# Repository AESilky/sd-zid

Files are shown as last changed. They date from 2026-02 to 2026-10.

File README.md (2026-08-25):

# ZID - Z80 In-circuit Debugger (ICD) and Single Board Computer (SBC)

The Z80 In-circuit-Debugger is intended to provide in-circuit (hardware and software) debugging functionality
for a Z80 based system.

## Features (ICD)

The debugger probe plugs in in place of the Z80. The debugger provides:

1. 20MHz operation. This allows debugging high speed boards. The actual 'top-speed' of the target depends on how tight the timing of the target board is, but debugging 16MHz targets should be handled without problems. Some boards might need the clock speed reduced for debugging.
2. Compact probe that connects via a small 40-pin FFC/FPC cable
3. Four probe configurations that allow the cable to exit in different directions (probe in different orientations)
4. Breakpoint and Single-Step hardware. Steps code and stops code execution when specified conditions are met, even with code in read-only memory (see below for details)
5. Breakpoint hardware allows checking two different conditions. For example; Port Write and Instruction Fetch
6. One breakpoint condition or the other can includes the ability to not only check the operation but also a data value, including Don't-Care bits.
7. Five breakpoint addresses total. One address on Condition A and Four addresses on Condition B (for example, a port read of a specific value with don't-care bits and 4 different instruction fetch locations)
8. Breakpoint conditions being met can either stop target code execution or simply provide a SYNC signal (can be used to trigger an oscilloscope/analyzer)
9. External breakpoint trigger allows stopping target code execution when some signal is generated externally
10. LED indicators for key Z80 control signals (WAIT, HALT, BUSACK)
11. Completely buffered/isolated target signals; meaning that:
    * Problems with the target hardware will not keep the debugger from running
    * Test features like, continuous memory or port write or read can be used to track down hardware problems or exercise new hardware
    * Z80 control signals on the target are held in an inactive state when not running target code or accessing target resources (debug mode). This can make it easier to debug target board hardware by quieting signals to allow getting an analyzer ready to capture an operation.
    * Z80 MREQ can optionally be passed to the target during refresh cycles when in debug mode (for that rare dynamic memory setup)
    * The target WAIT signal can be disconnected from the debugger to help debug hardware that is holding WAIT on
12. Switch that immediately runs the target system on boot/reset (no Debugger functionality is initialized and is not available)

## Breakpoint Conditions

The breakpoint logic allows selecting:

1. Instruction fetch from a specific address
2. Memory read from a specific address
3. Memory write to a specific address
4. Any memory operation (other than instruction fetch) on a specific address
5. Port (I/O) read from a specific address (16 or 8 bit address) or any address
6. Port write to a specific address (16 or 8 bit address) or any address
7. Any Port operation on a specific address (16 or 8 bit address) or any address
8. One breakpoint can also check for a specific data value for any operation except instruction fetch (for IF the data isn't valid soon enough, but a break could be set for Memory Read with the data value - it just breaks after the instruction execution)
9. The data value break also allows specifying Don't-Care bits. This allows breaking on a port write of a specific bit, for example.
10. 'Soft' breakpoint detection can be enabled. This allows generating a break by including a RST (8/38) in the code. When the RST is detected the hardware treats it as a break and enters Debug mode.

A fully populated ZID has:

1. One breakpoint address that uses Condition-A, that can specify a Data-Value, with Don't-Care bits
2. Four breakpoint addresses that share Condition-B (individually enabled)
3. All breakpoints are handled in hardware and don't require any modifications to the target system board or code

## High-Level Debug Monitor Description

This section provides a very high-level description of the Debug Monitor functionality. For complete information, see the ZID User Manual.

The user interface is through a USB port connected terminal (or terminal emulator).

1. Display the CPU registers
2. Set the value of CPU registers that will be used when code is run
3. Display the contents of memory
4. Modify the contents of RAM memory
5. Display data from an I/O port
6. Write data to an I/O port
7. Run code and break when one of two specified conditions are met:
   1. Breakpoint One and Two can be any of the conditions listed in the previous section, plus the ability to specify a data value that must match what is written/read, but allowing Don't-Care bits.
   2. Breakpoint Three through N (up to 8 total) share a condition that can be different from that of breakpoint One and Two.
8. Single-step code (even in ROM)
9. Perform operations that can be helpful in troubleshooting/repairing hardware problems, including:
   1. repetitive write of a specific data byte to a memory location
   2. repetitive read from a memory location
   3. repetitive write of a specific data byte to a port
   4. repetitive read from a port
   5. run a memory test using a number of different approaches (data patterns)
10. Additional functionality like:
    1. An HP-16C (like) calculator
    2. Selection of number base (Decimal, Hex, Octal, Binary (auto switches to Hex for certain operations))
    3. Entry of values in any base irrespective of the set base by using base indicators
    4. Store and recall multiple configurations that include the number base, breakpoint conditions, calculator register values, etc.

## Single Board Computer (SBC)

In addition to the Hardware Debugger, the board functions as an Single Board Computer (SBC). It's an SBC that:

1. has an MMU that bank switches 128K Flash (ROM) and 128K SRAM in 4 16K blocks (64K) from 8 regions of ROM and 8 regions of RAM.
2. none of the Debugger ROM/RAM need be available while running the SBC code (2K of Flash and 1K of RAM needs to be reserved for the Debugger from the upper region of the Flash and SRAM)
3. 4 output port bits that are available as buffered signals on a connector
4. 4 input port bits that are read from buffered signals on a connector
5. RP2040 module that provides:
   1. USB Terminal port
   2. eeprom storage
   3. RTC via I2C
   4. SD Card via SPI. The SD card can be used as CP/M disk.
6. runs at 20MHz with 0 wait states for RAM access, 1 wait state for Flash access, and 0 additional wait states for the 4-IN and 4-OUT port bits. The RP2040 modules adds various wait states depending on the operation.
7. the ability to use the debug probe cable and port I/O cable to connect to a 3 position RC2014-Z80 backplane.
   1. The RP2040 module interrupt signal can go to the backplane
   2. The backplane supports a bus-master accessing the SBC memory and ports
8. code and port operations can be completely debugged using the hardware debugger functionality without requiring any accommodations.

All of this is in a compact 3.5" x 5.0" board. The backplane is a 4.0" x 5.0" board with 3 RC2014-Z80 positions and includes a connector and port decoding for an OLED or TFT display panel. The backplane can be positioned on the same plane as the SBC or can be mouned back to back (the connecting cable makes a 'U'). Power is provided via a USB-C connection.

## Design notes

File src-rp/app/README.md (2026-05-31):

# Application (APP) functionality 

## APP

The APP consists of the display panel, rotary encoder (knob), and
attention switch. The hardware itself is under the control of the
Hardware Runtime, but the overall functionality of the interface
is controlled by this module.

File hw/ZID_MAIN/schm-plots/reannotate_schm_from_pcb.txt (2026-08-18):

Change C2 reference designator to 'C14'.
Change C8 reference designator to 'C29'.
Change C43 reference designator to 'C22'.
Change LED4 reference designator to 'LED7'.
Change J4 reference designator to 'J6'.
Change C42 reference designator to 'C19'.
Change U23 reference designator to 'U1'.
Change R16 reference designator to 'R21'.
Change R18 reference designator to 'R12'.
Change C31 reference designator to 'C3'.
Change U8 reference designator to 'U10'.
Change R39 reference designator to 'R32'.
Change C25 reference designator to 'C9'.
Change R26 reference designator to 'R17'.
Change U8 reference designator to 'U10'.
Change R11 reference designator to 'R7'.
Change C41 reference designator to 'C23'.
Change U20 reference designator to 'U14'.
Change LED2 reference designator to 'LED9'.
Change D2 reference designator to 'D4'.
Change J5 reference designator to 'J4'.
Change OP2 field 'OP-A' value to 'YES'.
Change OP2 field 'OP-B' value to 'NO'.
Change C6 reference designator to 'C28'.
Change R10 reference designator to 'R13'.
Change U24 reference designator to 'U16'.
Change R5 reference designator to 'R25'.
Change C26 reference designator to 'C11'.
Change LED10 reference designator to 'LED3'.
Change TP1 reference designator to 'TP2'.
Change R9 reference designator to 'R30'.
Change R42 reference designator to 'R37'.
Change J6 reference designator to 'J11'.
Change U10 reference designator to 'U19'.
Change C9 reference designator to 'C30'.
Change R28 reference designator to 'R20'.
Change LED3 reference designator to 'LED6'.
Change D1 reference designator to 'D3'.
Change R17 reference designator to 'R9'.
Change U11 reference designator to 'U23'.
Change J1 reference designator to 'J2'.
Change C44 reference designator to 'C37'.
Change R30 reference designator to 'R5'.
Change C39 reference designator to 'C27'.
Change U6 reference designator to 'U21'.
Change R27 reference designator to 'R19'.
Change JP1 reference designator to 'JP3'.
Change U3 reference designator to 'U4'.
Change R22 reference designator to 'R40'.
Change U24 reference designator to 'U16'.
Change LED5 reference designator to 'LED8'.
Change R8 reference designator to 'R33'.
Change C33 reference designator to 'C18'.
Change R20 reference designator to 'R39'.
Change R13 reference designator to 'R10'.
Change R14 reference designator to 'R22'.
Change R3 reference designator to 'R15'.
Change C34 reference designator to 'C16'.
Change LED6 reference designator to 'LED4'.
Change C23 reference designator to 'C4'.
Change U1 reference designator to 'U11'.
Change R6 reference designator to 'R14'.
Change C46 reference designator to 'C17'.
Change D4 reference designator to 'D1'.
Change U8 reference designator to 'U10'.
Change R37 reference designator to 'R3'.
Change U14 reference designator to 'U6'.
Change C29 reference designator to 'C24'.
Change JP2 reference designator to 'JP1'.
Change JP6 reference designator to 'JP4'.
Change H2 reference designator to 'H3'.
Change C5 reference designator to 'C2'.
Change R34 reference designator to 'R35'.
Change J3 reference designator to 'J1'.
Change D3 reference designator to 'D2'.
Change C28 reference designator to 'C33'.
Change U21 reference designator to 'U20'.
Change R2 reference designator to 'R11'.
Change TP14 reference designator to 'TP12'.
Change R29 reference designator to 'R18'.
Change R7 reference designator to 'R28'.
Change U16 reference designator to 'U24'.
Change R32 reference designator to 'R26'.
Change C45 reference designator to 'C21'.
Change U24 reference designator to 'U16'.
Change H4 reference designator to 'H2'.
Change C10 reference designator to 'C36'.
Change JP3 reference designator to 'JP2'.
Change R41 reference designator to 'R1'.
Change R23 reference designator to 'R38'.
Change U10 reference designator to 'U19'.
Change U11 reference designator to 'U23'.
Change U23 reference designator to 'U1'.
Change J14 reference designator to 'J12'.
Change TP16 reference designator to 'TP15'.
Change R21 reference designator to 'R41'.
Change R24 reference designator to 'R23'.
Change C49 reference designator to 'C12'.
Change U8 reference designator to 'U10'.
Change R35 reference designator to 'R2'.
Change U10 reference designator to 'U19'.
Change SBC1 reference designator to 'SBC2'.
Change R12 reference designator to 'R24'.
Change C7 reference designator to 'C25'.
Change LED9 reference designator to 'LED1'.
Change J11 reference designator to 'J3'.
Change U23 reference designator to 'U1'.
Change H3 reference designator to 'H4'.
Change C1 reference designator to 'C13'.
Change R38 reference designator to 'R31'.
Change TP15 reference designator to 'TP14'.
Change C22 reference designator to 'C6'.
Change R19 reference designator to 'R36'.
Change U17 reference designator to 'U8'.
Change JP7 reference designator to 'JP6'.
Change R15 reference designator to 'R8'.
Change U7 reference designator to 'U9'.
Change R31 reference designator to 'R16'.
Change C27 reference designator to 'C7'.
Change U2 reference designator to 'U17'.
Change C24 reference designator to 'C10'.
Change R33 reference designator to 'R4'.
Change C47 reference designator to 'C32'.
Change U21 reference designator to 'U20'.
Change LED8 reference designator to 'LED5'.
Change C21 reference designator to 'C5'.
Change C40 reference designator to 'C8'.
Change SBC2 reference designator to 'SBC1'.
Change R36 reference designator to 'R29'.
Change LED1 reference designator to 'LED10'.
Change R44 reference designator to 'R42'.
Change U9 reference designator to 'U7'.
Change J2 reference designator to 'J5'.
Change C50 reference designator to 'C15'.
Change U4 reference designator to 'U3'.
Change C32 reference designator to 'C20'.
Change U8 reference designator to 'U10'.
Change U11 reference designator to 'U23'.
Change U19 reference designator to 'U12'.
Change C3 reference designator to 'C38'.
Change C11 reference designator to 'C35'.
Change U23 reference designator to 'U1'.
Change C20 reference designator to 'C1'.
Change U23 reference designator to 'U1'.
Change JP4 reference designator to 'JP5'.
Change C4 reference designator to 'C34'.
Change R4 reference designator to 'R27'.
Change TP12 reference designator to 'TP1'.
Change U8 reference designator to 'U10'.
Change C48 reference designator to 'C31'.
Change R1 reference designator to 'R6'.
Change R40 reference designator to 'R34'.
Change C30 reference designator to 'C26'.
Change U21 reference designator to 'U20'.
Change LED7 reference designator to 'LED2'.
Change U12 reference designator to 'U2'.
Change U8 reference designator to 'U10'.
Change C2 reference designator to 'C14'.
Change C8 reference designator to 'C29'.
Change C43 reference designator to 'C22'.
Change LED4 reference designator to 'LED7'.
Change J4 reference designator to 'J6'.
Change C42 reference designator to 'C19'.
Change U23 reference designator to 'U1'.
Change R16 reference designator to 'R21'.
Change R18 reference designator to 'R12'.
Change C31 reference designator to 'C3'.
Change U8 reference designator to 'U10'.
Change R39 reference designator to 'R32'.
Change C25 reference designator to 'C9'.
Change R26 reference designator to 'R17'.
Change U8 reference designator to 'U10'.
Change R11 reference designator to 'R7'.
Change C41 reference designator to 'C23'.
Change U20 reference designator to 'U14'.
Change LED2 reference designator to 'LED9'.
Change D2 reference designator to 'D4'.
Change J5 reference designator to 'J4'.
Change OP2 field 'OP-A' value to 'YES'.
Change OP2 field 'OP-B' value to 'NO'.
Change C6 reference designator to 'C28'.
Change R10 reference designator to 'R13'.
Change U24 reference designator to 'U16'.
Change R5 reference designator to 'R25'.
Change C26 reference designator to 'C11'.
Change LED10 reference designator to 'LED3'.
Change TP1 reference designator to 'TP2'.
Change R9 reference designator to 'R30'.
Change R42 reference designator to 'R37'.
Change J6 reference designator to 'J11'.
Change U10 reference designator to 'U19'.
Change C9 reference designator to 'C30'.
Change R28 reference designator to 'R20'.
Change LED3 reference designator to 'LED6'.
Change D1 reference designator to 'D3'.
Change R17 reference designator to 'R9'.
Change U11 reference designator to 'U23'.
Change J1 reference designator to 'J2'.
Change C44 reference designator to 'C37'.
Change R30 reference designator to 'R5'.
Change C39 reference designator to 'C27'.
Change U6 reference designator to 'U21'.
Change R27 reference designator to 'R19'.
Change JP1 reference designator to 'JP3'.
Change U3 reference designator to 'U4'.
Change R22 reference designator to 'R40'.
Change U24 reference designator to 'U16'.
Change LED5 reference designator to 'LED8'.
Change R8 reference designator to 'R33'.
Change C33 reference designator to 'C18'.
Change R20 reference designator to 'R39'.
Change R13 reference designator to 'R10'.
Change R14 reference designator to 'R22'.
Change R3 reference designator to 'R15'.
Change C34 reference designator to 'C16'.
Change LED6 reference designator to 'LED4'.
Change C23 reference designator to 'C4'.
Change U1 reference designator to 'U11'.
Change R6 reference designator to 'R14'.
Change C46 reference designator to 'C17'.
Change D4 reference designator to 'D1'.
Change U8 reference designator to 'U10'.
Change R37 reference designator to 'R3'.
Change U14 reference designator to 'U6'.
Change C29 reference designator to 'C24'.
Change JP2 reference designator to 'JP1'.
Change JP6 reference designator to 'JP4'.
Change H2 reference designator to 'H3'.
Change C5 reference designator to 'C2'.
Change R34 reference designator to 'R35'.
Change J3 reference designator to 'J1'.
Change D3 reference designator to 'D2'.
Change C28 reference designator to 'C33'.
Change U21 reference designator to 'U20'.
Change R2 reference designator to 'R11'.
Change TP14 reference designator to 'TP12'.
Change R29 reference designator to 'R18'.
Change R7 reference designator to 'R28'.
Change U16 reference designator to 'U24'.
Change R32 reference designator to 'R26'.
Change C45 reference designator to 'C21'.
Change U24 reference designator to 'U16'.
Change H4 reference designator to 'H2'.
Change C10 reference designator to 'C36'.
Change JP3 reference designator to 'JP2'.
Change R41 reference designator to 'R1'.
Change R23 reference designator to 'R38'.
Change U10 reference designator to 'U19'.
Change U11 reference designator to 'U23'.
Change U23 reference designator to 'U1'.
Change J14 reference designator to 'J12'.
Change TP16 reference designator to 'TP15'.
Change R21 reference designator to 'R41'.
Change R24 reference designator to 'R23'.
Change C49 reference designator to 'C12'.
Change U8 reference designator to 'U10'.
Change R35 reference designator to 'R2'.
Change U10 reference designator to 'U19'.
Change SBC1 reference designator to 'SBC2'.
Change R12 reference designator to 'R24'.
Change C7 reference designator to 'C25'.
Change LED9 reference designator to 'LED1'.
Change J11 reference designator to 'J3'.
Change U23 reference designator to 'U1'.
Change H3 reference designator to 'H4'.
Change C1 reference designator to 'C13'.
Change R38 reference designator to 'R31'.
Change TP15 reference designator to 'TP14'.
Change C22 reference designator to 'C6'.
Change R19 reference designator to 'R36'.
Change U17 reference designator to 'U8'.
Change JP7 reference designator to 'JP6'.
Change R15 reference designator to 'R8'.
Change U7 reference designator to 'U9'.
Change R31 reference designator to 'R16'.
Change C27 reference designator to 'C7'.
Change U2 reference designator to 'U17'.
Change C24 reference designator to 'C10'.
Change R33 reference designator to 'R4'.
Change C47 reference designator to 'C32'.
Change U21 reference designator to 'U20'.
Change LED8 reference designator to 'LED5'.
Change C21 reference designator to 'C5'.
Change C40 reference designator to 'C8'.
Change SBC2 reference designator to 'SBC1'.
Change R36 reference designator to 'R29'.
Change LED1 reference designator to 'LED10'.
Change R44 reference designator to 'R42'.
Change U9 reference designator to 'U7'.
Change J2 reference designator to 'J5'.
Change C50 reference designator to 'C15'.
Change U4 reference designator to 'U3'.
Change C32 reference designator to 'C20'.
Change U8 reference designator to 'U10'.
Change U11 reference designator to 'U23'.
Change U19 reference designator to 'U12'.
Change C3 reference designator to 'C38'.
Change C11 reference designator to 'C35'.
Change U23 reference designator to 'U1'.
Change C20 reference designator to 'C1'.
Change U23 reference designator to 'U1'.
Change JP4 reference designator to 'JP5'.
Change C4 reference designator to 'C34'.
Change R4 reference designator to 'R27'.
Change TP12 reference designator to 'TP1'.
Change U8 reference designator to 'U10'.
Change C48 reference designator to 'C31'.
Change R1 reference designator to 'R6'.
Change R40 reference designator to 'R34'.
Change C30 reference designator to 'C26'.
Change U21 reference designator to 'U20'.
Change LED7 reference designator to 'LED2'.
Change U12 reference designator to 'U2'.
Change U8 reference designator to 'U10'.

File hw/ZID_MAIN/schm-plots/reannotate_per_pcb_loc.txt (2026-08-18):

Info: <br/><br/>Front Footprints<br/>*********** Sort on Footprint Coordinates ***********<br/>1 H1 X, Y: 2.4524 in, 5.5600 in; rounded X, Y: 2.0000 in, 6.0000 in<br/>2 LED9 X, Y: 2.9274 in, 5.5900 in; rounded X, Y: 3.0000 in, 6.0000 in<br/>3 LED7 X, Y: 3.1774 in, 5.5900 in; rounded X, Y: 3.0000 in, 6.0000 in<br/>4 LED10 X, Y: 2.6774 in, 5.5900 in; rounded X, Y: 3.0000 in, 6.0000 in<br/>5 LED6 X, Y: 2.8024 in, 5.5900 in; rounded X, Y: 3.0000 in, 6.0000 in<br/>6 LED8 X, Y: 3.0524 in, 5.5900 in; rounded X, Y: 3.0000 in, 6.0000 in<br/>7 C20 X, Y: 3.6967 in, 5.6221 in; rounded X, Y: 4.0000 in, 6.0000 in<br/>8 LED3 X, Y: 5.8524 in, 5.5900 in; rounded X, Y: 6.0000 in, 6.0000 in<br/>9 LED4 X, Y: 5.7274 in, 5.5900 in; rounded X, Y: 6.0000 in, 6.0000 in<br/>10 LED5 X, Y: 5.6024 in, 5.5900 in; rounded X, Y: 6.0000 in, 6.0000 in<br/>11 LED2 X, Y: 5.9774 in, 5.5900 in; rounded X, Y: 6.0000 in, 6.0000 in<br/>12 LED1 X, Y: 6.1024 in, 5.5900 in; rounded X, Y: 6.0000 in, 6.0000 in<br/>13 SD1 X, Y: 6.5324 in, 5.6100 in; rounded X, Y: 7.0000 in, 6.0000 in<br/>14 H4 X, Y: 7.1724 in, 5.5600 in; rounded X, Y: 7.0000 in, 6.0000 in<br/>15 C5 X, Y: 3.2230 in, 5.2300 in; rounded X, Y: 3.0000 in, 5.0000 in<br/>16 SPARE1 X, Y: 3.4624 in, 4.9600 in; rounded X, Y: 3.0000 in, 5.0000 in<br/>17 R41 X, Y: 2.6774 in, 5.3400 in; rounded X, Y: 3.0000 in, 5.0000 in<br/>18 R35 X, Y: 3.0524 in, 5.3400 in; rounded X, Y: 3.0000 in, 5.0000 in<br/>19 U23 X, Y: 3.4224 in, 5.4800 in; rounded X, Y: 3.0000 in, 5.0000 in<br/>20 C31 X, Y: 2.6364 in, 5.1656 in; rounded X, Y: 3.0000 in, 5.0000 in<br/>21 R37 X, Y: 2.9274 in, 5.3400 in; rounded X, Y: 3.0000 in, 5.0000 in<br/>22 R33 X, Y: 3.1774 in, 5.3400 in; rounded X, Y: 3.0000 in, 5.0000 in<br/>23 R30 X, Y: 2.8024 in, 5.3400 in; rounded X, Y: 3.0000 in, 5.0000 in<br/>24 C23 X, Y: 4.0103 in, 5.1630 in; rounded X, Y: 4.0000 in, 5.0000 in<br/>25 C21 X, Y: 3.9571 in, 5.4642 in; rounded X, Y: 4.0000 in, 5.0000 in<br/>26 C22 X, Y: 4.3824 in, 5.3872 in; rounded X, Y: 4.0000 in, 5.0000 in<br/>27 G*** X, Y: 4.3394 in, 5.1947 in; rounded X, Y: 4.0000 in, 5.0000 in<br/>28 C27 X, Y: 4.7587 in, 4.9111 in; rounded X, Y: 5.0000 in, 5.0000 in<br/>29 C40 X, Y: 5.2135 in, 4.8531 in; rounded X, Y: 5.0000 in, 5.0000 in<br/>30 C25 X, Y: 5.3097 in, 5.2709 in; rounded X, Y: 5.0000 in, 5.0000 in<br/>31 C24 X, Y: 5.0798 in, 5.4744 in; rounded X, Y: 5.0000 in, 5.0000 in<br/>32 C26 X, Y: 5.2626 in, 5.1640 in; rounded X, Y: 5.0000 in, 5.0000 in<br/>33 C49 X, Y: 6.1830 in, 5.0900 in; rounded X, Y: 6.0000 in, 5.0000 in<br/>34 C1 X, Y: 6.3224 in, 4.6500 in; rounded X, Y: 6.0000 in, 5.0000 in<br/>35 R1 X, Y: 6.2824 in, 4.8500 in; rounded X, Y: 6.0000 in, 5.0000 in<br/>36 R11 X, Y: 6.1024 in, 5.3359 in; rounded X, Y: 6.0000 in, 5.0000 in<br/>37 R15 X, Y: 5.8524 in, 5.3359 in; rounded X, Y: 6.0000 in, 5.0000 in<br/>38 R17 X, Y: 5.7274 in, 5.3359 in; rounded X, Y: 6.0000 in, 5.0000 in<br/>39 JP2 X, Y: 6.2824 in, 4.9400 in; rounded X, Y: 6.0000 in, 5.0000 in<br/>40 R13 X, Y: 5.9774 in, 5.3359 in; rounded X, Y: 6.0000 in, 5.0000 in<br/>41 C2 X, Y: 6.4224 in, 4.9300 in; rounded X, Y: 6.0000 in, 5.0000 in<br/>42 U12 X, Y: 5.8524 in, 4.9700 in; rounded X, Y: 6.0000 in, 5.0000 in<br/>43 R2 X, Y: 6.4624 in, 4.5100 in; rounded X, Y: 6.0000 in, 5.0000 in<br/>44 R18 X, Y: 5.6024 in, 5.3359 in; rounded X, Y: 6.0000 in, 5.0000 in<br/>45 J3 X, Y: 7.1874 in, 5.0300 in; rounded X, Y: 7.0000 in, 5.0000 in<br/>46 U4 X, Y: 7.1324 in, 4.7450 in; rounded X, Y: 7.0000 in, 5.0000 in<br/>47 SW1 X, Y: 7.1324 in, 5.2600 in; rounded X, Y: 7.0000 in, 5.0000 in<br/>48 J1 X, Y: 6.9100 in, 4.9650 in; rounded X, Y: 7.0000 in, 5.0000 in<br/>49 R10 X, Y: 6.9774 in, 5.4600 in; rounded X, Y: 7.0000 in, 5.0000 in<br/>50 C50 X, Y: 6.7224 in, 5.0100 in; rounded X, Y: 7.0000 in, 5.0000 in<br/>51 R6 X, Y: 6.5524 in, 4.9600 in; rounded X, Y: 7.0000 in, 5.0000 in<br/>52 U3 X, Y: 6.5024 in, 4.7100 in; rounded X, Y: 7.0000 in, 5.0000 in<br/>53 R3 X, Y: 6.6124 in, 4.5100 in; rounded X, Y: 7.0000 in, 5.0000 in<br/>54 RN1 X, Y: 2.5774 in, 3.8600 in; rounded X, Y: 3.0000 in, 4.0000 in<br/>55 RN2 X, Y: 3.4774 in, 3.5600 in; rounded X, Y: 3.0000 in, 4.0000 in<br/>56 U5 X, Y: 2.7274 in, 3.5600 in; rounded X, Y: 3.0000 in, 4.0000 in<br/>57 U14 X, Y: 3.8774 in, 4.1700 in; rounded X, Y: 4.0000 in, 4.0000 in<br/>58 C34 X, Y: 5.3939 in, 3.9338 in; rounded X, Y: 5.0000 in, 4.0000 in<br/>59 R31 X, Y: 5.1144 in, 3.5420 in; rounded X, Y: 5.0000 in, 4.0000 in<br/>60 DBOPT1 X, Y: 5.2594 in, 4.1073 in; rounded X, Y: 5.0000 in, 4.0000 in<br/>61 U9 X, Y: 4.7274 in, 3.8350 in; rounded X, Y: 5.0000 in, 4.0000 in<br/>62 R26 X, Y: 5.7824 in, 3.9338 in; rounded X, Y: 6.0000 in, 4.0000 in<br/>63 J11 X, Y: 5.5124 in, 4.1000 in; rounded X, Y: 6.0000 in, 4.0000 in<br/>64 R29 X, Y: 5.7824 in, 3.6838 in; rounded X, Y: 6.0000 in, 4.0000 in<br/>65 R27 X, Y: 5.7824 in, 4.0588 in; rounded X, Y: 6.0000 in, 4.0000 in<br/>66 C46 X, Y: 6.3231 in, 3.7421 in; rounded X, Y: 6.0000 in, 4.0000 in<br/>67 R28 X, Y: 5.7824 in, 3.8088 in; rounded X, Y: 6.0000 in, 4.0000 in<br/>68 C33 X, Y: 7.0336 in, 3.6655 in; rounded X, Y: 7.0000 in, 4.0000 in<br/>69 C42 X, Y: 6.8790 in, 4.0786 in; rounded X, Y: 7.0000 in, 4.0000 in<br/>70 C32 X, Y: 6.7511 in, 3.5126 in; rounded X, Y: 7.0000 in, 4.0000 in<br/>71 C45 X, Y: 6.5858 in, 4.0404 in; rounded X, Y: 7.0000 in, 4.0000 in<br/>72 C43 X, Y: 6.8074 in, 4.2393 in; rounded X, Y: 7.0000 in, 4.0000 in<br/>73 C41 X, Y: 6.9627 in, 3.9760 in; rounded X, Y: 7.0000 in, 4.0000 in<br/>74 SBC2 X, Y: 2.4113 in, 2.7300 in; rounded X, Y: 2.0000 in, 3.0000 in<br/>75 SBC1 X, Y: 2.4100 in, 2.6100 in; rounded X, Y: 2.0000 in, 3.0000 in<br/>76 SBC3 X, Y: 2.4100 in, 2.8500 in; rounded X, Y: 2.0000 in, 3.0000 in<br/>77 TP12 X, Y: 2.4494 in, 3.3530 in; rounded X, Y: 2.0000 in, 3.0000 in<br/>78 JP3 X, Y: 2.8350 in, 2.8500 in; rounded X, Y: 3.0000 in, 3.0000 in<br/>79 R16 X, Y: 2.5600 in, 3.0100 in; rounded X, Y: 3.0000 in, 3.0000 in<br/>80 TP1 X, Y: 2.7124 in, 3.0100 in; rounded X, Y: 3.0000 in, 3.0000 in<br/>81 JP1 X, Y: 2.8350 in, 2.7300 in; rounded X, Y: 3.0000 in, 3.0000 in<br/>82 U17 X, Y: 3.0924 in, 3.2750 in; rounded X, Y: 3.0000 in, 3.0000 in<br/>83 J5 X, Y: 3.1024 in, 3.0100 in; rounded X, Y: 3.0000 in, 3.0000 in<br/>84 C29 X, Y: 2.9059 in, 3.0170 in; rounded X, Y: 3.0000 in, 3.0000 in<br/>85 U7 X, Y: 4.3774 in, 2.6100 in; rounded X, Y: 4.0000 in, 3.0000 in<br/>86 U8 X, Y: 4.4024 in, 3.0324 in; rounded X, Y: 4.0000 in, 3.0000 in<br/>87 R14 X, Y: 4.2104 in, 2.7830 in; rounded X, Y: 4.0000 in, 3.0000 in<br/>88 OP1 X, Y: 4.1024 in, 2.8813 in; rounded X, Y: 4.0000 in, 3.0000 in<br/>89 C7 X, Y: 4.1436 in, 3.4589 in; rounded X, Y: 4.0000 in, 3.0000 in<br/>90 TP3 X, Y: 4.3279 in, 2.8398 in; rounded X, Y: 4.0000 in, 3.0000 in<br/>91 C30 X, Y: 3.5574 in, 3.3534 in; rounded X, Y: 4.0000 in, 3.0000 in<br/>92 U1 X, Y: 3.8124 in, 2.5200 in; rounded X, Y: 4.0000 in, 3.0000 in<br/>93 TP7 X, Y: 4.4038 in, 2.8349 in; rounded X, Y: 4.0000 in, 3.0000 in<br/>94 U19 X, Y: 3.8284 in, 3.2750 in; rounded X, Y: 4.0000 in, 3.0000 in<br/>95 U13 X, Y: 5.3274 in, 2.6100 in; rounded X, Y: 5.0000 in, 3.0000 in<br/>96 C39 X, Y: 5.0751 in, 3.0220 in; rounded X, Y: 5.0000 in, 3.0000 in<br/>97 U20 X, Y: 4.8524 in, 3.0350 in; rounded X, Y: 5.0000 in, 3.0000 in<br/>98 OP2 X, Y: 5.2924 in, 3.4850 in; rounded X, Y: 5.0000 in, 3.0000 in<br/>99 R24 X, Y: 4.9624 in, 3.3400 in; rounded X, Y: 5.0000 in, 3.0000 in<br/>100 C6 X, Y: 4.6274 in, 3.3326 in; rounded X, Y: 5.0000 in, 3.0000 in<br/>101 U24 X, Y: 5.3274 in, 3.0350 in; rounded X, Y: 5.0000 in, 3.0000 in<br/>102 U2 X, Y: 4.8524 in, 2.6100 in; rounded X, Y: 5.0000 in, 3.0000 in<br/>103 C8 X, Y: 5.4490 in, 3.4941 in; rounded X, Y: 5.0000 in, 3.0000 in<br/>104 R12 X, Y: 5.7774 in, 2.8350 in; rounded X, Y: 6.0000 in, 3.0000 in<br/>105 U10 X, Y: 6.3274 in, 2.9600 in; rounded X, Y: 6.0000 in, 3.0000 in<br/>106 C9 X, Y: 5.5560 in, 2.7058 in; rounded X, Y: 6.0000 in, 3.0000 in<br/>107 U21 X, Y: 6.4530 in, 3.2480 in; rounded X, Y: 6.0000 in, 3.0000 in<br/>108 C48 X, Y: 5.7124 in, 3.1800 in; rounded X, Y: 6.0000 in, 3.0000 in<br/>109 U6 X, Y: 6.0274 in, 3.2737 in; rounded X, Y: 6.0000 in, 3.0000 in<br/>110 C47 X, Y: 6.6384 in, 2.5620 in; rounded X, Y: 7.0000 in, 3.0000 in<br/>111 U11 X, Y: 6.6254 in, 3.2458 in; rounded X, Y: 7.0000 in, 3.0000 in<br/>112 R5 X, Y: 6.8465 in, 3.0100 in; rounded X, Y: 7.0000 in, 3.0000 in<br/>113 R32 X, Y: 7.1594 in, 2.5740 in; rounded X, Y: 7.0000 in, 3.0000 in<br/>114 R4 X, Y: 6.8465 in, 2.8100 in; rounded X, Y: 7.0000 in, 3.0000 in<br/>115 J2 X, Y: 7.0524 in, 3.1162 in; rounded X, Y: 7.0000 in, 3.0000 in<br/>116 R7 X, Y: 6.8465 in, 2.9100 in; rounded X, Y: 7.0000 in, 3.0000 in<br/>117 J4 X, Y: 6.6424 in, 2.8100 in; rounded X, Y: 7.0000 in, 3.0000 in<br/>118 SW2 X, Y: 2.4049 in, 2.2105 in; rounded X, Y: 2.0000 in, 2.0000 in<br/>119 H2 X, Y: 2.4524 in, 1.8400 in; rounded X, Y: 2.0000 in, 2.0000 in<br/>120 TP14 X, Y: 2.8100 in, 1.7600 in; rounded X, Y: 3.0000 in, 2.0000 in<br/>121 R36 X, Y: 3.0800 in, 2.0200 in; rounded X, Y: 3.0000 in, 2.0000 in<br/>122 R9 X, Y: 2.6724 in, 2.4800 in; rounded X, Y: 3.0000 in, 2.0000 in<br/>123 C28 X, Y: 3.1024 in, 2.5000 in; rounded X, Y: 3.0000 in, 2.0000 in<br/>124 R38 X, Y: 3.0800 in, 2.3200 in; rounded X, Y: 3.0000 in, 2.0000 in<br/>125 TP15 X, Y: 2.6600 in, 1.7600 in; rounded X, Y: 3.0000 in, 2.0000 in<br/>126 R39 X, Y: 3.0800 in, 2.2200 in; rounded X, Y: 3.0000 in, 2.0000 in<br/>127 R8 X, Y: 3.0814 in, 2.3990 in; rounded X, Y: 3.0000 in, 2.0000 in<br/>128 R40 X, Y: 3.0800 in, 2.1200 in; rounded X, Y: 3.0000 in, 2.0000 in<br/>129 C4 X, Y: 3.3820 in, 2.0993 in; rounded X, Y: 3.0000 in, 2.0000 in<br/>130 J7 X, Y: 3.2100 in, 1.9100 in; rounded X, Y: 3.0000 in, 2.0000 in<br/>131 OP3 X, Y: 2.9300 in, 2.2700 in; rounded X, Y: 3.0000 in, 2.0000 in<br/>132 TP16 X, Y: 2.9600 in, 1.7600 in; rounded X, Y: 3.0000 in, 2.0000 in<br/>133 J8 X, Y: 3.6100 in, 1.9100 in; rounded X, Y: 4.0000 in, 2.0000 in<br/>134 C11 X, Y: 4.0744 in, 2.4476 in; rounded X, Y: 4.0000 in, 2.0000 in<br/>135 R34 X, Y: 3.9774 in, 2.1850 in; rounded X, Y: 4.0000 in, 2.0000 in<br/>136 R19 X, Y: 4.3253 in, 2.0600 in; rounded X, Y: 4.0000 in, 2.0000 in<br/>137 JP6 X, Y: 4.2106 in, 2.1700 in; rounded X, Y: 4.0000 in, 2.0000 in<br/>138 R42 X, Y: 4.0774 in, 2.1850 in; rounded X, Y: 4.0000 in, 2.0000 in<br/>139 R23 X, Y: 3.8774 in, 2.1850 in; rounded X, Y: 4.0000 in, 2.0000 in<br/>140 J9 X, Y: 3.8100 in, 1.9100 in; rounded X, Y: 4.0000 in, 2.0000 in<br/>141 U16 X, Y: 3.6024 in, 2.2600 in; rounded X, Y: 4.0000 in, 2.0000 in<br/>142 D4 X, Y: 4.2322 in, 1.8448 in; rounded X, Y: 4.0000 in, 2.0000 in<br/>143 R20 X, Y: 4.8824 in, 2.1000 in; rounded X, Y: 5.0000 in, 2.0000 in<br/>144 C10 X, Y: 4.6835 in, 2.4003 in; rounded X, Y: 5.0000 in, 2.0000 in<br/>145 R22 X, Y: 4.6924 in, 2.1000 in; rounded X, Y: 5.0000 in, 2.0000 in<br/>146 C44 X, Y: 5.1911 in, 2.3779 in; rounded X, Y: 5.0000 in, 2.0000 in<br/>147 R21 X, Y: 4.7724 in, 2.1000 in; rounded X, Y: 5.0000 in, 2.0000 in<br/>148 J10 X, Y: 4.8124 in, 1.8772 in; rounded X, Y: 5.0000 in, 2.0000 in<br/>149 JP4 X, Y: 5.4224 in, 1.8294 in; rounded X, Y: 5.0000 in, 2.0000 in<br/>150 D3 X, Y: 5.4187 in, 2.0499 in; rounded X, Y: 5.0000 in, 2.0000 in<br/>151 D1 X, Y: 5.5724 in, 1.7500 in; rounded X, Y: 6.0000 in, 2.0000 in<br/>152 J6 X, Y: 5.5824 in, 1.8600 in; rounded X, Y: 6.0000 in, 2.0000 in<br/>153 M1 X, Y: 6.1024 in, 2.4200 in; rounded X, Y: 6.0000 in, 2.0000 in<br/>154 R44 X, Y: 7.1524 in, 2.0800 in; rounded X, Y: 7.0000 in, 2.0000 in<br/>155 D2 X, Y: 6.8824 in, 2.2400 in; rounded X, Y: 7.0000 in, 2.0000 in<br/>156 J14 X, Y: 6.8224 in, 1.8000 in; rounded X, Y: 7.0000 in, 2.0000 in<br/>157 JP7 X, Y: 6.7274 in, 2.0810 in; rounded X, Y: 7.0000 in, 2.0000 in<br/>158 C3 X, Y: 6.8824 in, 2.4700 in; rounded X, Y: 7.0000 in, 2.0000 in<br/>159 H3 X, Y: 7.1724 in, 1.8400 in; rounded X, Y: 7.0000 in, 2.0000 in
Info: <br/><br/>Back Footprints<br/>*********** Sort on Footprint Coordinates ***********<br/>1 TP17 X, Y: 4.8584 in, 5.6360 in; rounded X, Y: 5.0000 in, 6.0000 in<br/>2 TP6 X, Y: 5.2722 in, 5.6089 in; rounded X, Y: 5.0000 in, 6.0000 in<br/>3 TP25 X, Y: 4.8294 in, 4.8190 in; rounded X, Y: 5.0000 in, 5.0000 in<br/>4 TP19 X, Y: 4.7164 in, 5.0030 in; rounded X, Y: 5.0000 in, 5.0000 in<br/>5 TP18 X, Y: 5.4554 in, 5.3540 in; rounded X, Y: 5.0000 in, 5.0000 in<br/>6 U15 X, Y: 5.0622 in, 5.2089 in; rounded X, Y: 5.0000 in, 5.0000 in<br/>7 TP24 X, Y: 5.2722 in, 4.7889 in; rounded X, Y: 5.0000 in, 5.0000 in<br/>8 TP23 X, Y: 4.5822 in, 5.2789 in; rounded X, Y: 5.0000 in, 5.0000 in<br/>9 TP21 X, Y: 5.4622 in, 4.9589 in; rounded X, Y: 5.0000 in, 5.0000 in<br/>10 TP13 X, Y: 4.4569 in, 5.0733 in; rounded X, Y: 4.0000 in, 5.0000 in<br/>11 TP22 X, Y: 3.7229 in, 5.2866 in; rounded X, Y: 4.0000 in, 5.0000 in<br/>12 U22 X, Y: 4.0324 in, 5.3200 in; rounded X, Y: 4.0000 in, 5.0000 in<br/>13 TP20 X, Y: 4.2534 in, 5.0600 in; rounded X, Y: 4.0000 in, 5.0000 in<br/>14 TP5 X, Y: 7.2224 in, 4.0800 in; rounded X, Y: 7.0000 in, 4.0000 in<br/>15 TP4 X, Y: 7.2224 in, 4.1900 in; rounded X, Y: 7.0000 in, 4.0000 in<br/>16 U18 X, Y: 6.7424 in, 3.9400 in; rounded X, Y: 7.0000 in, 4.0000 in<br/>17 TP8 X, Y: 6.1524 in, 3.7100 in; rounded X, Y: 6.0000 in, 4.0000 in<br/>18 TP9 X, Y: 6.1994 in, 3.6410 in; rounded X, Y: 6.0000 in, 4.0000 in<br/>19 TP11 X, Y: 6.9844 in, 3.4270 in; rounded X, Y: 7.0000 in, 3.0000 in<br/>20 TP10 X, Y: 7.0644 in, 3.4280 in; rounded X, Y: 7.0000 in, 3.0000 in
Info: <br/>There are 18 reference designator prefixes in use<br/>**********************************************************<br/>TP U H LED C SD SPARE R G*** JP J SW RN DBOPT SBC OP<br/>D M <br/><br/>Change Array
Info: ***********************<br/>C1 -> C13   
Info: C2 -> C14   
Info: C3 -> C38   
Info: C4 -> C34   
Info: C5 -> C2   
Info: C6 -> C28   
Info: C7 -> C25   
Info: C8 -> C29   
Info: C9 -> C30   
Info: C10 -> C36   
Info: C11 -> C35   
Info: C20 -> C1   
Info: C21 -> C5   
Info: C22 -> C6   
Info: C23 -> C4   
Info: C24 -> C10   
Info: C25 -> C9   
Info: C26 -> C11   
Info: C27 -> C7   
Info: C28 -> C33   
Info: C29 -> C24   
Info: C30 -> C26   
Info: C31 -> C3   
Info: C32 -> C20   
Info: C33 -> C18   
Info: C34 -> C16   
Info: C39 -> C27   
Info: C40 -> C8   
Info: C41 -> C23   
Info: C42 -> C19   
Info: C43 -> C22   
Info: C44 -> C37   
Info: C45 -> C21   
Info: C46 -> C17   
Info: C47 -> C32   
Info: C48 -> C31   
Info: C49 -> C12   
Info: C50 -> C15   
Info: D1 -> D3   
Info: D2 -> D4   
Info: D3 -> D2   
Info: D4 -> D1   
Info: DBOPT1 -> DBOPT1   
Info: G*** -> G***1   
Info: H1 -> H1   
Info: H2 -> H3   
Info: H3 -> H4   
Info: H4 -> H2   
Info: J1 -> J2   
Info: J2 -> J5   
Info: J3 -> J1   
Info: J4 -> J6   
Info: J5 -> J4   
Info: J6 -> J11   
Info: J7 -> J7   
Info: J8 -> J8   
Info: J9 -> J9   
Info: J10 -> J10   
Info: J11 -> J3   
Info: J14 -> J12   
Info: JP1 -> JP3   
Info: JP2 -> JP1   
Info: JP3 -> JP2   
Info: JP4 -> JP5   
Info: JP6 -> JP4   
Info: JP7 -> JP6   
Info: LED1 -> LED10   
Info: LED2 -> LED9   
Info: LED3 -> LED6   
Info: LED4 -> LED7   
Info: LED5 -> LED8   
Info: LED6 -> LED4   
Info: LED7 -> LED2   
Info: LED8 -> LED5   
Info: LED9 -> LED1   
Info: LED10 -> LED3   
Info: M1 -> M1   
Info: OP1 -> OP1   
Info: OP2 -> OP2   
Info: OP3 -> OP3   
Info: R1 -> R6   
Info: R2 -> R11   
Info: R3 -> R15   
Info: R4 -> R27   
Info: R5 -> R25   
Info: R6 -> R14   
Info: R7 -> R28   
Info: R8 -> R33   
Info: R9 -> R30   
Info: R10 -> R13   
Info: R11 -> R7   
Info: R12 -> R24   
Info: R13 -> R10   
Info: R14 -> R22   
Info: R15 -> R8   
Info: R16 -> R21   
Info: R17 -> R9   
Info: R18 -> R12   
Info: R19 -> R36   
Info: R20 -> R39   
Info: R21 -> R41   
Info: R22 -> R40   
Info: R23 -> R38   
Info: R24 -> R23   
Info: R26 -> R17   
Info: R27 -> R19   
Info: R28 -> R20   
Info: R29 -> R18   
Info: R30 -> R5   
Info: R31 -> R16   
Info: R32 -> R26   
Info: R33 -> R4   
Info: R34 -> R35   
Info: R35 -> R2   
Info: R36 -> R29   
Info: R37 -> R3   
Info: R38 -> R31   
Info: R39 -> R32   
Info: R40 -> R34   
Info: R41 -> R1   
Info: R42 -> R37   
Info: R44 -> R42   
Info: RN1 -> RN1   
Info: RN2 -> RN2   
Info: SBC1 -> SBC2   
Info: SBC2 -> SBC1   
Info: SBC3 -> SBC3   
Info: SD1 -> SD1   
Info: SPARE1 -> SPARE1   
Info: SW1 -> SW1   
Info: SW2 -> SW2   
Info: TP1 -> TP2   
Info: TP3 -> TP3   
Info: TP4 -> TP4  Excluded (will be ignored)
Info: TP5 -> TP5  Excluded (will be ignored)
Info: TP6 -> TP6  Excluded (will be ignored)
Info: TP7 -> TP7   
Info: TP8 -> TP8  Excluded (will be ignored)
Info: TP9 -> TP9  Excluded (will be ignored)
Info: TP10 -> TP10  Excluded (will be ignored)
Info: TP11 -> TP11  Excluded (will be ignored)
Info: TP12 -> TP1   
Info: TP13 -> TP13  Excluded (will be ignored)
Info: TP14 -> TP12   
Info: TP15 -> TP14   
Info: TP16 -> TP15   
Info: TP17 -> TP17  Excluded (will be ignored)
Info: TP18 -> TP18  Excluded (will be ignored)
Info: TP19 -> TP19  Excluded (will be ignored)
Info: TP20 -> TP20  Excluded (will be ignored)
Info: TP21 -> TP21  Excluded (will be ignored)
Info: TP22 -> TP22  Excluded (will be ignored)
Info: TP23 -> TP23  Excluded (will be ignored)
Info: TP24 -> TP24  Excluded (will be ignored)
Info: TP25 -> TP25  Excluded (will be ignored)
Info: U1 -> U11   
Info: U2 -> U17   
Info: U3 -> U4   
Info: U4 -> U3   
Info: U5 -> U5   
Info: U6 -> U21   
Info: U7 -> U9   
Info: U8 -> U10   
Info: U9 -> U7   
Info: U10 -> U19   
Info: U11 -> U23   
Info: U12 -> U2   
Info: U13 -> U13   
Info: U14 -> U6   
Info: U15 -> U15  Excluded (will be ignored)
Info: U16 -> U24   
Info: U17 -> U8   
Info: U18 -> U18  Excluded (will be ignored)
Info: U19 -> U12   
Info: U20 -> U14   
Info: U21 -> U20   
Info: U22 -> U22  Excluded (will be ignored)
Info: U23 -> U1   
Info: U24 -> U16   
PCB successfully reannotated
Warning: PCB annotation changes should be synchronized with schematic using the "Update Schematic from PCB" tool.

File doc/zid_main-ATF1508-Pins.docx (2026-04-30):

p b

b b r c r

a a b c f r k

e b e b m r b p a a m d h

n a n a 1 d u u d d t r m _ w

_ _ _ _ _ _ s _ d d w _ w b _ r

c c c c G V c r r c G r r a V c t _ d f

l l l l d N r d d C l s e l N 1 1 i C l r i e s

r r k k 7 D d 3 2 C k t q k D 5 4 t C k q n t h

+------------------------------------------------------------------------------+

| 100 99 98 97 96 95 94 93 92 91 90 89 88 87 86 85 84 83 82 81 80 79 78 77 76 |

mod_sel| 1 75 |mreq

tnmi| 2 74 |GND

VCC| 3 73 |TDO

TDI| 4 72 |tgtmode

d0| 5 71 |brk_dtctd

brkn_a_eq| 6 70 |zrst

tgt_go| 7 69 |zint

tint| 8 68 |d7bo

tgt_only| 9 67 |

zbusack| 10 66 |VCC

GND| 11 65 |attn

rra0| 12 ATF1508 64 |iorq

rra1| 13 100-Lead TQFP 63 |sbcmode

rra2| 14 62 |TCK

TMS| 15 61 |tdbus_in

d1| 16 60 |sbc_gp0

addr0| 17 59 |GND

VCC| 18 58 |sbc_gp1

addr1| 19 57 |sbc_gp2

addr2| 20 56 |sbc_gp3

addr3| 21 55 |sbc_gp4

addr4| 22 54 |sbc_gp5

addr5| 23 53 |sbc_gp6

addr6| 24 52 |sbc_gp7

addr7| 25 51 |VCC

| 26 27 28 29 30 31 32 33 34 35 36 37 38 39 40 41 42 43 44 45 46 47 48 49 50 |

+------------------------------------------------------------------------------+

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

N a o 6 5 4 c o C g r r N C 1 c f N r e c n d b w

D m m _ p C t k D C l m D s m b m b u a

_ _ l _ _ 1 _ r t _ u i u s i

s s a n n _ i o s s r t

e e t o o a o p _ _ e

l l c w w _ f e q

h e s n

q e

l

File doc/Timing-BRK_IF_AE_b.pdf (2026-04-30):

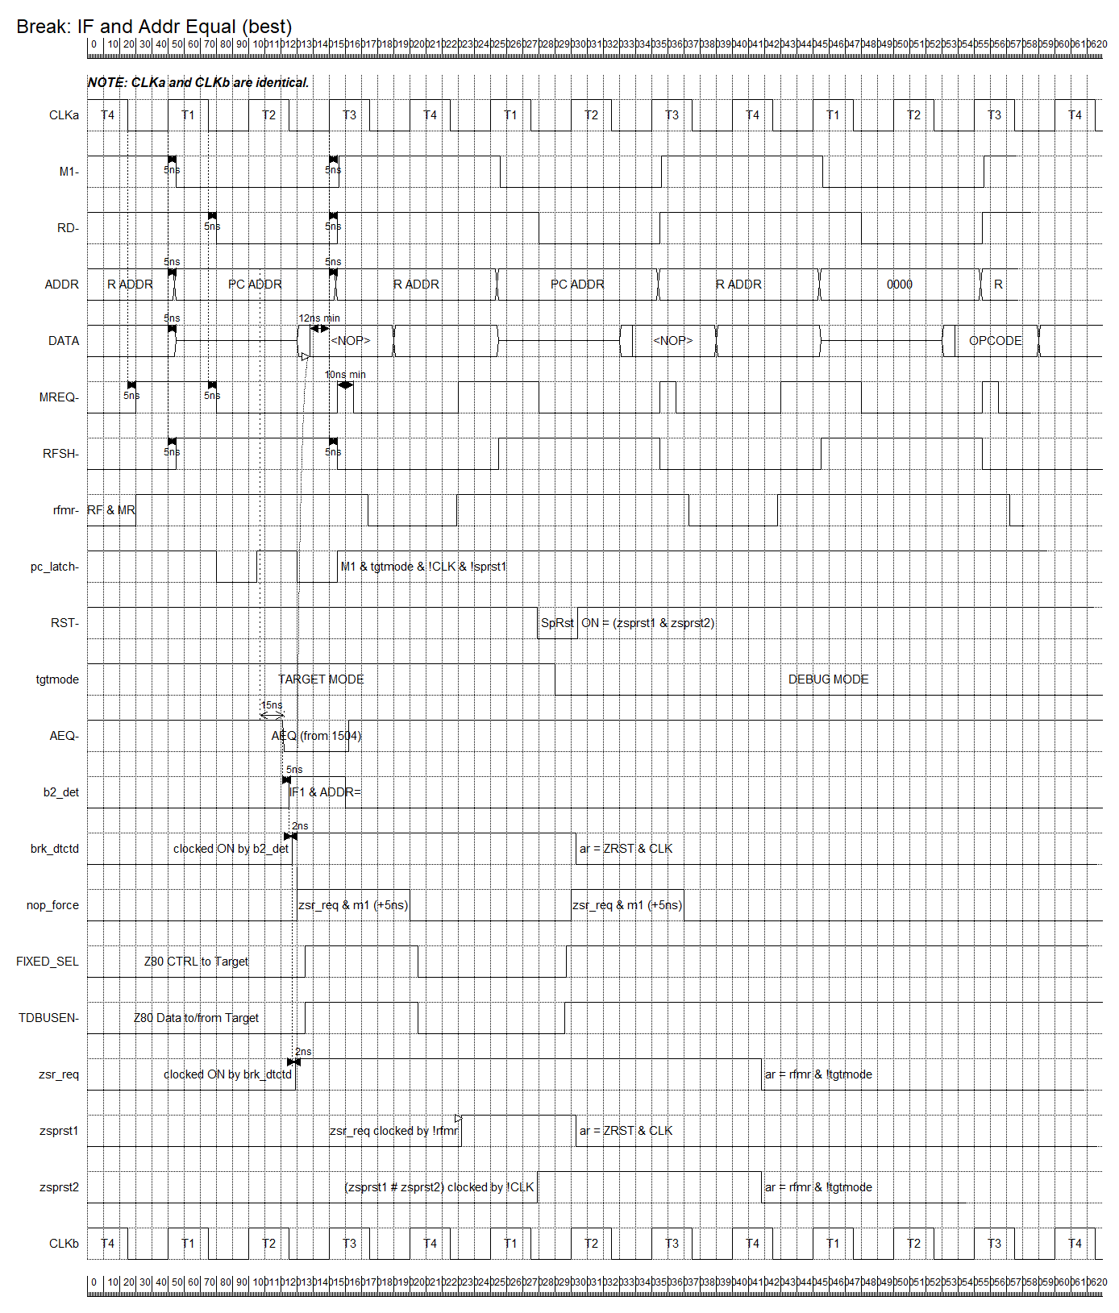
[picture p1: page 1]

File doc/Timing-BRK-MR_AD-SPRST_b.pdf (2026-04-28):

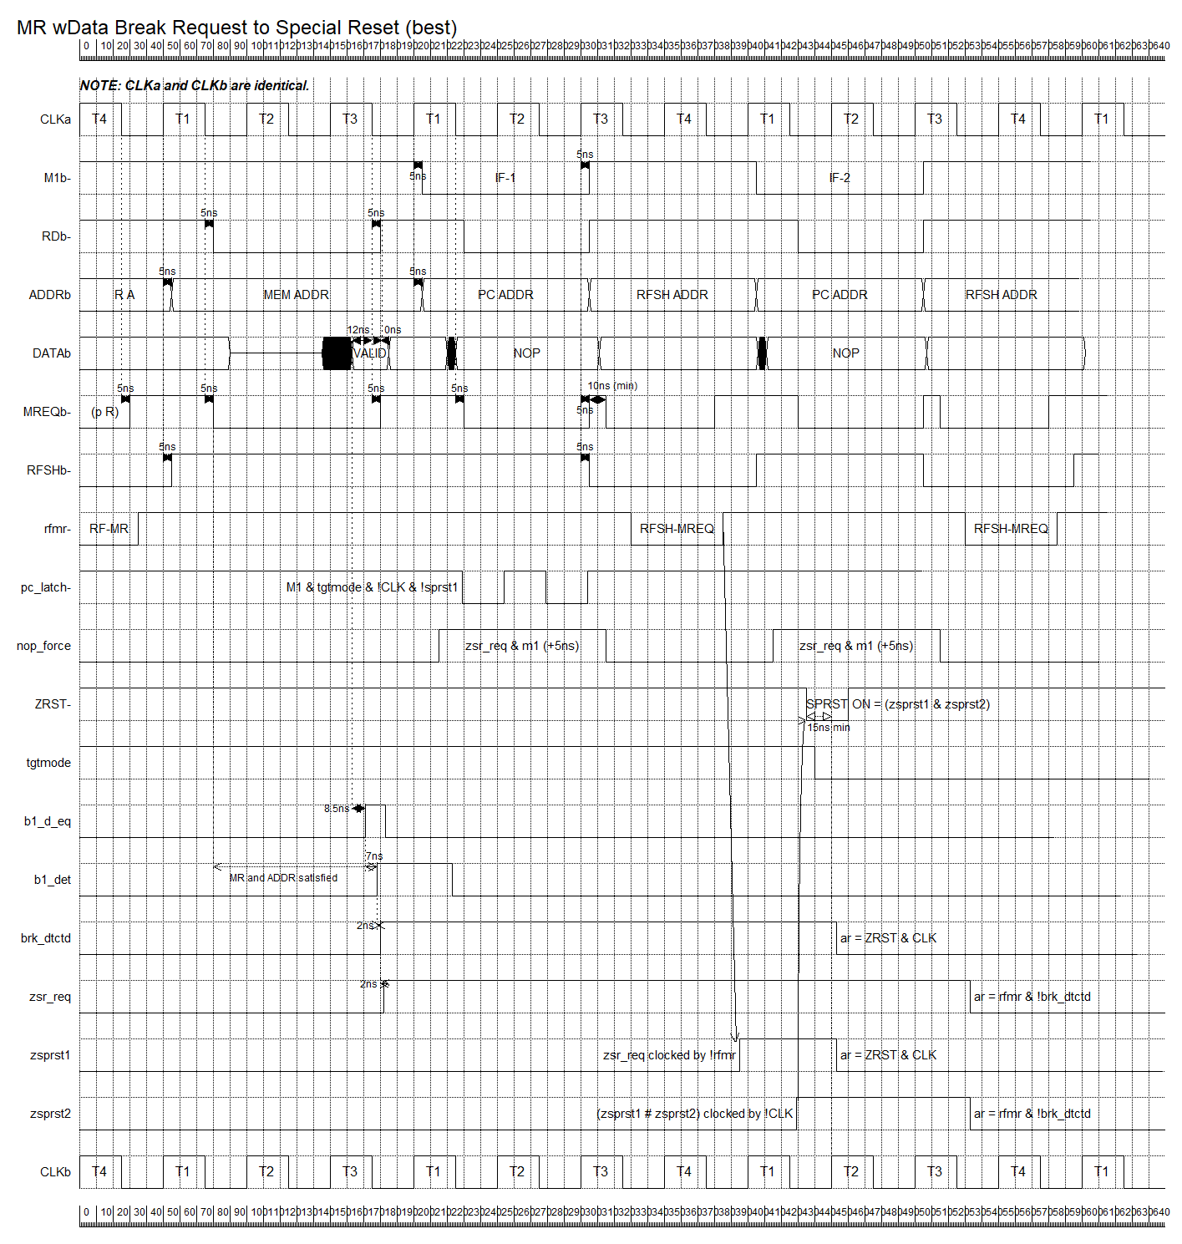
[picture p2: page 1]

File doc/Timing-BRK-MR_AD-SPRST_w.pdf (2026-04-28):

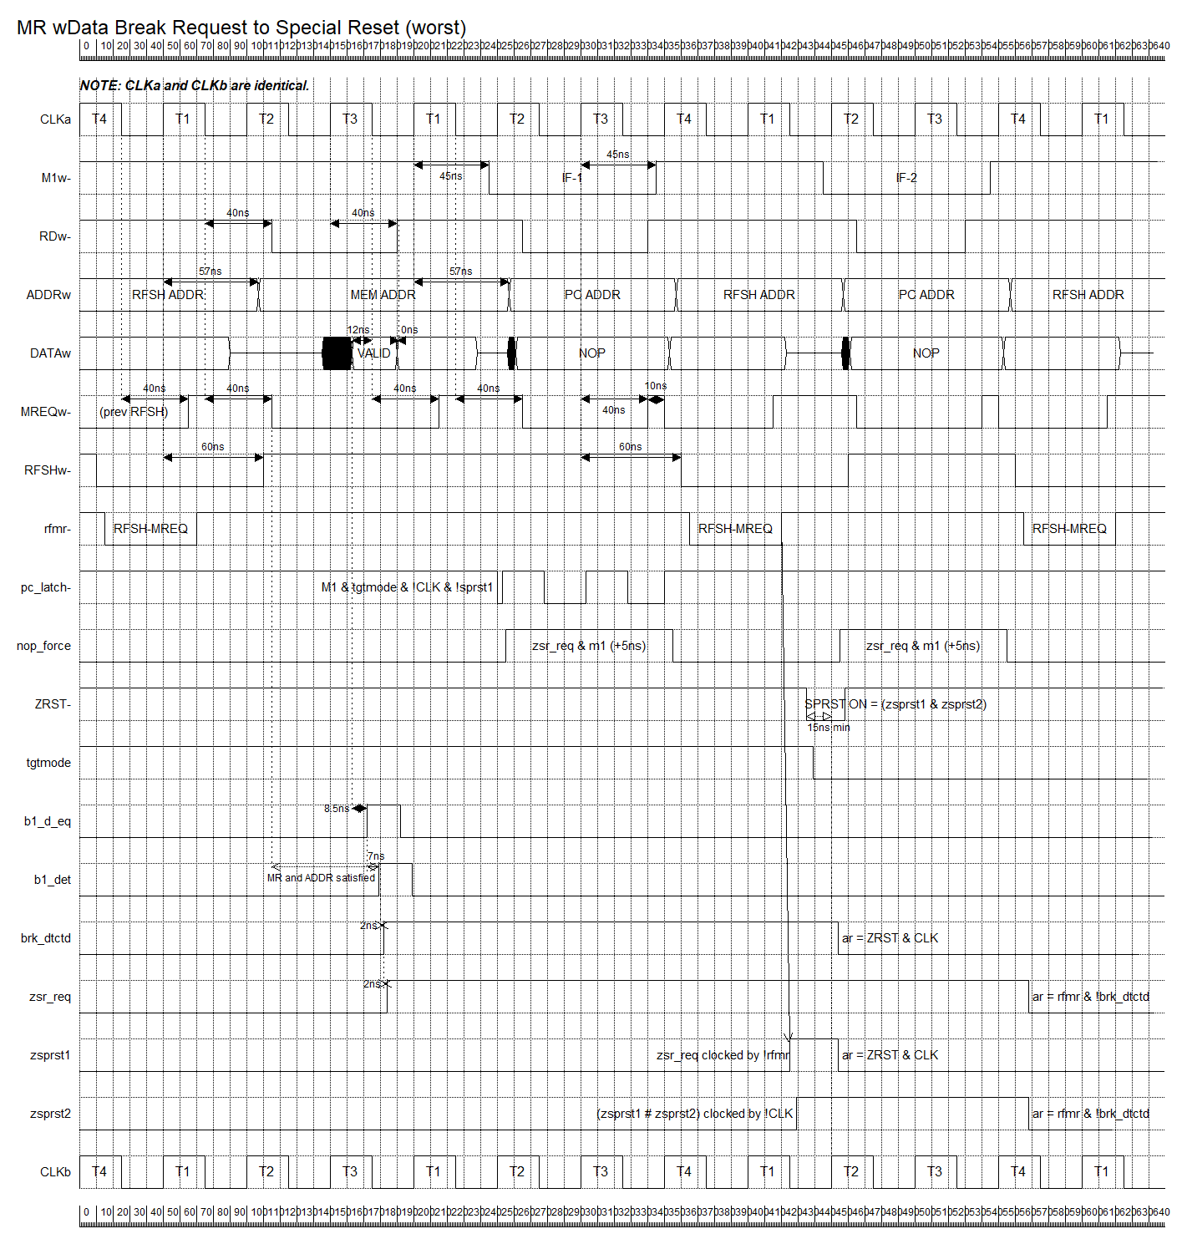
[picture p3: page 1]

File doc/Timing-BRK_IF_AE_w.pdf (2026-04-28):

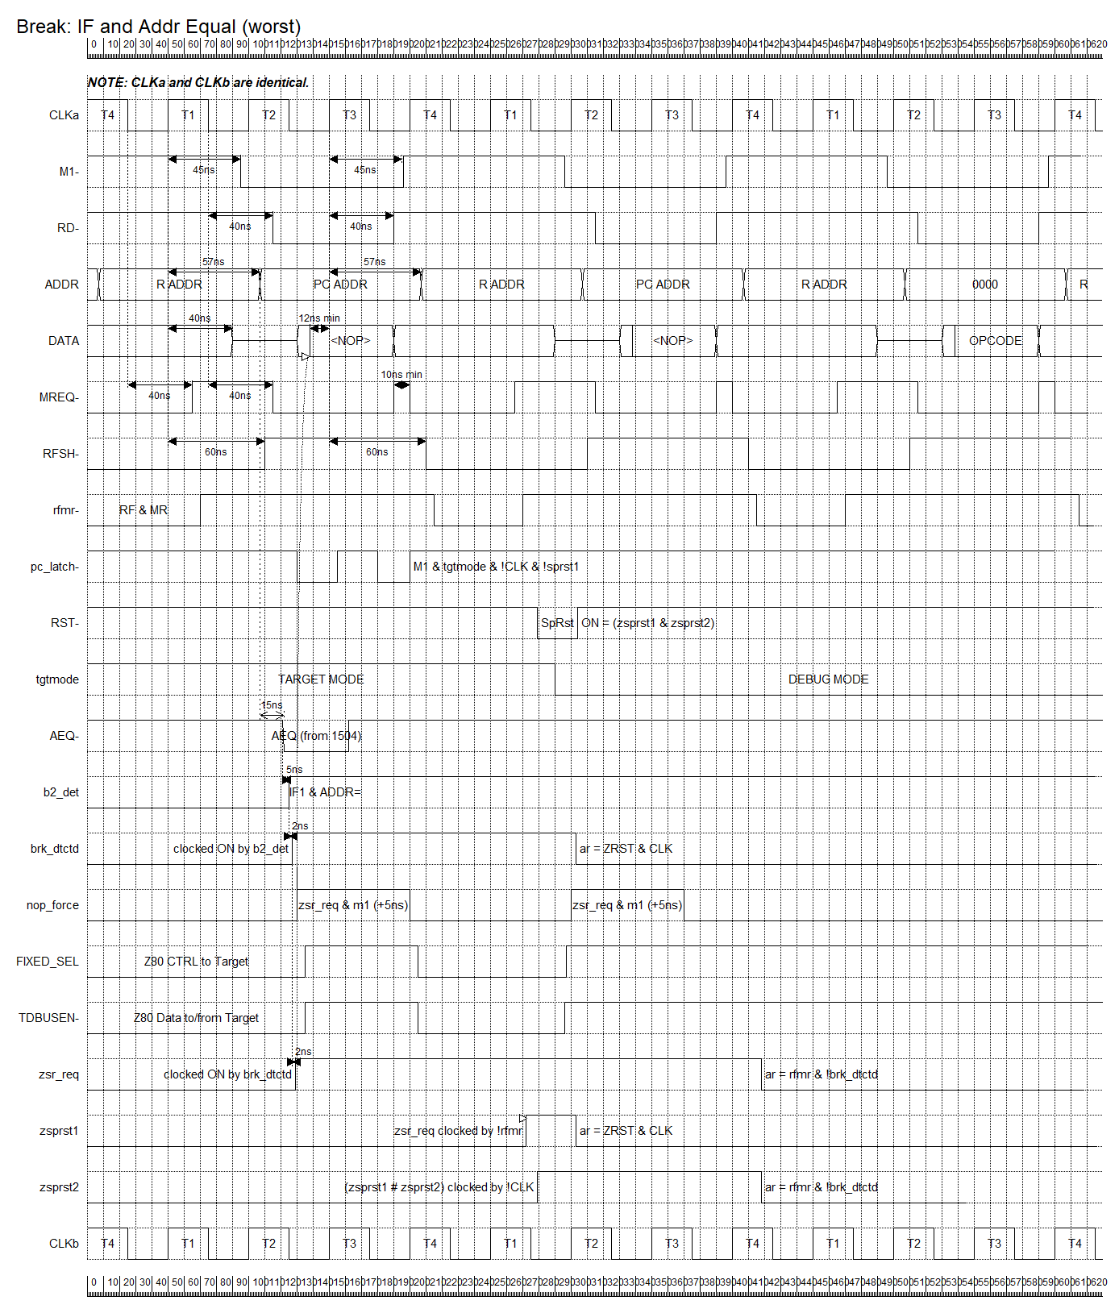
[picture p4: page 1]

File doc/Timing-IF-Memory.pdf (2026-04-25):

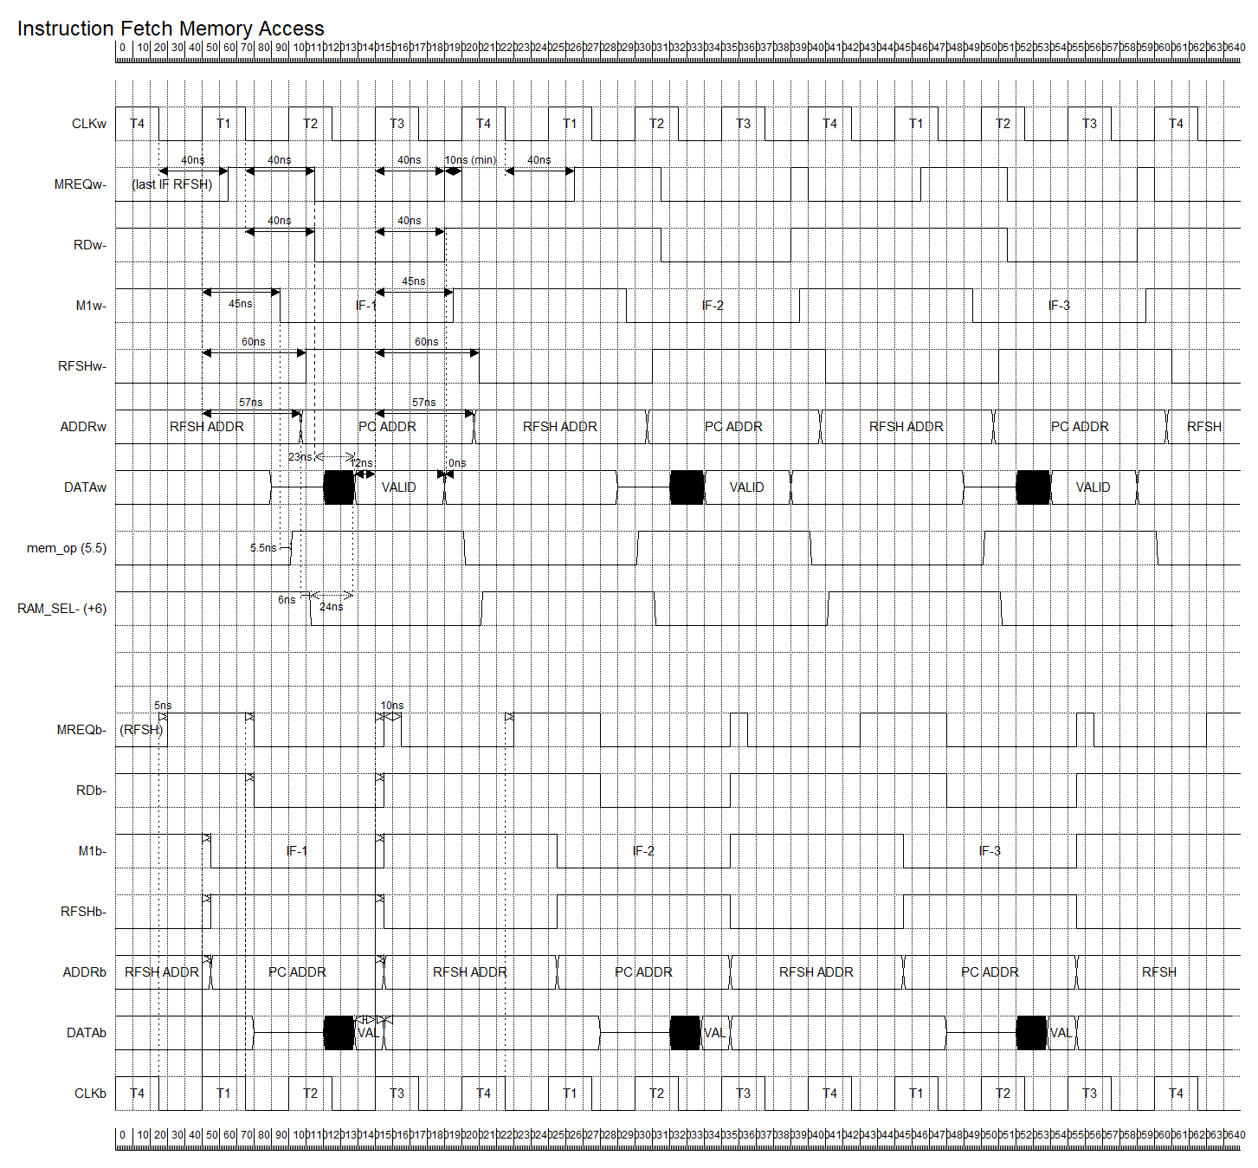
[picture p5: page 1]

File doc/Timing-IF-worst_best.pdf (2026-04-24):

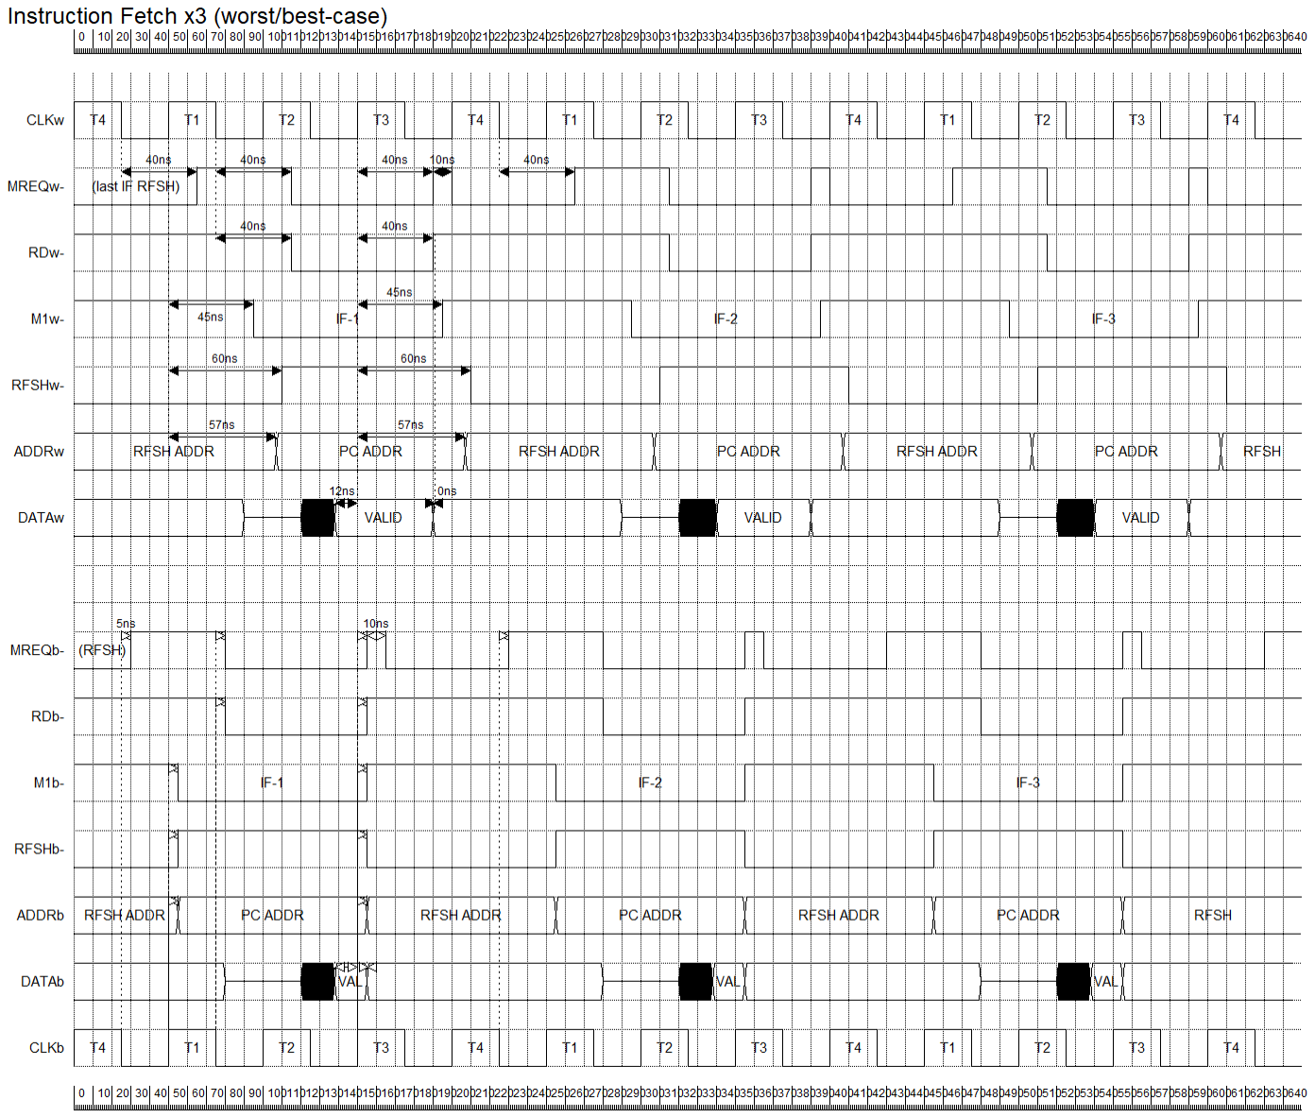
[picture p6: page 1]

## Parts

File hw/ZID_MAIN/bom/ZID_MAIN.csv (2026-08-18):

Reference | Qty | Value | DNP | Exclude from BOM | Exclude from Board | Footprint | Datasheet
C1,C2 | 2 | 0.1uf |  |  |  | Capacitor_SMD:C_0603_1608Metric | ~
C3 | 1 | 100UF TANT |  |  |  | Capacitor_Tantalum_SMD:CP_EIA-7343-31_Kemet-D_HandSolder | https://datasheets.kyocera-avx.com/TAJ.pdf
C4,C5,C6,C7,C8,C9,C10,C11,C20,C21,C22,C23,C24,C25,C26,C27,C28,C29,C30,C31,C32,C33,C34,C39,C40,C41,C42,C43,C44,C45,C46,C47,C48,C49,C50 | 35 | 0.1uF |  |  |  | Capacitor_SMD:C_0603_1608Metric | ~
D1 | 1 | BAT20J |  |  |  | Diode_SMD:D_SOD-323_HandSoldering | https://www.vishay.com/docs/85514/bat86s.pdf
D2 | 1 | SMAJ6.0A |  |  |  | Diode_SMD:D_SMA | https://www.onsemi.com/pdf/datasheet/esd5z2.5t1-d.pdf
D3,D4 | 2 | PESD5V0L2U |  |  |  | Package_TO_SOT_SMD:SOT-323_SC-70 | https://www.st.com/resource/en/datasheet/esdal.pdf
DBOPT1,OP1,SBC1,SBC2,SBC3 | 5 | AES-Option_A-B_2mm |  |  |  | Connector_PinHeader_2.00mm:PinHeader_1x03_P2.00mm_Vertical
H1,H2,H3,H4 | 4 | MountingHole |  | Excluded from BOM |  | MountingHole:MountingHole_3.2mm_M3 | ~
J1 | 1 | Conn 1x04 0.1" Socket |  |  |  | Connector_PinSocket_2.54mm:PinSocket_1x04_P2.54mm_Vertical | ~
J2,J11 | 2 | JST-PH-K B6B |  |  |  | Connector_JST:JST_PH_B6B-PH-K_1x06_P2.00mm_Vertical | https://learn.adafruit.com/adafruit-spi-flash-sd-card/pinouts,~
J3 | 1 | Conn 1x02 0.1" pin |  |  |  | Connector_PinHeader_2.54mm:PinHeader_1x02_P2.54mm_Vertical | ~
J4 | 1 | Conn 1x03 0.1" pin |  |  |  | Connector_PinHeader_2.54mm:PinHeader_1x03_P2.54mm_Vertical | ~
J5,J6 | 2 | Conn 1x08 0.1" pin | DNP | Excluded from BOM |  | Connector_PinHeader_2.54mm:PinHeader_1x08_P2.54mm_Vertical | ~
J7,J9 | 2 | Conn 2x04 0.1" pin |  |  |  | Connector_PinHeader_2.54mm:PinHeader_2x04_P2.54mm_Vertical
J8 | 1 | Conn 2x02 0.1" pin |  |  |  | Connector_PinHeader_2.54mm:PinHeader_2x02_P2.54mm_Vertical | ~
J10 | 1 | FFC/FPC-40 Socket |  |  |  | AES_Library:CviLux_CF25401D0-05-NH_FFC-FPC-AES | ~
J12 | 1 | JST-PH-K B6B |  | Excluded from BOM | Excluded from board | Connector_JST:JST_PH_B6B-PH-K_1x06_P2.00mm_Vertical | ~
J13 | 1 | Conn_02x05_PINHDR_2.54mm |  | Excluded from BOM | Excluded from board | Connector_IDC:IDC-Header_2x05_P2.54mm_Vertical | ~
J14 | 1 | USB-C PWR ONLY |  |  |  | AES_Library:AES-USB_C-Molex-BdTopMnt-2171790001
J15 | 1 | Conn 2x03 pin hdr 0.1" |  |  |  | Connector_PinHeader_2.00mm:PinHeader_2x03_P2.00mm_Vertical | ~
JP1,JP3 | 2 | Jumper_2_Small_Open_wsto-AES |  |  |  | Connector_PinHeader_2.00mm:PinHeader_1x03_P2.00mm_Vertical | ~
JP2 | 1 | SolderJumper_2_Open |  | Excluded from BOM |  | Jumper:SolderJumper-2_P1.3mm_Open_RoundedPad1.0x1.5mm | ~
JP4,JP7 | 2 | Jumper_2_Small_Bridged |  |  |  | Connector_PinHeader_2.00mm:PinHeader_1x02_P2.00mm_Vertical | ~
JP6 | 1 | Jumper_2_Small_Open |  |  |  | Connector_PinHeader_2.00mm:PinHeader_1x02_P2.00mm_Vertical | ~
LED1,LED2,LED6 | 3 | LED GREEN |  |  |  | LED_SMD:LED_0805_2012Metric | ~
LED3,LED4,LED9 | 3 | LED YELLOW |  |  |  | LED_SMD:LED_0805_2012Metric | ~
LED5,LED8 | 2 | LED RED |  |  |  | LED_SMD:LED_0805_2012Metric | ~
LED7 | 1 | LED ORANGE |  |  |  | LED_SMD:LED_0805_2012Metric | ~
LED10 | 1 | LED BLUE |  |  |  | LED_SMD:LED_0805_2012Metric | ~
M1 | 1 | WS-RP2040-Zero |  |  |  | AES_Library:RP2040_WS-ZERO-AES
OP2,OP3 | 2 | pin header 1x03 0.1" |  |  |  | Connector_PinHeader_2.54mm:PinHeader_1x03_P2.54mm_Vertical
R1 | 1 | 18k |  |  |  | Resistor_SMD:R_0805_2012Metric | ~
R2,R3 | 2 | 6.8k |  |  |  | Resistor_SMD:R_0805_2012Metric | ~
R4,R5,R6,R7,R27,R28,R29 | 7 | 4.7k |  |  |  | Resistor_SMD:R_0805_2012Metric | ~
R8,R9,R12,R16,R19,R20,R21,R22,R24,R31,R38,R39 | 12 | 20k |  |  |  | Resistor_SMD:R_0805_2012Metric | ~
R10,R44 | 2 | 0 |  |  |  | Resistor_SMD:R_0805_2012Metric_Pad1.20x1.40mm_HandSolder | ~
R11,R13,R15,R17,R18 | 5 | 820 |  |  |  | Resistor_SMD:R_0805_2012Metric | ~
R14 | 1 | 100K |  |  |  | Resistor_SMD:R_0805_2012Metric_Pad1.20x1.40mm_HandSolder | ~
R23,R34,R42 | 3 | 100k |  |  |  | Resistor_SMD:R_0805_2012Metric | ~
R25,R26,R32 | 3 | 10k |  |  |  | Resistor_SMD:R_0805_2012Metric | ~
R30,R33,R35,R37,R41 | 5 | 1.2k |  |  |  | Resistor_SMD:R_0805_2012Metric | ~
R36,R40 | 2 | 22 |  |  |  | Resistor_SMD:R_0805_2012Metric | ~
RN1,RN2 | 2 | 100k |  |  |  | Resistor_THT:R_Array_SIP9 | http://www.vishay.com/docs/31509/csc.pdf
SD1 | 1 | SD-CARD Socket |  |  |  | AES_Library:AES-SDCard-GCT_MEM2075-00-140-01-A
SPARE1 | 1 | ~ |  | Excluded from BOM |  | AES_Library:SPARE-16-SOT-5_6-AES
SW1 | 1 | SW_Push |  |  |  | AES_Library:AES-SW_PUSH_SMD_1P1T_NO_45x45mm-CK | ~
SW2 | 1 | SW_DIP_x02 |  |  |  | Button_Switch_THT:SW_DIP_SPSTx02_Piano_CTS_Series194-2MSTN_W7.62mm_P2.54mm | ~
TP1 | 1 | TestPoint | DNP | Excluded from BOM |  | Connector_PinHeader_2.00mm:PinHeader_1x01_P2.00mm_Vertical | ~
TP2,TP3,TP4,TP5,TP6,TP7,TP8,TP9,TP10,TP11,TP12,TP13,TP17,TP18,TP19,TP20,TP21,TP22,TP23,TP24,TP25 | 21 | TestPoint | DNP | Excluded from BOM |  | TestPoint:TestPoint_THTPad_D1.0mm_Drill0.5mm | ~
TP14 | 1 | SYNC-CONN |  |  |  | Connector_PinHeader_2.54mm:PinHeader_1x01_P2.54mm_Vertical | ~
TP15 | 1 | EXT-BRK |  |  |  | Connector_PinHeader_2.54mm:PinHeader_1x01_P2.54mm_Vertical | ~
TP16 | 1 | GND-CONN |  |  |  | Connector_PinHeader_2.54mm:PinHeader_1x01_P2.54mm_Vertical | ~
U1 | 1 | OSC-20MHz |  |  |  | AES_Library:OSC-8_14-CO-AES
U2,U7,U13,U16 | 4 | 74FCT2245 |  |  |  | Package_SO:SSOP-20_3.9x8.7mm_P0.635mm | http://www.ti.com/lit/gpn/sn74LS245
U3 | 1 | 24LC32 |  |  |  | Package_SO:SOIC-8_3.9x4.9mm_P1.27mm | http://ww1.microchip.com/downloads/en/DeviceDoc/21072G.pdf
U4 | 1 | MIC2775 |  |  |  | Package_TO_SOT_SMD:SOT-23-5 | https://ww1.microchip.com/downloads/en/DeviceDoc/mic2775.pdf
U5 | 1 | SST39SF010 |  |  |  | Package_DIP:DIP-32_W15.24mm_Socket_LongPads | http://ww1.microchip.com/downloads/en/DeviceDoc/25022B.pdf
U6 | 1 | 74LVC245 |  |  |  | Package_SO:SO-20_5.3x12.6mm_P1.27mm | http://www.ti.com/lit/gpn/sn74LS245
U8 | 1 | 74AHCT14 |  |  |  | Package_SO:SO-14_3.9x8.65mm_P1.27mm | http://www.ti.com/lit/gpn/sn74HC14
U9 | 1 | Z80 C20MHz-PLCC |  |  |  | Package_LCC:PLCC-44_THT-Socket | https://archive.org/details/zilog-z-8400
U10 | 1 | 74LVC2G06 |  |  |  | Package_TO_SOT_SMD:SOT-363_SC-70-6 | https://www.onsemi.com/download/data-sheet/pdf/nl27wz06-d.pdf
U11,U21 | 2 | 74LVC2G34 |  |  |  | Package_TO_SOT_SMD:SOT-23-6
U12 | 1 | 74LVC273 |  |  |  | Package_SO:SO-20_12.8x7.5mm_P1.27mm | http://www.ti.com/lit/gpn/sn74LS273
U14 | 1 | AS7C1024B |  |  |  | AES_Library:SOJ-32_WN-AES | https://www.silicon-ark.co.uk/datasheets/hm628128-datasheet-hitachi.pdf
U15,U18 | 2 | ATF1508AS |  |  |  | Package_QFP:TQFP-100_14x14mm_P0.5mm
U17,U19 | 2 | 74HCT166 |  |  |  | Package_SO:SOIC-16_3.9x9.9mm_P1.27mm | http://www.ti.com/lit/gpn/sn74LS166
U20,U24 | 2 | 74FCT2244 |  |  |  | Package_SO:SSOP-20_3.9x8.7mm_P0.635mm | http://www.ti.com/lit/ds/symlink/sn74ls244.pdf
U22 | 1 | ATF1504AS-44T |  |  |  | Package_QFP:TQFP-44_10x10mm_P0.8mm
U23 | 1 | 74AHCT00 |  |  |  | Package_SO:SO-14_3.9x8.65mm_P1.27mm | http://www.ti.com/lit/gpn/sn74hct00

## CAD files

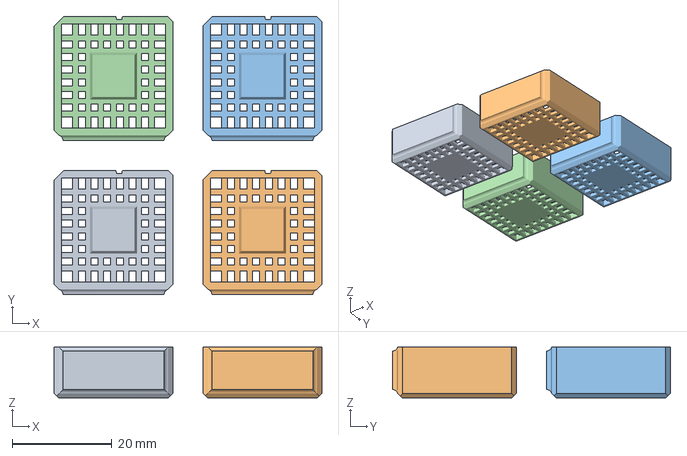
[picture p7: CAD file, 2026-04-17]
hw/ZID_POD/Adapter/PLCC44_Form2.3mf
53.8 x 55.8 x 10.2 mm

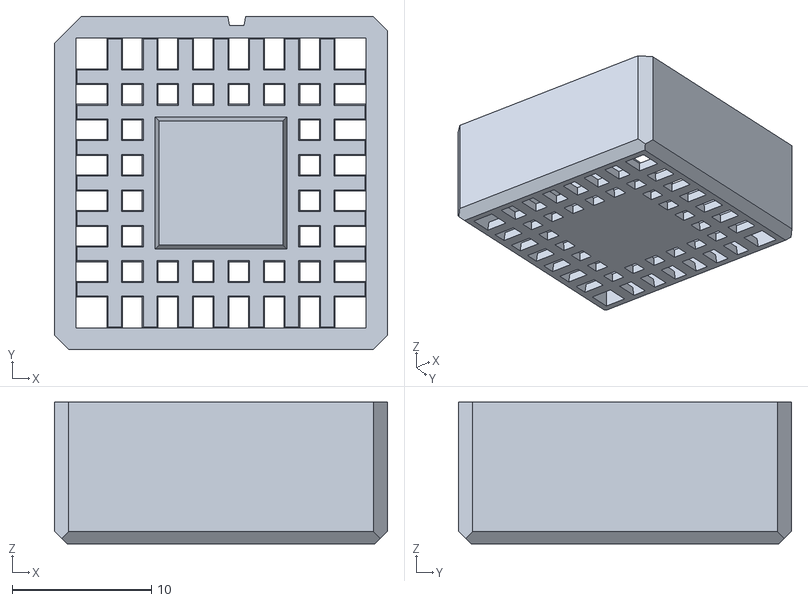
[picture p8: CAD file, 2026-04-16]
hw/ZID_POD/Adapter/PLCC44_Form1.stl
23.9 x 23.9 x 10.2

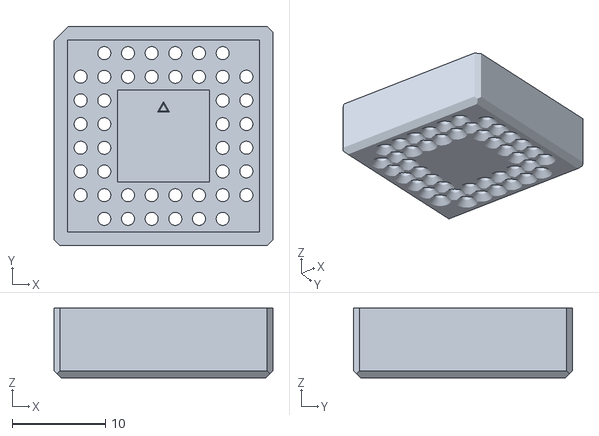
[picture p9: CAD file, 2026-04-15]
hw/ZID_POD/Adapter/PLCC44_Adpt2.stl
23.5 x 23.5 x 7.49

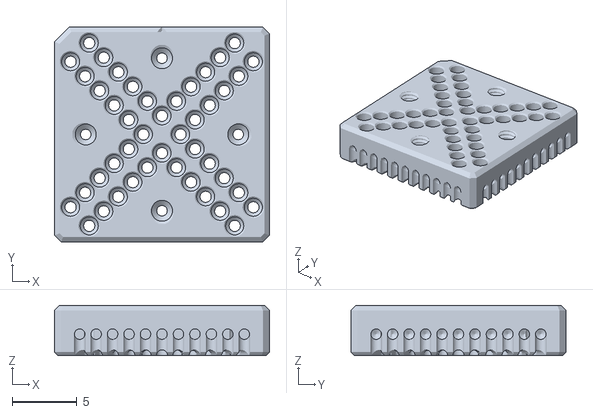
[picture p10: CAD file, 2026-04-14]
hw/ZID_POD/Adapter/Adapter-Body.stl
16.6 x 16.6 x 3.86

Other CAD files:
hw/ZID_POD/Adapter/PLCC44_Form2.stl

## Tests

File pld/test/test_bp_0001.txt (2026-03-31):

Breakpoint test (manual)

BRK-1: Test PW with Addr L and Data 0101101x (5A or 5B)
Clear the address enable
 O 1A 0 ; Any value (monitor baen_clr)
Shift enable out to BA1_L
 O 18 80 ; Bit-7 is used (monitor baen_clk)
Set Data Don't Care
 O 02 01
Set Data Value
 O 00 5A
Select PW as Operation
 O 04 05
Jumper brk1_a_eq L
Put CPLD in Target Mode
Output some values (not 5A or 5B) and then 5B
>>> CPLD should do ZSR and go to Debug Mode when 5B is output

BRK-1: Change to MW with both Addr L and Addr H
Shift enable to BA1_L (which pushes previous enable to H)
 O 18 80
Select MW as Operation
 0 04 02
(keep) Jumper brk1_a_eq L
Put CPLD in Target Mode
Write some values (not 5A or 5B) and then 5A
>>> CPLD should do ZSR and go to Debug Mode when 5A is written

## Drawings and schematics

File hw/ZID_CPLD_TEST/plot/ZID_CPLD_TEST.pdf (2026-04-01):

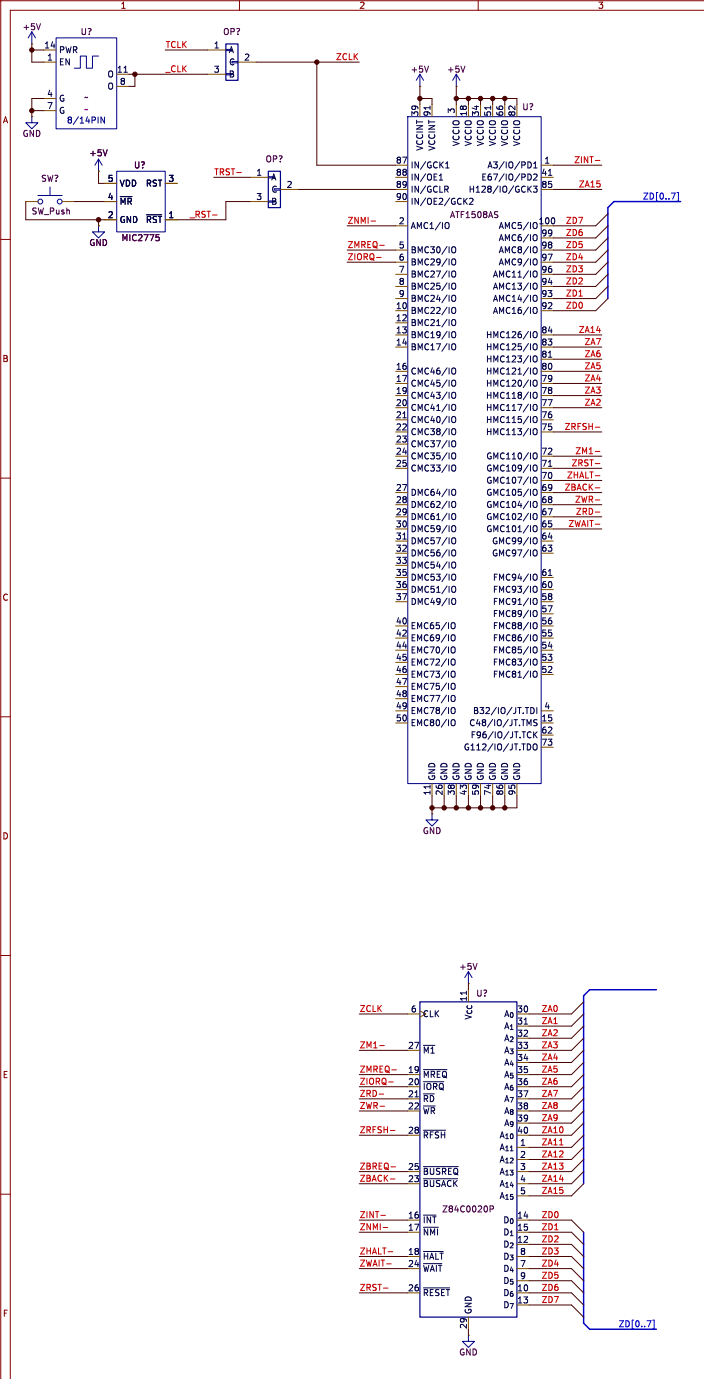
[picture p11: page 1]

Id: 1/1 Title: ZID CPLD Test File: ZID_CPLD_TEST.kicad_sch Sheet: / SilkyDESIGN

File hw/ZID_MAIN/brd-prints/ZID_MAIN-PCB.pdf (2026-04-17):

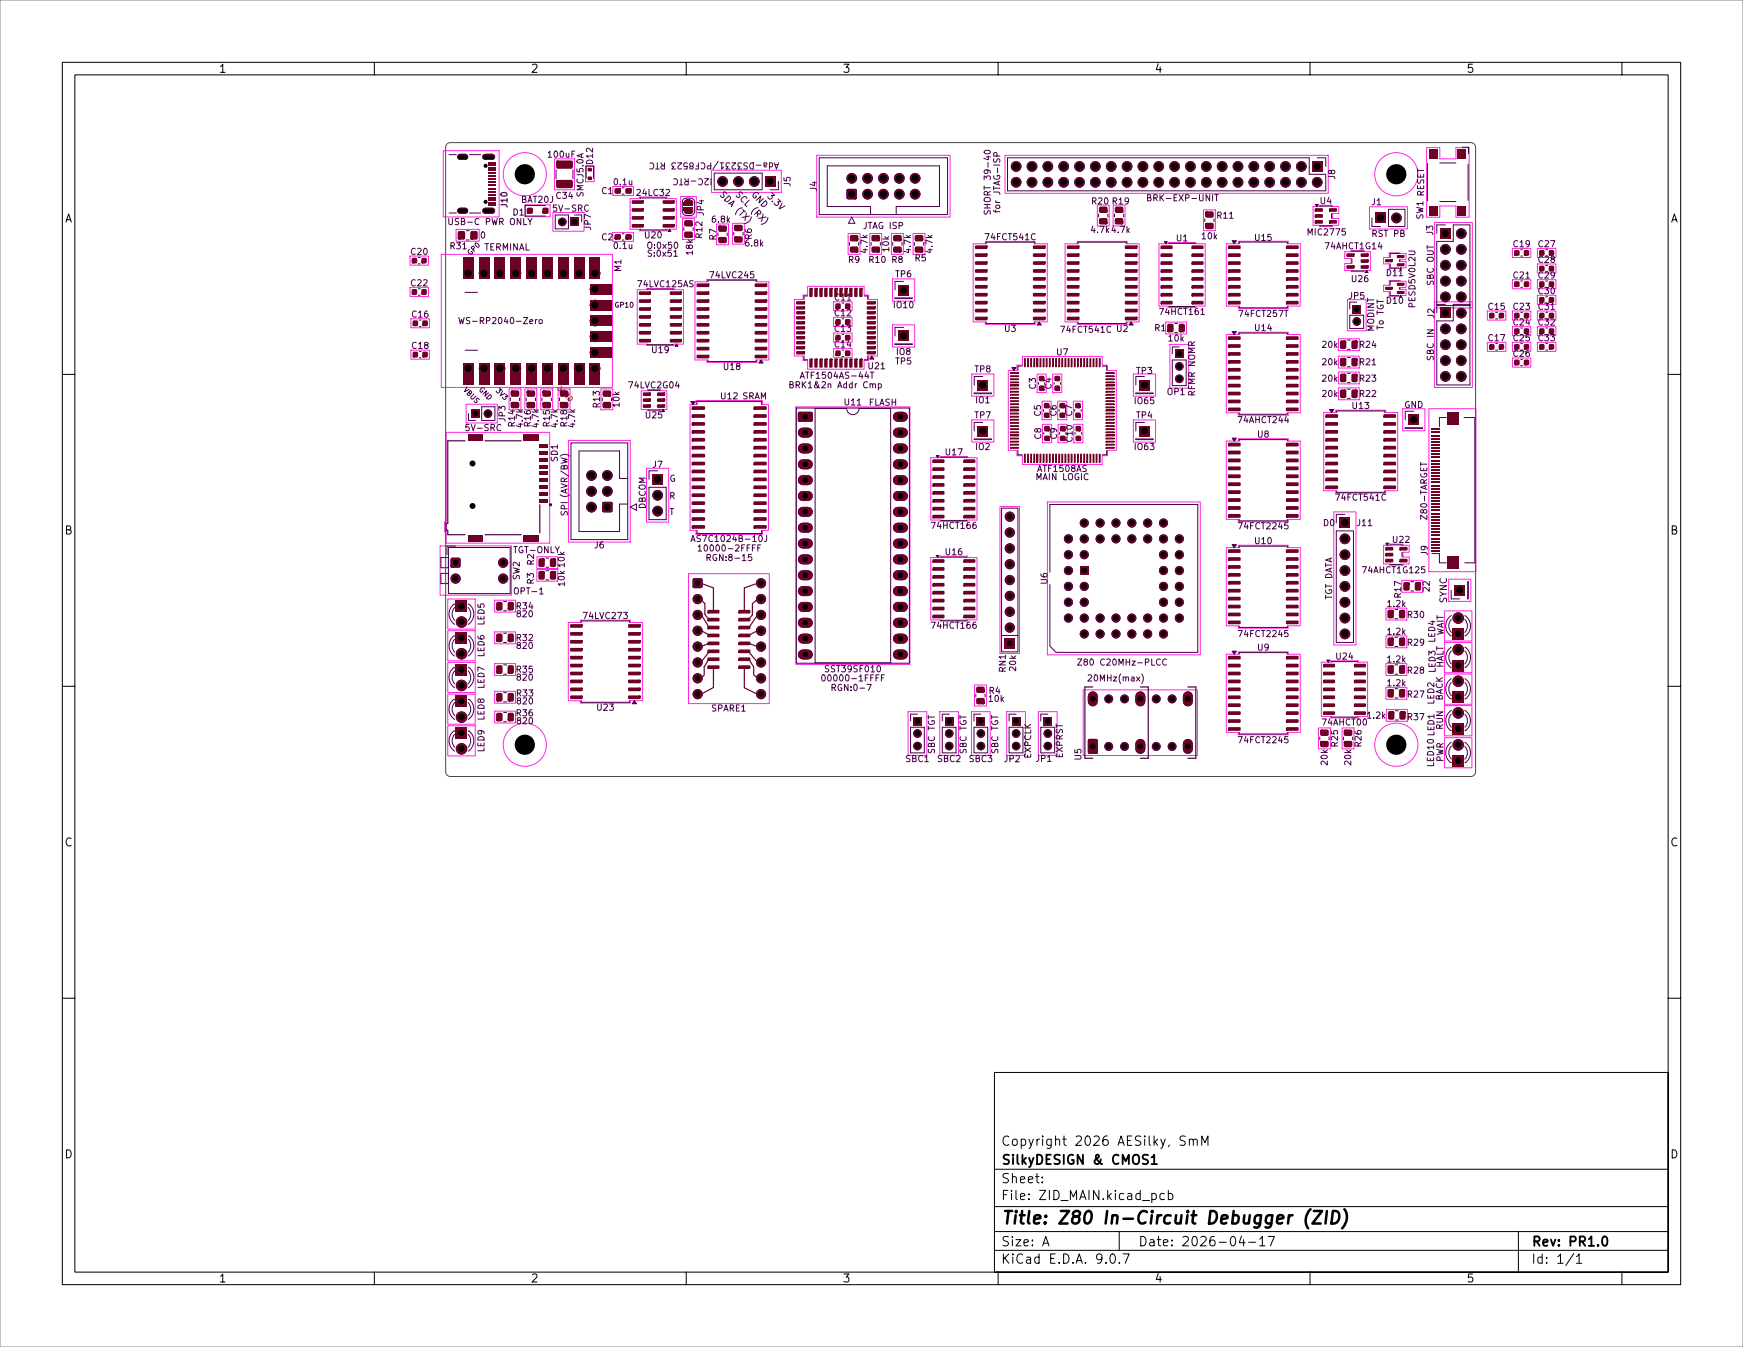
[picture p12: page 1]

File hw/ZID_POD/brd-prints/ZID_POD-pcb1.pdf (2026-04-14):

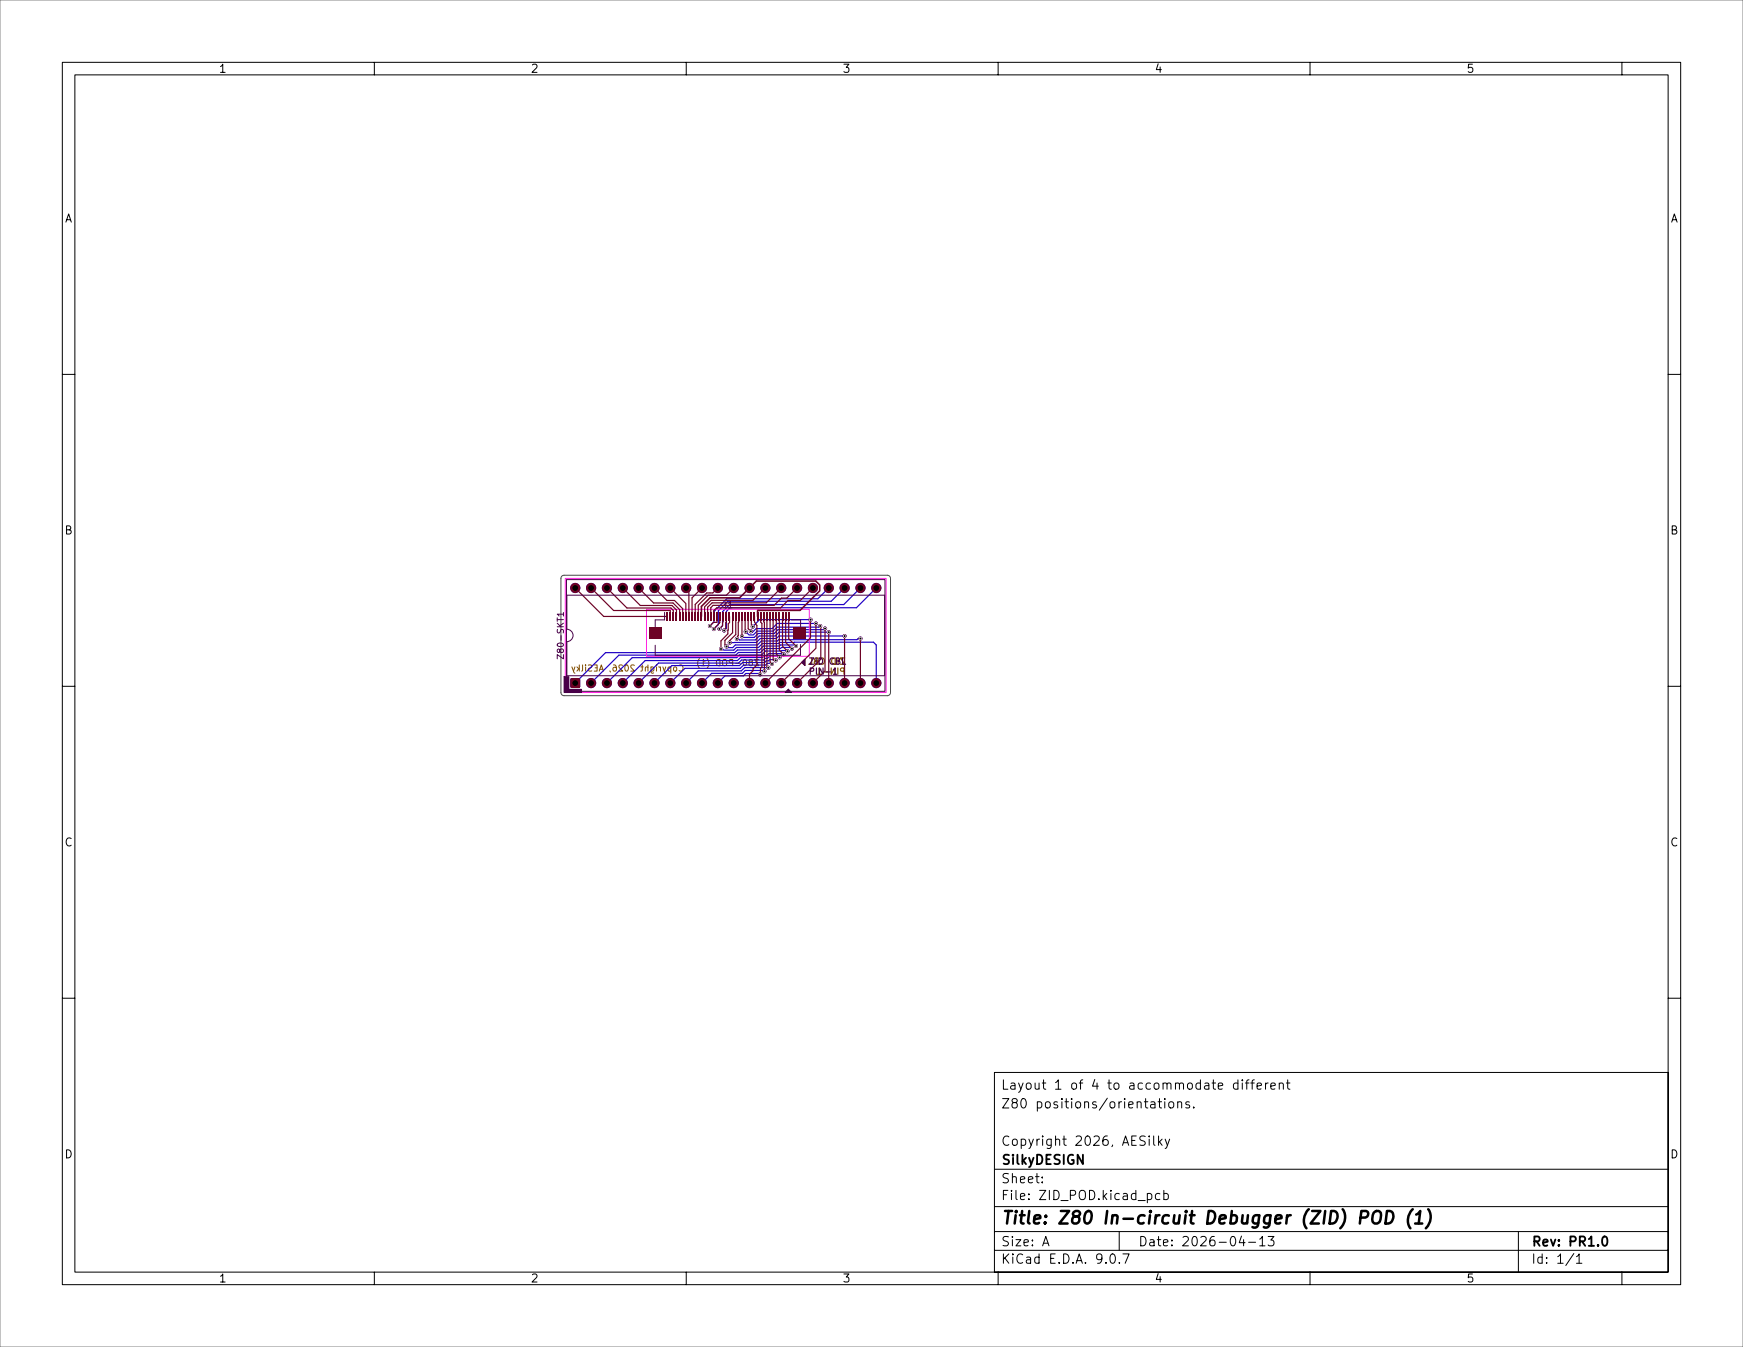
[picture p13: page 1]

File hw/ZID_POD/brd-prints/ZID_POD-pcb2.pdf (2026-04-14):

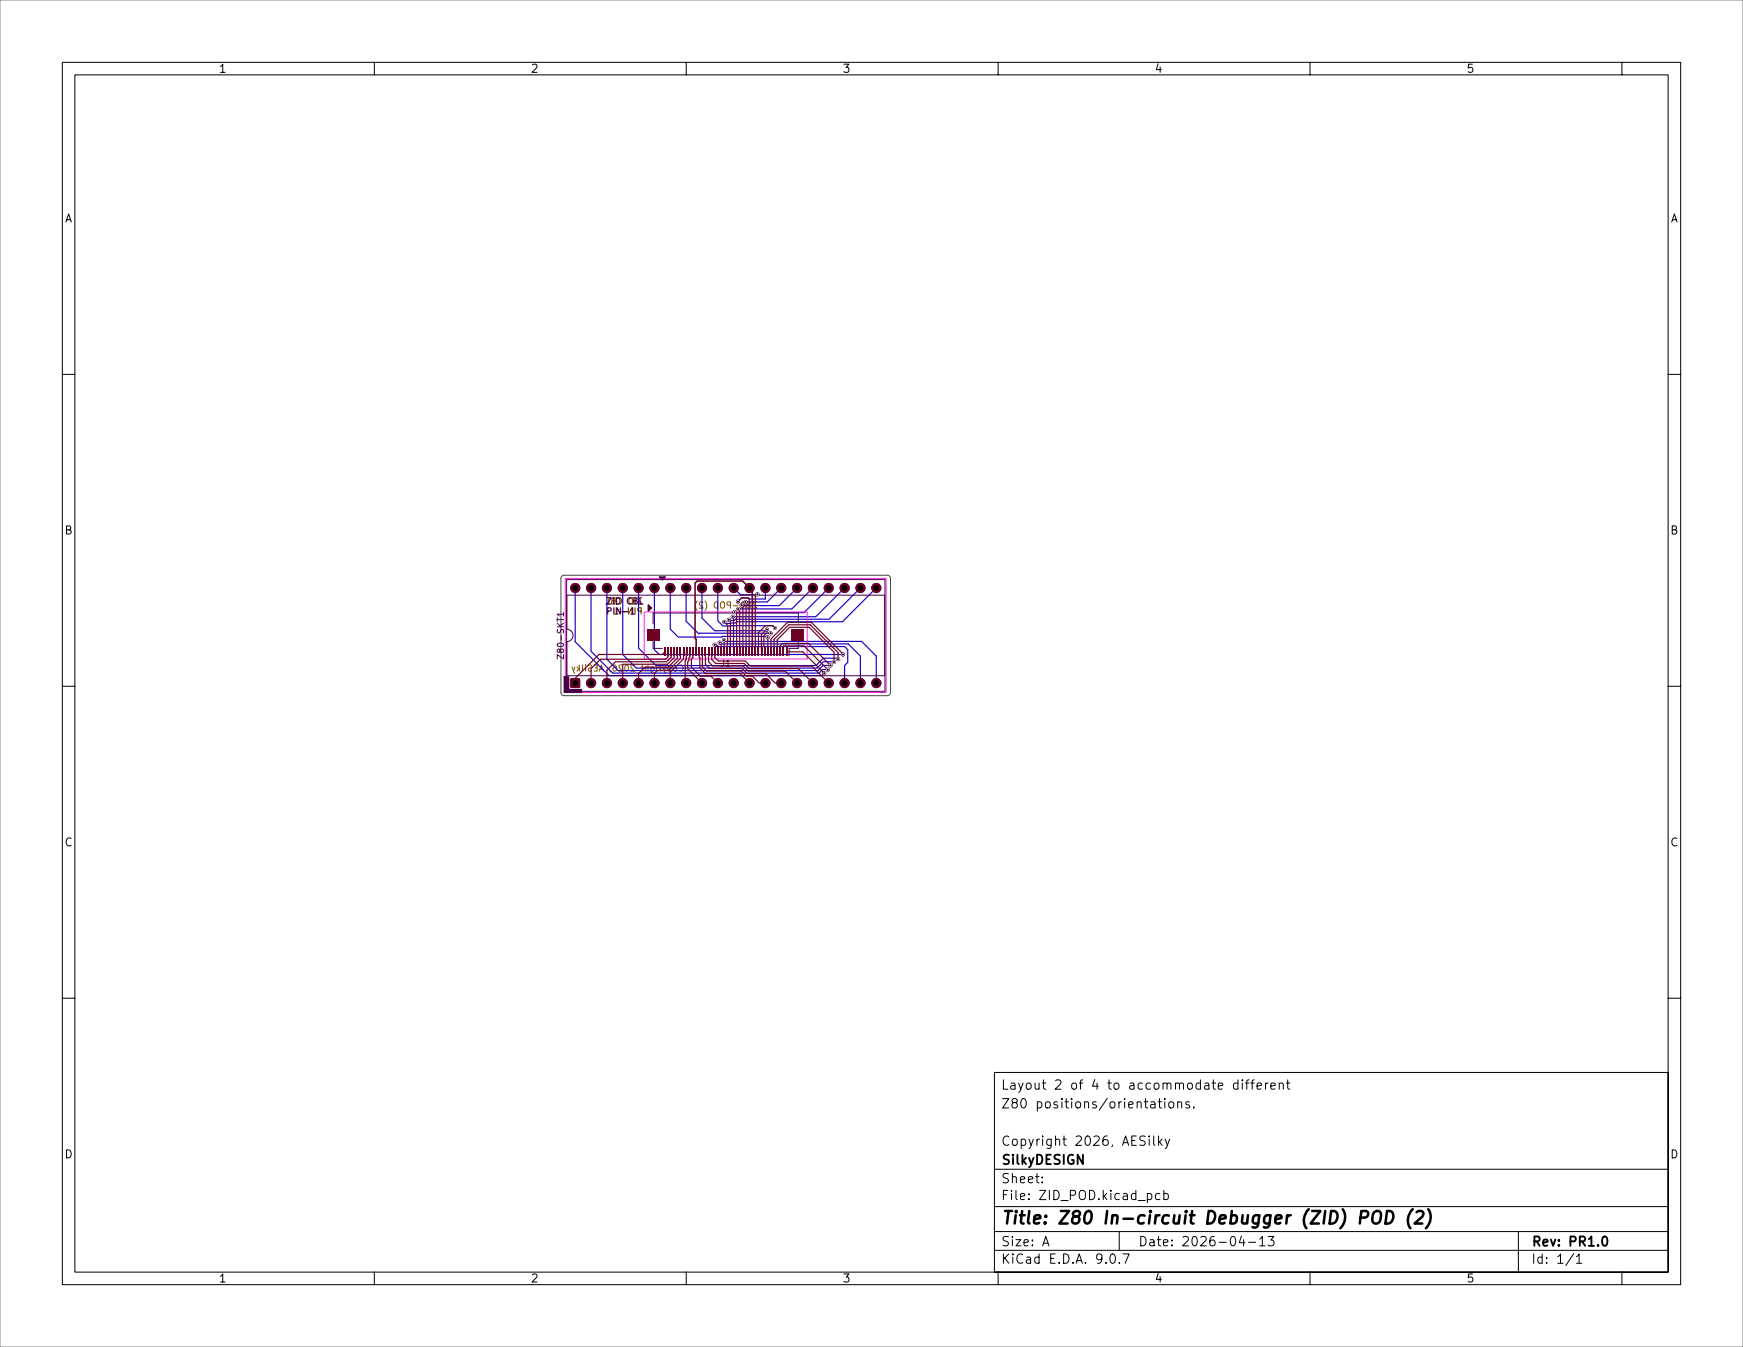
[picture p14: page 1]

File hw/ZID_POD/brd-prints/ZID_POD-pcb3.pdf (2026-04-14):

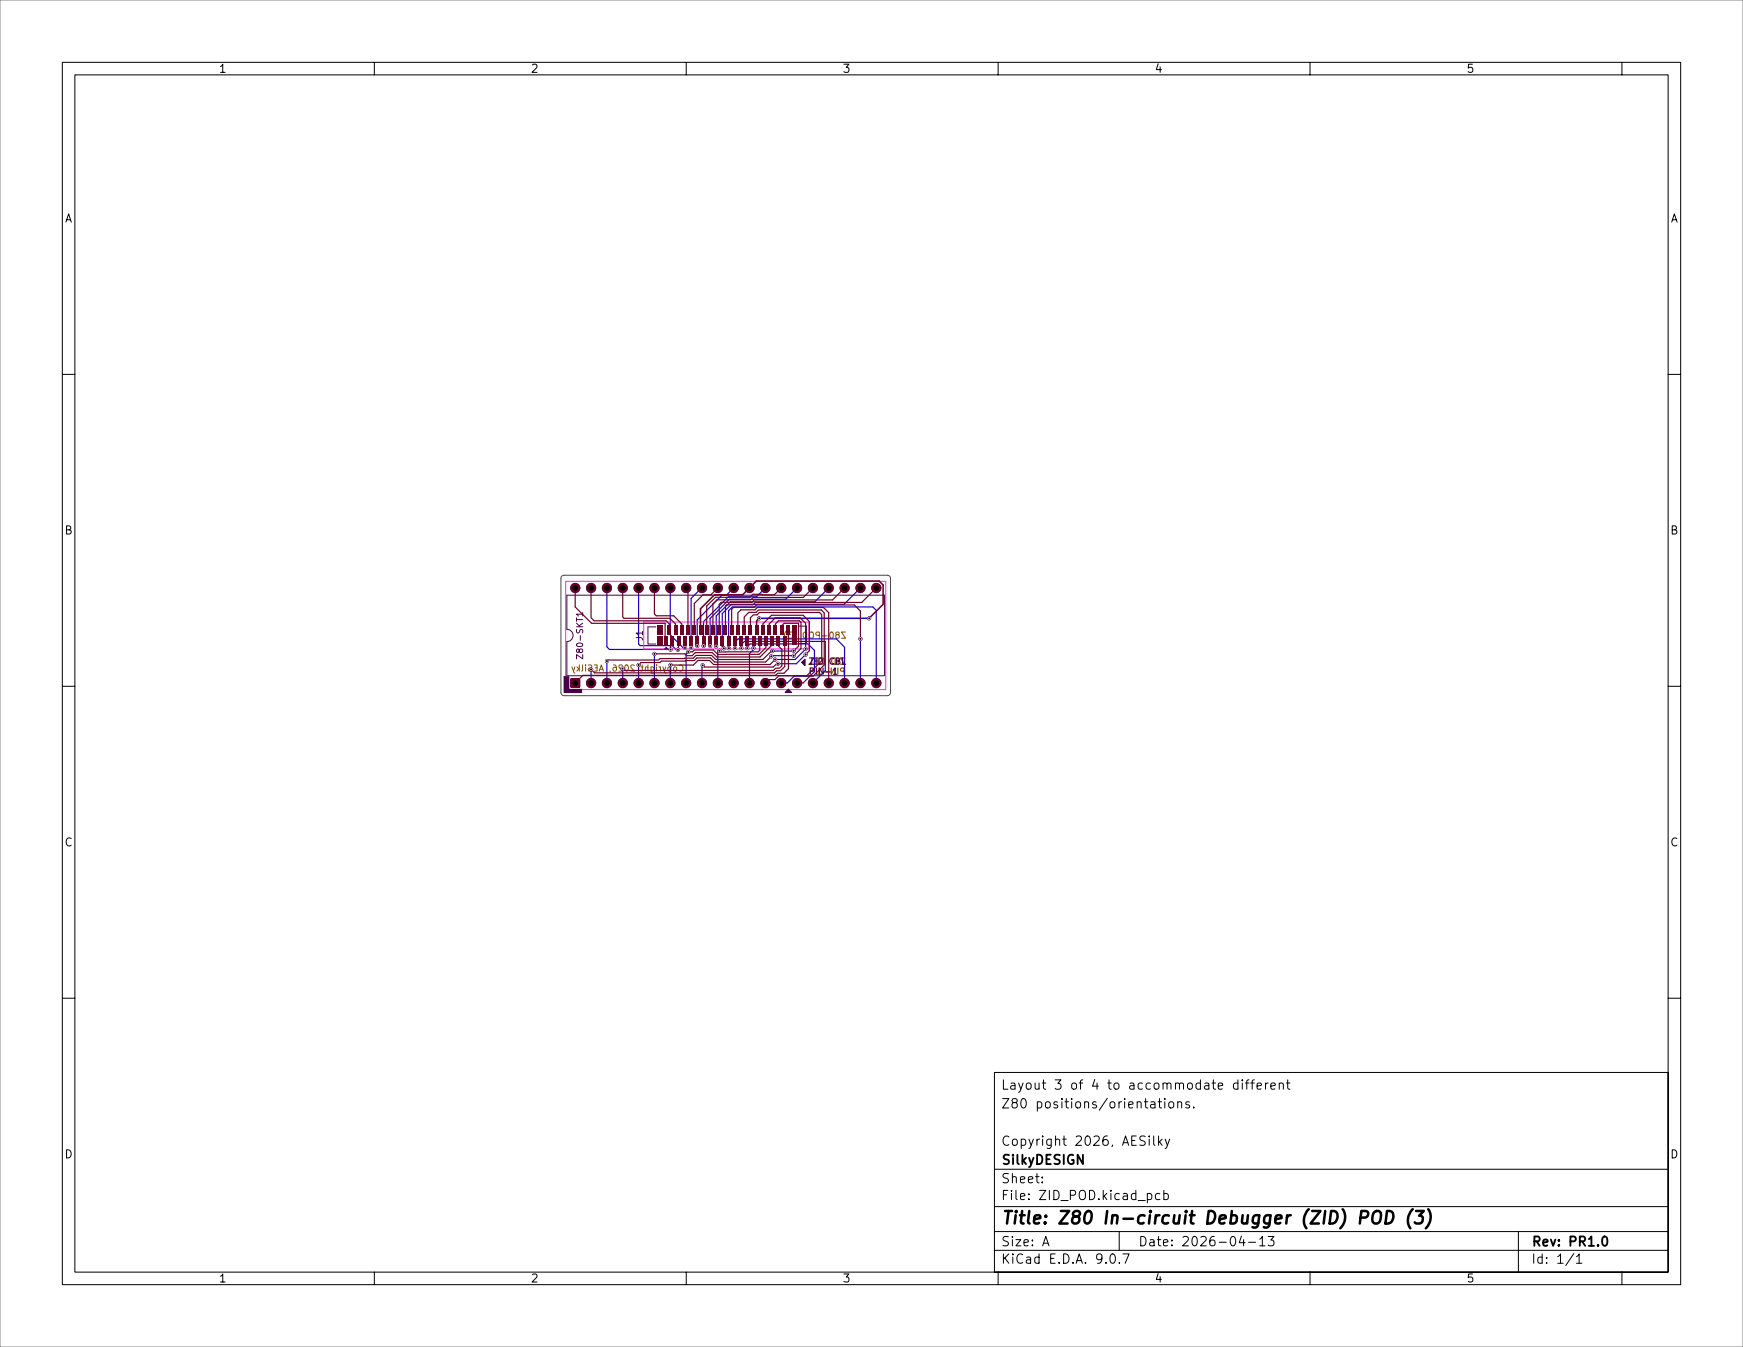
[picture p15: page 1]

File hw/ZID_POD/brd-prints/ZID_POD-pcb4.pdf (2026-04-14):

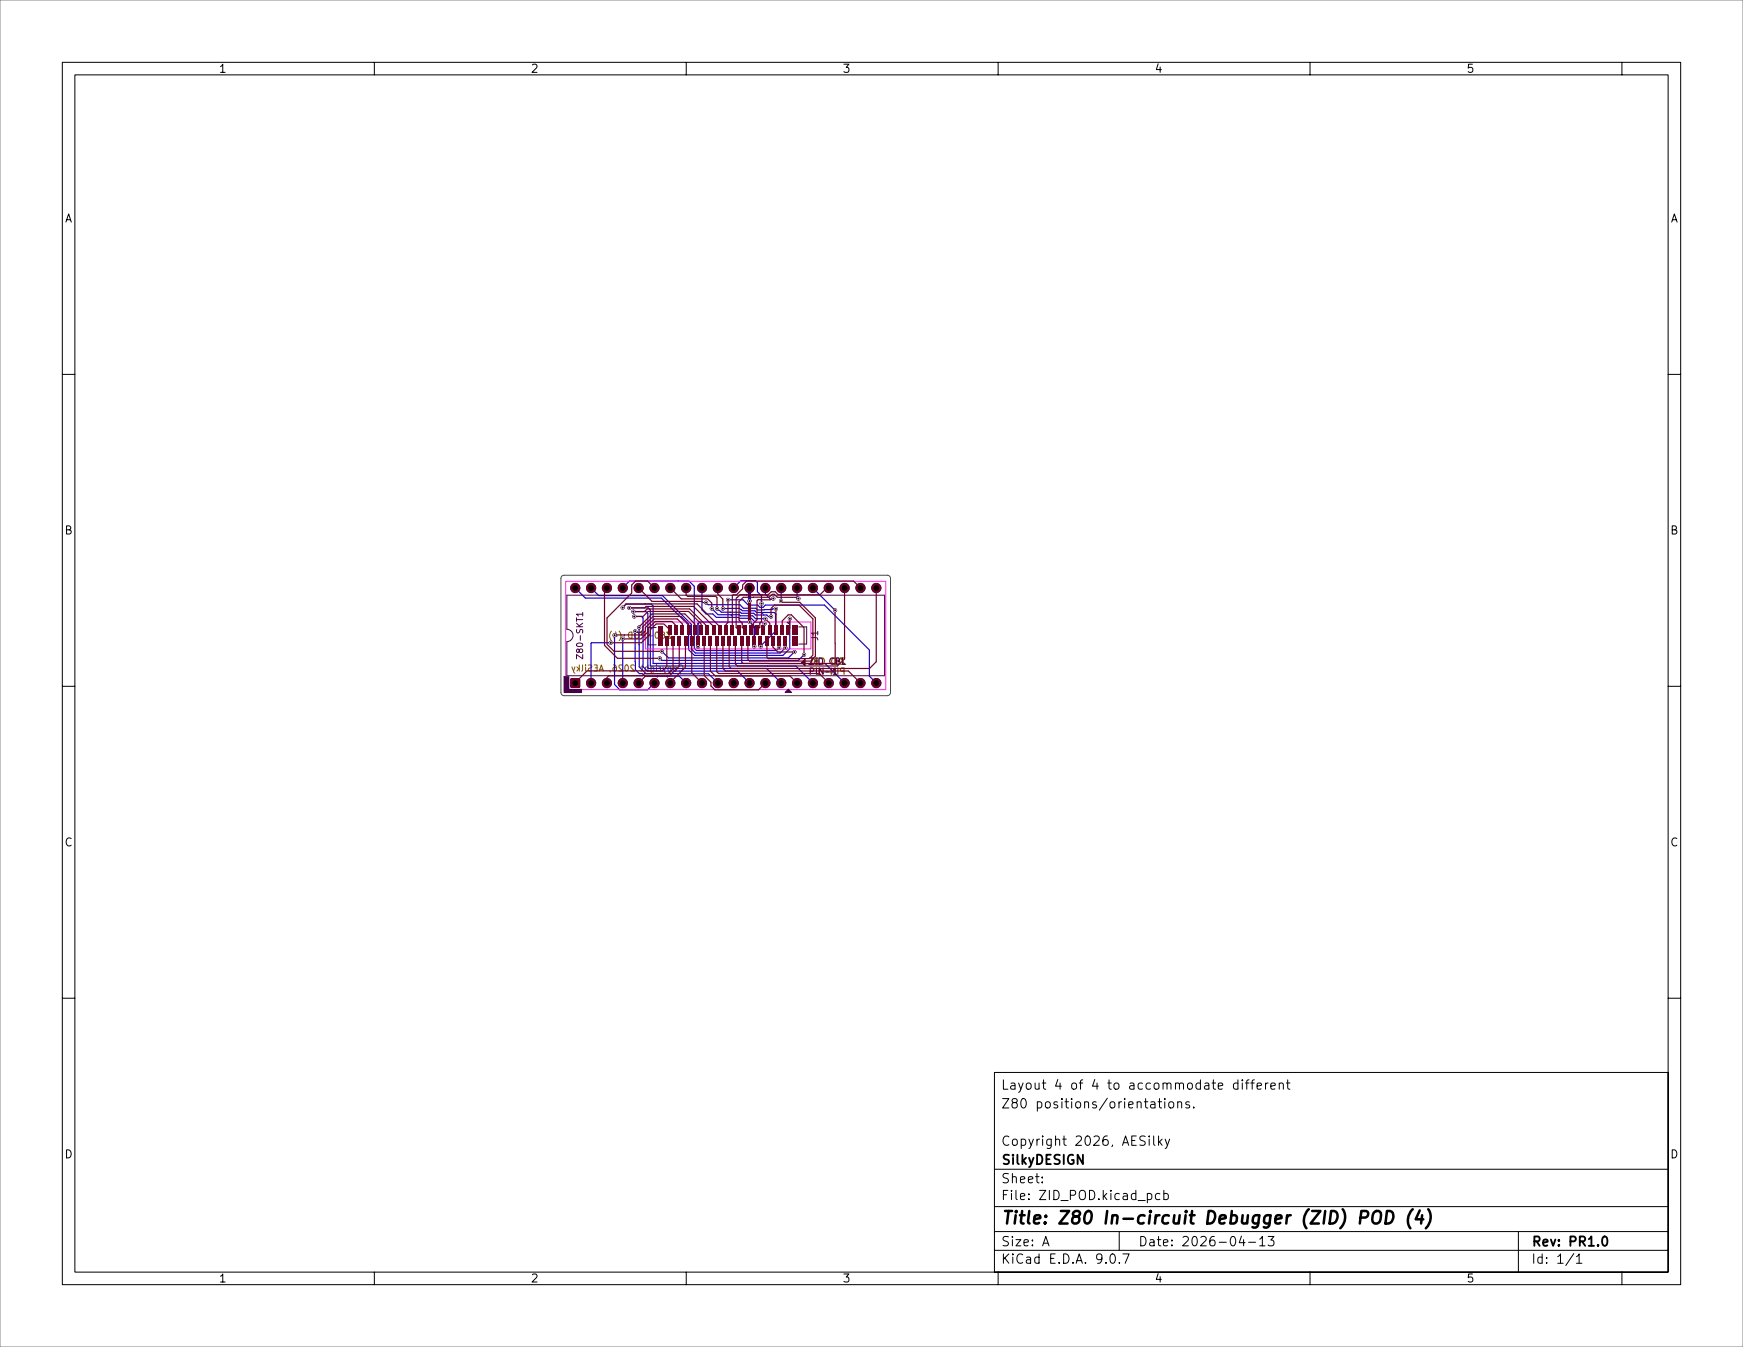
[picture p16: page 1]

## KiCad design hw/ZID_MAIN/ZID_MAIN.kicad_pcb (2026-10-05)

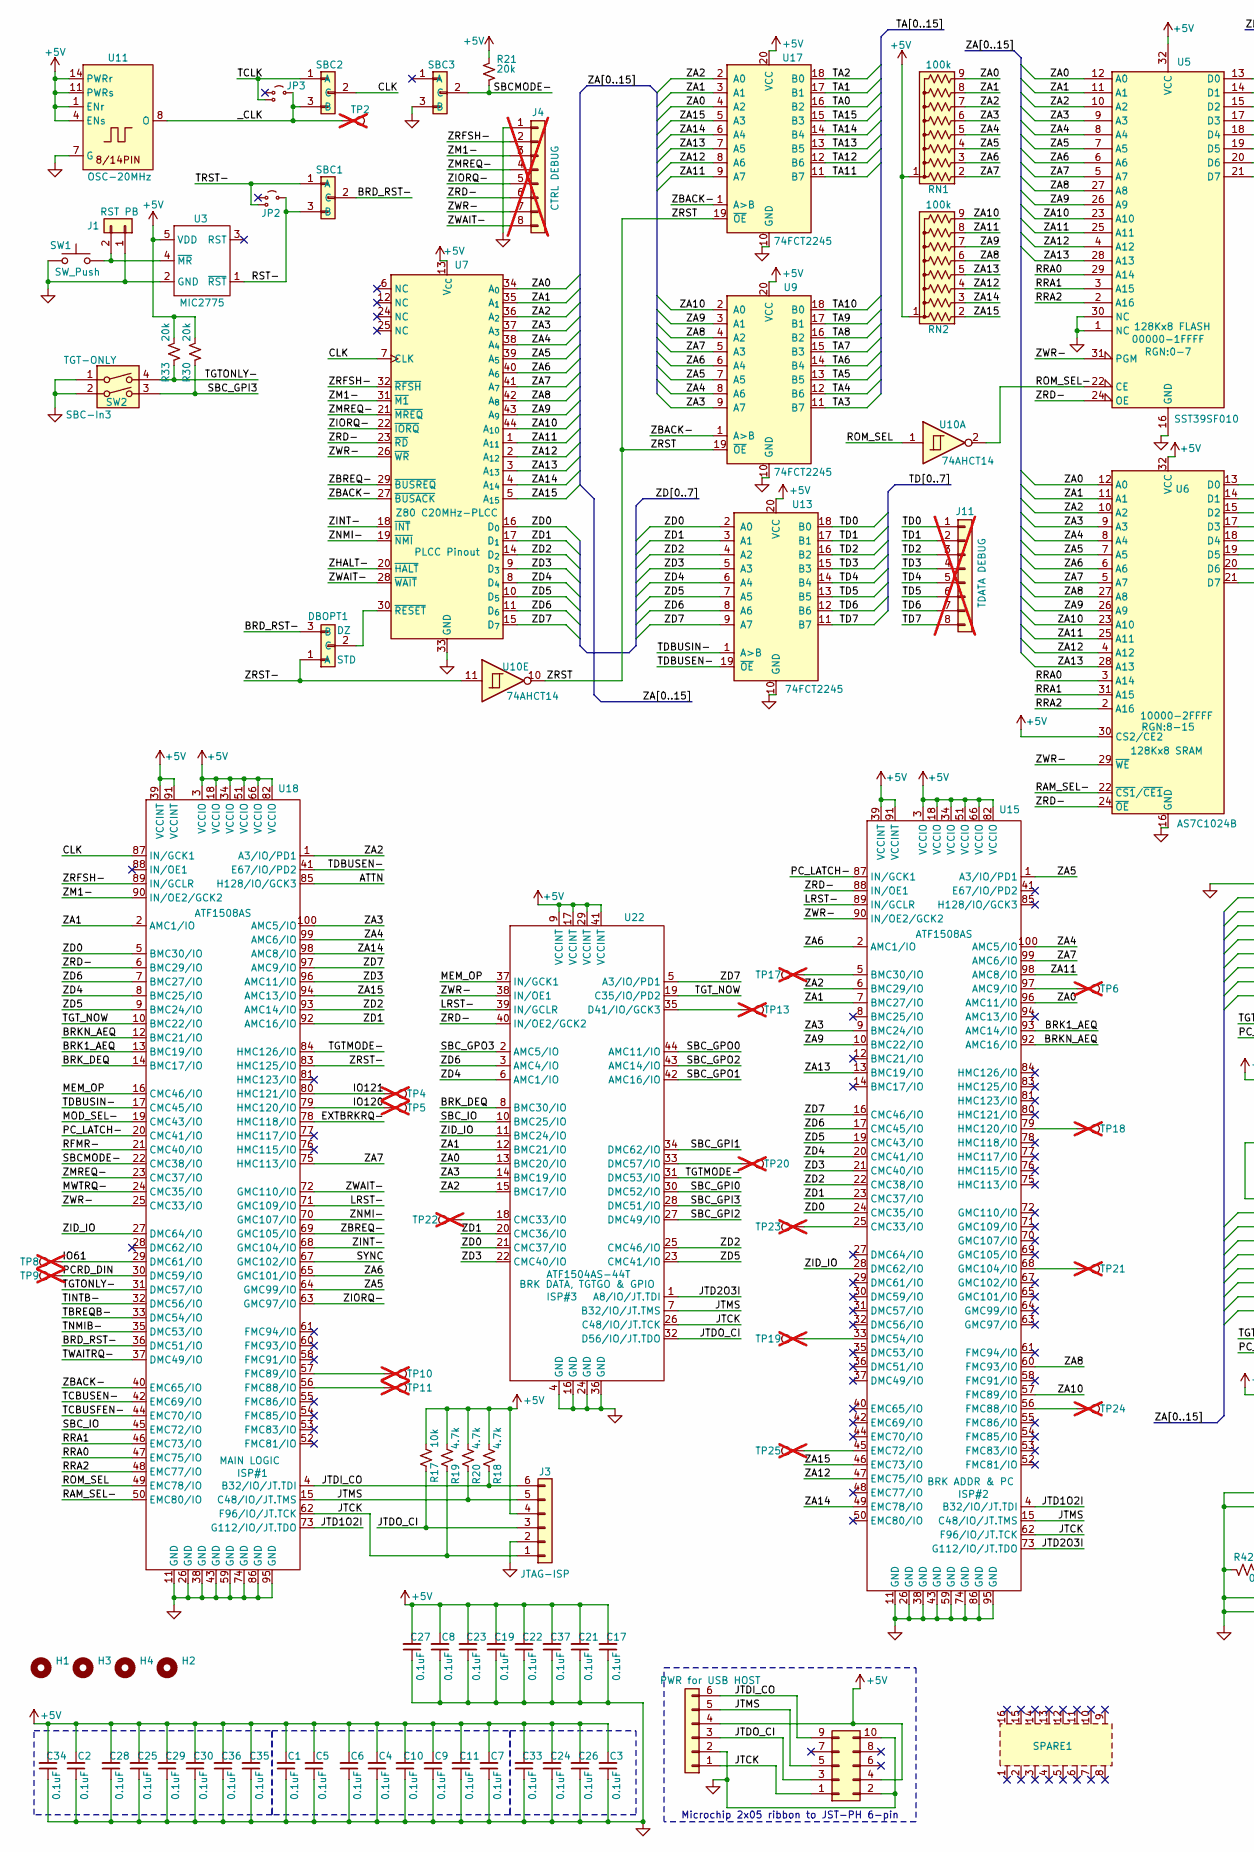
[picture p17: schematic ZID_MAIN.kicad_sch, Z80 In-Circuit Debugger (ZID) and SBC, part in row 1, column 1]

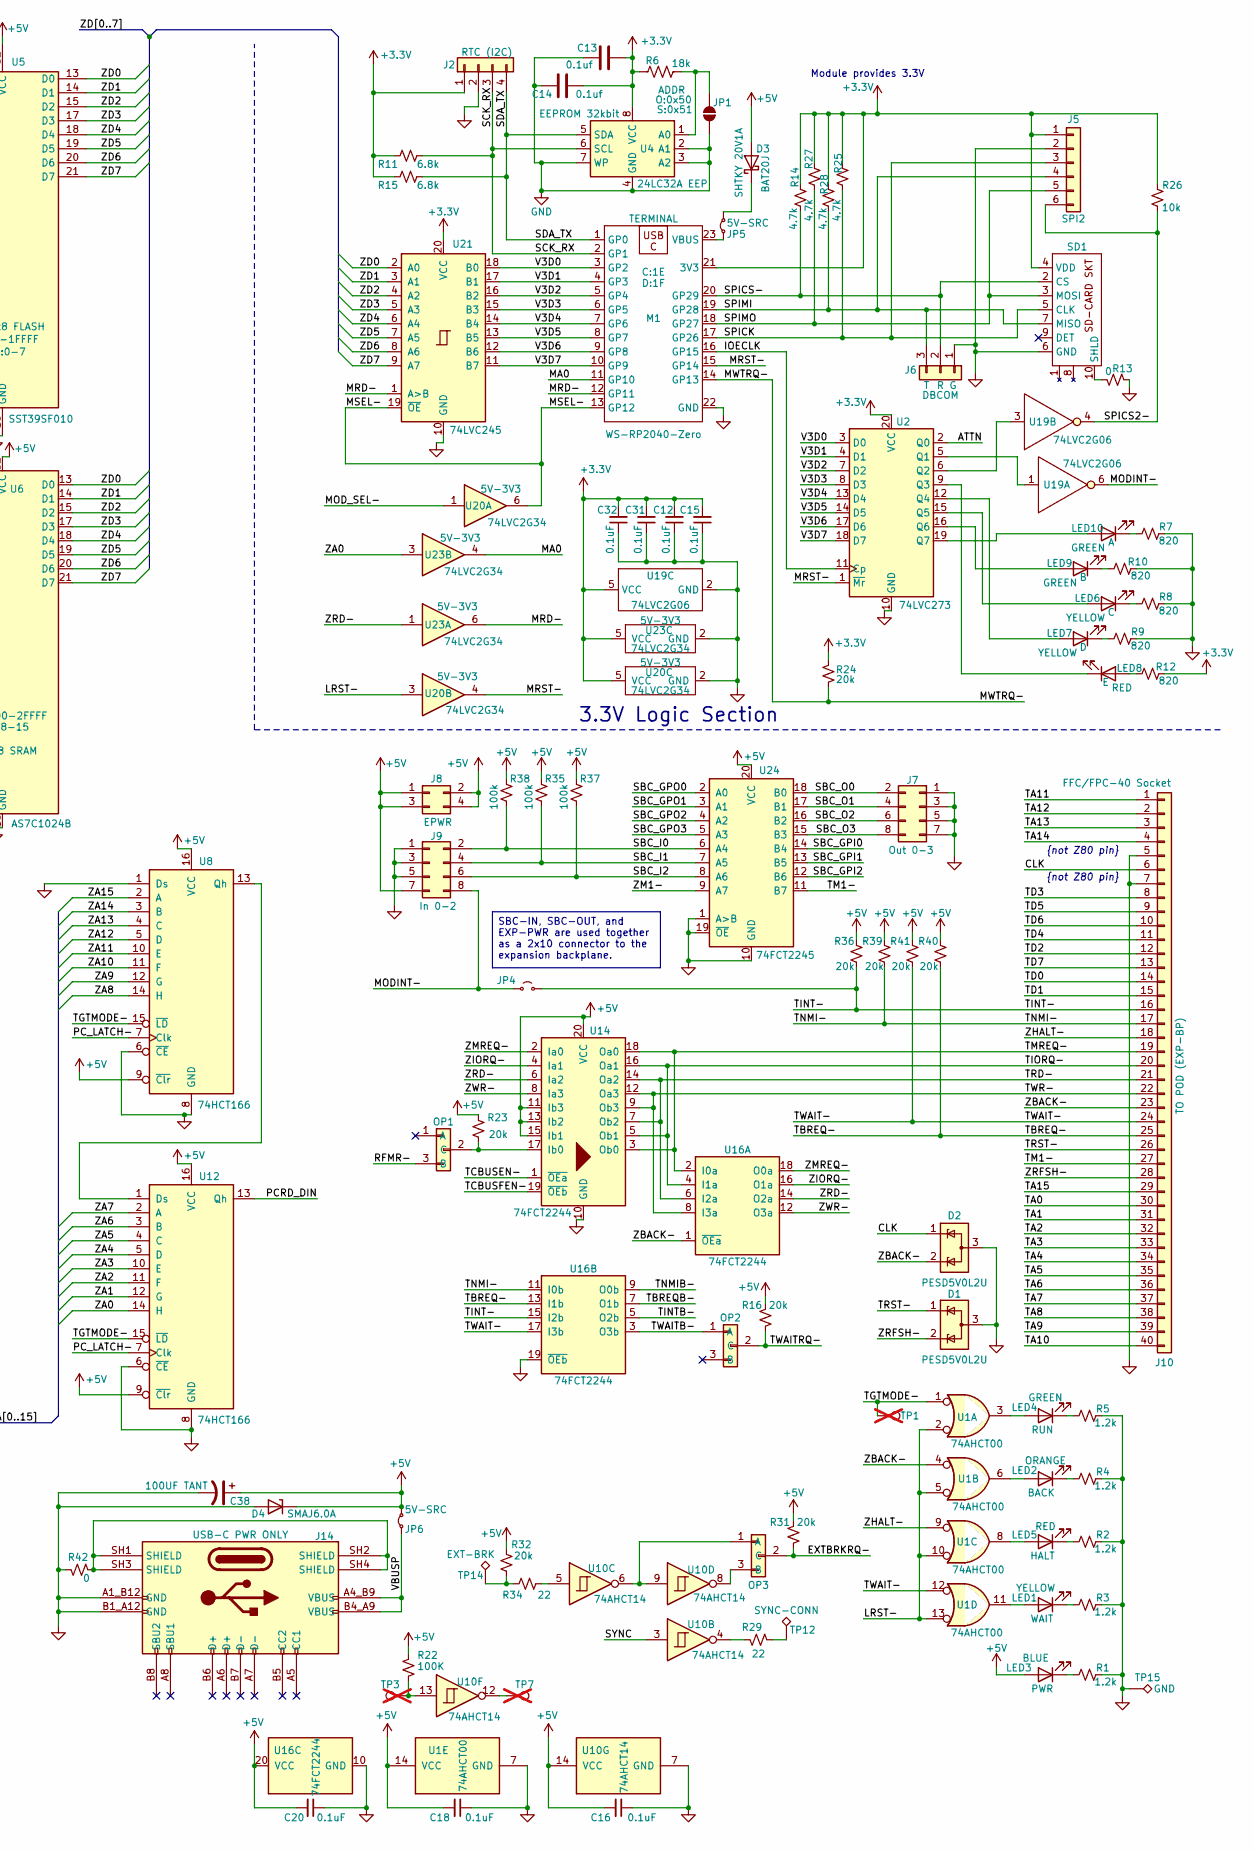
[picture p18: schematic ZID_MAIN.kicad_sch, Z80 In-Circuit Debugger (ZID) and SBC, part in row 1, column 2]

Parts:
C1, C2, C3, C4, C5, C6, C7, C8, C9, C10, C11, C12, C15, C16, C17, C18, C19, C20, C21, C22, C23, C24, C25, C26, C27, C28, C29, C30, C31, C32, C33, C34, C35, C36, C37: 0.1uF; C_0603_1608Metric
C13, C14: 0.1uf; C_0603_1608Metric
C38: 100UF TANT; CP_EIA-7343-31_Kemet-D_HandSolder
D1, D2: PESD5V0L2U; SOT-323_SC-70
D3: BAT20J; D_SOD-323_HandSoldering
D4: SMAJ6.0A; D_SMA
DBOPT1: AES-Option_A-B_2mm; PinHeader_1x03_P2.00mm_Vertical
H1, H2, H3, H4: MountingHole; MountingHole_3.2mm_M3
J1: Conn 1x02 0.1" pin; PinHeader_1x02_P2.54mm_Vertical
J2: Conn 1x04 0.1" Socket; PinSocket_1x04_P2.54mm_Vertical; Part Ada-DS3231/PCF8523 RTC
J3, J5: JST-PH-K B6B; JST_PH_B6B-PH-K_1x06_P2.00mm_Vertical
J4, J11: Conn 1x08 0.1" pin; PinHeader_1x08_P2.54mm_Vertical; not fitted
J6: Conn 1x03 0.1" pin; PinHeader_1x03_P2.54mm_Vertical
J7, J9: Conn 2x04 0.1" pin; PinHeader_2x04_P2.54mm_Vertical
J8: Conn 2x02 0.1" pin; PinHeader_2x02_P2.54mm_Vertical
J10: FFC/FPC-40 Socket; CviLux_CF25401D0-05-NH_FFC-FPC-AES
J12, J14: USB-C PWR ONLY; AES-USB_C-Molex-BdTopMnt-2171790001
J13: Conn_02x05_PINHDR_2.54mm; IDC-Header_2x05_P2.54mm_Vertical
JP1: SolderJumper_2_Open; SolderJumper-2_P1.3mm_Open_RoundedPad1.0x1.5mm
JP2, JP3: Jumper_2_Small_Open_wsto-AES; PinHeader_1x03_P2.00mm_Vertical
JP4: Jumper_2_Small_Open; PinHeader_1x02_P2.00mm_Vertical
JP5, JP6: Jumper_2_Small_Bridged; PinHeader_1x02_P2.00mm_Vertical
LED1, LED6, LED7: LED YELLOW; LED_0805_2012Metric
LED2: LED ORANGE; LED_0805_2012Metric
LED3: LED BLUE; LED_0805_2012Metric
LED4, LED9, LED10: LED GREEN; LED_0805_2012Metric
LED5, LED8: LED RED; LED_0805_2012Metric
M1: WS-RP2040-Zero; RP2040_WS-ZERO-AES
OP1: AES-Option_A-B_2mm; PinHeader_1x03_P2.00mm_Vertical
OP2, OP3: pin header 1x03 0.1"; PinHeader_1x03_P2.54mm_Vertical
R1, R2, R3, R4, R5: 1.2k; R_0805_2012Metric
R6: 18k; R_0805_2012Metric
R7, R8, R9, R10, R12: 820; R_0805_2012Metric
R11, R15: 6.8k; R_0805_2012Metric
R13, R42: 0; R_0805_2012Metric
R14, R18, R19, R20, R25, R27, R28: 4.7k; R_0805_2012Metric
R16, R21, R23, R24, R30, R31, R32, R33, R36, R39, R40, R41: 20k; R_0805_2012Metric
R17, R26: 10k; R_0805_2012Metric
R22: 100K; R_0805_2012Metric
R29, R34: 22; R_0805_2012Metric
R35, R37, R38: 100k; R_0805_2012Metric
RN1, RN2: 100k; R_Array_SIP9
SBC1, SBC2, SBC3: AES-Option_A-B_2mm; PinHeader_1x03_P2.00mm_Vertical
SD1: SD-CARD Socket; AES-SDCard-GCT_MEM2075-00-140-01-A
SPARE1: SPARE-16-SOT-5_6-AES
SW1: SW_Push; AES-SW_PUSH_SMD_1P1T_NO_45x45mm-CK
SW2: SW_DIP_x02; SW_DIP_SPSTx02_Piano_CTS_Series194-2MSTN_W7.62mm_P2.54mm
TP1: TestPoint; PinHeader_1x01_P2.54mm_Vertical; not fitted
TP2: TestPoint; PinHeader_1x01_P2.00mm_Vertical; not fitted
TP3, TP4, TP5, TP6, TP7, TP8, TP9, TP10, TP11, TP13, TP17, TP18, TP19, TP20, TP21, TP22, TP23, TP24, TP25: TestPoint; TestPoint_THTPad_D1.0mm_Drill0.5mm; not fitted
TP12: SYNC-CONN; PinHeader_1x01_P2.54mm_Vertical
TP14: EXT-BRK; PinHeader_1x01_P2.54mm_Vertical
TP15: GND-CONN; PinHeader_1x01_P2.54mm_Vertical
U1: 74AHCT00; SO-14_3.9x8.65mm_P1.27mm
U2: 74LVC273; SO-20_12.8x7.5mm_P1.27mm
U3: MIC2775; SOT-23-5
U4: 24LC32A EEP; SOIC-8_3.9x4.9mm_P1.27mm
U5: SST39SF010; DIP-32_W15.24mm_Socket_LongPads
U6: AS7C1024B; SOJ-32_WN-AES
U7: Z80 C20MHz-PLCC; PLCC-44_THT-Socket
U8, U12: 74HCT166; SOIC-16_3.9x9.9mm_P1.27mm
U9, U13, U17, U24: 74FCT2245; SSOP-20_3.9x8.7mm_P0.635mm
U10: 74AHCT14; SO-14_3.9x8.65mm_P1.27mm
U11: OSC-20MHz; OSC-8_14-CO-AES
U14, U16: 74FCT2244; SSOP-20_3.9x8.7mm_P0.635mm
U15, U18: ATF1508AS; TQFP-100_14x14mm_P0.5mm
U19: 74LVC2G06; SOT-363_SC-70-6
U20, U23: 74LVC2G34; SOT-23-6
U21: 74LVC245; SO-20_5.3x12.6mm_P1.27mm
U22: ATF1504AS-44T; TQFP-44_10x10mm_P0.8mm

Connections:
+3.3V: C12.2, C13.1, C14.2, C15.2, C31.2, C32.2, J2.1, J5.1, M1.21 (3V3), R6.1, R11.2, R12.2, R14.2, R15.2, R24.1, R25.2, R26.2, R27.2, R28.2, SD1.4 (VDD), U2.20 (VCC), U4.8 (VCC), U19.5 (VCC), U20.5 (VCC), U21.20 (VCC), U23.5 (VCC)
+5V: C1.2, C2.2, C3.2, C4.2, C5.2, C6.2, C7.2, C8.2, C9.2, C10.2, C11.2, C16.2, C17.2, C18.2, C19.2, C20.2, C21.2, C22.2, C23.2, C24.2, C25.2, C26.2, C27.2, C28.2, C29.2, C30.2, C33.2, C34.2, C35.2, C36.2, C37.2, C38.1, D3.2 (A), D4.1 (K), J3.4, J8.1, J8.2, J8.3, J8.4, J9.7, J12.4, J13.4, JP6.2 (B), LED3.2 (A), R16.2, R17.1, R18.1, R19.1, R20.1, R21.2, R22.2, R23.2, R30.1, R31.2, R32.1, R33.1, R35.1, R36.1, R37.1, R38.1, R39.1, R40.1, R41.1, RN1.1 (common), RN2.1 (common), U1.14 (VCC), U3.5 (VDD), U5.32 (VCC), U6.30 (CS2/CE2), U6.32 (VCC), U7.13 (V_{CC}), U8.9 (~Clr), U8.16 (VCC), U9.20 (VCC), U10.14 (VCC), U11.1 (ENr), U11.4 (ENs), U11.11 (PWRs), U11.14 (PWRr), U12.9 (~Clr), U12.16 (VCC), U13.20 (VCC), U14.11 (Ib3), U14.13 (Ib2), U14.15 (Ib1), U14.20 (VCC), U15.3 (VCCIO), U15.18 (VCCIO), U15.34 (VCCIO), U15.39 (VCCINT), U15.51 (VCCIO), U15.66 (VCCIO), U15.82 (VCCIO), U15.91 (VCCINT), U16.20 (VCC), U17.20 (VCC), U18.3 (VCCIO), U18.18 (VCCIO), U18.34 (VCCIO), U18.39 (VCCINT), U18.51 (VCCIO), U18.66 (VCCIO), U18.82 (VCCIO), U18.91 (VCCINT), U22.9 (VCCINT), U22.17 (VCCINT), U22.29 (VCCINT), U22.41 (VCCINT), U24.20 (VCC)
/ATTN: U2.2 (Q0), U18.85 (H128/IO/GCK3)
/BRD_RST-: DBOPT1.3 (B), SBC1.2 (C), U18.36 (DMC51/IO)
/BRK1_AEQ: U15.93 (AMC14/IO), U18.13 (BMC19/IO)
/BRKN_AEQ: U15.92 (AMC16/IO), U18.12 (BMC21/IO)
/BRK_DEQ: U18.14 (BMC17/IO), U22.8 (BMC30/IO)
/CLK: D2.1 (K), J10.6, SBC2.2 (C), U7.7 (CLK), U18.87 (IN/GCK1)
/EXTBRKRQ-: OP3.2 (C), R31.1, U18.78 (HMC118/IO)
/IO61: TP8.1, U18.29 (DMC61/IO)
/IO120: TP5.1, U18.79 (HMC120/IO)
/IO121: TP4.1, U18.80 (HMC121/IO)
/IOECLK: M1.16 (GP15), U2.11 (Cp)
/JTCK: J3.1, J12.1, J13.1, R19.2, U15.62 (F96/IO/JT.TCK), U18.62 (F96/IO/JT.TCK), U22.26 (C48/IO/JT.TCK)
/JTD1O2I: U15.4 (B32/IO/JT.TDI), U18.73 (G112/IO/JT.TDO)
/JTD2O3I: U15.73 (G112/IO/JT.TDO), U22.1 (A8/IO/JT.TDI)
/JTDI_CO: J3.6, J12.6, J13.9, R18.2, U18.4 (B32/IO/JT.TDI)
/JTDO_CI: J3.3, J12.3, J13.3, R17.2, U22.32 (D56/IO/JT.TDO)
/JTMS: J3.5, J12.5, J13.5, R20.2, U15.15 (C48/IO/JT.TMS), U18.15 (C48/IO/JT.TMS), U22.7 (B32/IO/JT.TMS)
/LRST-: U1.2, U1.5, U1.10, U1.13, U15.89 (IN/GCLR), U18.71 (GMC109/IO), U20.3, U22.39 (IN/GCLR)
/MA0: M1.11 (GP10), U23.4
/MEM_OP: U18.16 (CMC46/IO), U22.37 (IN/GCK1)
/MODINT-: J9.8, JP4.1 (A), U19.6
/MOD_SEL-: U18.19 (CMC43/IO), U20.1
/MRD-: M1.12 (GP11), U21.1 (A>B), U23.6
/MRST-: M1.15 (GP14), U2.1 (~Mr), U20.4
/MSEL-: M1.13 (GP12), U20.6, U21.19 (~OE)
/MWTRQ-: M1.14 (GP13), R24.2, U18.24 (CMC35/IO)
/PCRD_DIN: TP9.1, U12.13 (Qh), U18.30 (DMC59/IO)
/PC_LATCH-: U8.7 (Clk), U12.7 (Clk), U15.87 (IN/GCK1), U18.20 (CMC41/IO)
/RAM_SEL-: U6.22 (~CS1/~CE1), U18.50 (EMC80/IO)
/RFMR-: OP1.3 (B), U18.21 (CMC40/IO)
/ROM_SEL: U10.1, U18.49 (EMC78/IO)
/ROM_SEL-: U5.22 (CE), U10.2
/RRA0: U5.29 (A14), U6.3 (A14), U18.47 (EMC75/IO)
/RRA1: U5.3 (A15), U6.31 (A15), U18.46 (EMC73/IO)
/RRA2: U5.2 (A16), U6.2 (A16), U18.48 (EMC77/IO)
/RST-: JP2.2 (B), SBC1.3 (B), U3.1 (~RST)
/SBCMODE-: R21.1, SBC3.2 (C), U18.22 (CMC38/IO)
/SBC_GPI0: U22.30 (DMC52/IO), U24.14 (B4)
/SBC_GPI1: U22.34 (DMC62/IO), U24.13 (B5)
/SBC_GPI2: U22.27 (DMC49/IO), U24.12 (B6)
/SBC_GPI3: R30.2, SW2.3, U22.28 (DMC51/IO)
/SBC_GPO0: U22.44 (AMC11/IO), U24.2 (A0)
/SBC_GPO1: U22.42 (AMC16/IO), U24.3 (A1)
/SBC_GPO2: U22.43 (AMC14/IO), U24.4 (A2)
/SBC_GPO3: U22.2 (AMC5/IO), U24.5 (A3)
/SBC_I0: J9.2, R38.2, U24.6 (A4)
/SBC_I1: J9.4, R35.2, U24.7 (A5)
/SBC_I2: J9.6, R37.2, U24.8 (A6)
/SBC_IO: U18.45 (EMC72/IO), U22.10 (BMC25/IO)
/SBC_O0: J7.2, U24.18 (B0)
/SBC_O1: J7.4, U24.17 (B1)
/SBC_O2: J7.6, U24.16 (B2)
/SBC_O3: J7.8, U24.15 (B3)
/SCK_RX: J2.3, M1.2 (GP1), R11.1, U4.6 (SCL)
/SDA_TX: J2.4, M1.1 (GP0), R15.1, U4.5 (SDA)
/SPICK: J5.3, M1.17 (GP26), R25.1, SD1.5 (CLK)
/SPICS2-: J5.6, R26.1, U19.4
/SPICS-: J6.2, M1.20 (GP29), R14.1, SD1.2 (CS)
/SPIMI: J5.4, J6.3, M1.19 (GP28), R28.1, SD1.7 (MISO)
/SPIMO: J5.5, M1.18 (GP27), R27.1, SD1.3 (MOSI)
/SYNC: U10.3, U18.67 (GMC102/IO)
/TA0: J10.30, U17.16 (B2)
/TA1: J10.31, U17.17 (B1)
/TA2: J10.32, U17.18 (B0)
/TA3: J10.33, U9.11 (B7)
/TA4: J10.34, U9.12 (B6)
/TA5: J10.35, U9.13 (B5)
/TA6: J10.36, U9.14 (B4)
/TA7: J10.37, U9.15 (B3)
/TA8: J10.38, U9.16 (B2)
/TA9: J10.39, U9.17 (B1)
/TA10: J10.40, U9.18 (B0)
/TA11: J10.1, U17.11 (B7)
/TA12: J10.2, U17.12 (B6)
/TA13: J10.3, U17.13 (B5)
/TA14: J10.4, U17.14 (B4)
/TA15: J10.29, U17.15 (B3)
/TBREQ-: J10.25, R40.2, U16.13 (I1b)
/TBREQB-: U16.7 (O1b), U18.33 (DMC54/IO)
/TCBUSEN-: U14.1 (~OEa), U18.42 (EMC69/IO)
/TCBUSFEN-: U14.19 (~OEb), U18.44 (EMC70/IO)
/TCLK: JP3.3 (C), SBC2.1 (A)
/TD0: J10.14, J11.1, U13.18 (B0)
/TD1: J10.15, J11.2, U13.17 (B1)
/TD2: J10.12, J11.3, U13.16 (B2)
/TD3: J10.8, J11.4, U13.15 (B3)
/TD4: J10.11, J11.5, U13.14 (B4)
/TD5: J10.9, J11.6, U13.13 (B5)
/TD6: J10.10, J11.7, U13.12 (B6)
/TD7: J10.13, J11.8, U13.11 (B7)
/TDBUSEN-: U13.19 (~OE), U18.41 (E67/IO/PD2)
/TDBUSIN-: U13.1 (A>B), U18.17 (CMC45/IO)
/TGTMODE-: TP1.1, U1.1, U8.15 (~LD), U12.15 (~LD), U18.84 (HMC126/IO), U22.31 (DMC53/IO)
/TGTONLY-: R33.2, SW2.4, U18.31 (DMC57/IO)
/TGT_NOW: U18.10 (BMC22/IO), U22.19 (C35/IO/PD2)
/TINT-: J10.16, JP4.2 (B), R36.2, U16.15 (I2b)
/TINTB-: U16.5 (O2b), U18.32 (DMC56/IO)
/TIORQ-: J10.20, U14.5 (Ob1), U14.16 (Oa1), U16.4 (I1a)
/TM1-: J10.27, U24.11 (B7)
/TMREQ-: J10.19, U14.3 (Ob0), U14.18 (Oa0), U16.2 (I0a)
/TNMI-: J10.17, R39.2, U16.11 (I0b)
/TNMIB-: U16.9 (O0b), U18.35 (DMC53/IO)
/TRD-: J10.21, U14.7 (Ob2), U14.14 (Oa2), U16.6 (I2a)
/TRST-: D1.1 (K), J10.26, JP2.3 (C), SBC1.1 (A)
/TWAIT-: J10.24, R41.2, U1.12, U16.17 (I3b)
/TWAITB-: OP2.1 (A), U16.3 (O3b)
/TWAITRQ-: OP2.2 (C), R16.1, U18.37 (DMC49/IO)
/TWR-: J10.22, U14.9 (Ob3), U14.12 (Oa3), U16.8 (I3a)
/V3D0: M1.3 (GP2), U2.3 (D0), U21.18 (B0)
/V3D1: M1.4 (GP3), U2.4 (D1), U21.17 (B1)
/V3D2: M1.5 (GP4), U2.7 (D2), U21.16 (B2)
/V3D3: M1.6 (GP5), U2.8 (D3), U21.15 (B3)
/V3D4: M1.7 (GP6), U2.13 (D4), U21.14 (B4)
/V3D5: M1.8 (GP7), U2.14 (D5), U21.13 (B5)
/V3D6: M1.9 (GP8), U2.17 (D6), U21.12 (B6)
/V3D7: M1.10 (GP9), U2.18 (D7), U21.11 (B7)
/VBUSP: J14.A4_B9 (VBUS), J14.B4_A9 (VBUS), JP6.1 (A)
/ZA0: RN1.9 (R8), U5.12 (A0), U6.12 (A0), U7.34 (A_{0}), U12.14 (H), U15.96 (AMC11/IO), U17.4 (A2), U22.13 (BMC20/IO), U23.3
/ZA1: RN1.8 (R7), U5.11 (A1), U6.11 (A1), U7.35 (A_{1}), U12.12 (G), U15.7 (BMC27/IO), U17.3 (A1), U18.2 (AMC1/IO), U22.12 (BMC21/IO)
/ZA2: RN1.7 (R6), U5.10 (A2), U6.10 (A2), U7.36 (A_{2}), U12.11 (F), U15.6 (BMC29/IO), U17.2 (A0), U18.1 (A3/IO/PD1), U22.15 (BMC17/IO)
/ZA3: RN1.6 (R5), U5.9 (A3), U6.9 (A3), U7.37 (A_{3}), U9.9 (A7), U12.10 (E), U15.9 (BMC24/IO), U18.100 (AMC5/IO), U22.14 (BMC19/IO)
/ZA4: RN1.5 (R4), U5.8 (A4), U6.8 (A4), U7.38 (A_{4}), U9.8 (A6), U12.5 (D), U15.100 (AMC5/IO), U18.99 (AMC6/IO)
/ZA5: RN1.4 (R3), U5.7 (A5), U6.7 (A5), U7.39 (A_{5}), U9.7 (A5), U12.4 (C), U15.1 (A3/IO/PD1), U18.64 (GMC99/IO)
/ZA6: RN1.3 (R2), U5.6 (A6), U6.6 (A6), U7.40 (A_{6}), U9.6 (A4), U12.3 (B), U15.2 (AMC1/IO), U18.65 (GMC101/IO)
/ZA7: RN1.2 (R1), U5.5 (A7), U6.5 (A7), U7.41 (A_{7}), U9.5 (A3), U12.2 (A), U15.99 (AMC6/IO), U18.75 (HMC113/IO)
/ZA8: RN2.6 (R5), U5.27 (A8), U6.27 (A8), U7.42 (A_{8}), U8.14 (H), U9.4 (A2), U15.60 (FMC93/IO)
/ZA9: RN2.7 (R6), U5.26 (A9), U6.26 (A9), U7.43 (A_{9}), U8.12 (G), U9.3 (A1), U15.10 (BMC22/IO)
/ZA10: RN2.9 (R8), U5.23 (A10), U6.23 (A10), U7.44 (A_{10}), U8.11 (F), U9.2 (A0), U15.57 (FMC89/IO)
/ZA11: RN2.8 (R7), U5.25 (A11), U6.25 (A11), U7.1 (A_{11}), U8.10 (E), U15.98 (AMC8/IO), U17.9 (A7)
/ZA12: RN2.4 (R3), U5.4 (A12), U6.4 (A12), U7.2 (A_{12}), U8.5 (D), U15.47 (EMC75/IO), U17.8 (A6)
/ZA13: RN2.5 (R4), U5.28 (A13), U6.28 (A13), U7.3 (A_{13}), U8.4 (C), U15.13 (BMC19/IO), U17.7 (A5)
/ZA14: RN2.3 (R2), U7.4 (A_{14}), U8.3 (B), U15.49 (EMC78/IO), U17.6 (A4), U18.98 (AMC8/IO)
/ZA15: RN2.2 (R1), U7.5 (A_{15}), U8.2 (A), U15.46 (EMC73/IO), U17.5 (A3), U18.94 (AMC13/IO)
/ZBACK-: D2.2 (K), J10.23, U1.4, U7.27 (~BUSACK), U9.1 (A>B), U16.1 (~OEa), U17.1 (A>B), U18.40 (EMC65/IO)
/ZBREQ-: U7.29 (~BUSREQ), U18.69 (GMC105/IO)
/ZD0: U5.13 (D0), U6.13 (D0), U7.16 (D_{0}), U13.2 (A0), U15.24 (CMC35/IO), U18.5 (BMC30/IO), U21.2 (A0), U22.21 (CMC37/IO)
/ZD1: U5.14 (D1), U6.14 (D1), U7.17 (D_{1}), U13.3 (A1), U15.23 (CMC37/IO), U18.92 (AMC16/IO), U21.3 (A1), U22.20 (CMC36/IO)
/ZD2: U5.15 (D2), U6.15 (D2), U7.14 (D_{2}), U13.4 (A2), U15.22 (CMC38/IO), U18.93 (AMC14/IO), U21.4 (A2), U22.25 (CMC46/IO)
/ZD3: U5.17 (D3), U6.17 (D3), U7.9 (D_{3}), U13.5 (A3), U15.21 (CMC40/IO), U18.96 (AMC11/IO), U21.5 (A3), U22.22 (CMC40/IO)
/ZD4: U5.18 (D4), U6.18 (D4), U7.8 (D_{4}), U13.6 (A4), U15.20 (CMC41/IO), U18.8 (BMC25/IO), U21.6 (A4), U22.6 (AMC1/IO)
/ZD5: U5.19 (D5), U6.19 (D5), U7.10 (D_{5}), U13.7 (A5), U15.19 (CMC43/IO), U18.9 (BMC24/IO), U21.7 (A5), U22.23 (CMC41/IO)
/ZD6: U5.20 (D6), U6.20 (D6), U7.11 (D_{6}), U13.8 (A6), U15.17 (CMC45/IO), U18.7 (BMC27/IO), U21.8 (A6), U22.3 (AMC4/IO)
/ZD7: U5.21 (D7), U6.21 (D7), U7.15 (D_{7}), U13.9 (A7), U15.16 (CMC46/IO), U18.97 (AMC9/IO), U21.9 (A7), U22.5 (A3/IO/PD1)
/ZHALT-: J10.18, U1.9, U7.20 (~HALT)
/ZID_IO: U15.28 (DMC62/IO), U18.27 (DMC64/IO), U22.11 (BMC24/IO)
/ZINT-: U7.18 (~INT), U18.68 (GMC104/IO)
/ZIORQ-: J4.5, U7.22 (~IORQ), U14.4 (Ia1), U16.16 (O1a), U18.63 (GMC97/IO)
/ZM1-: J4.3, U7.31 (~M1), U18.90 (IN/OE2/GCK2), U24.9 (A7)
/ZMREQ-: J4.4, U7.21 (~MREQ), U14.2 (Ia0), U16.18 (O0a), U18.23 (CMC37/IO)
/ZNMI-: U7.19 (~NMI), U18.70 (GMC107/IO)
/ZRD-: J4.6, U5.24 (OE), U6.24 (~OE), U7.23 (~RD), U14.6 (Ia2), U15.88 (IN/OE1), U16.14 (O2a), U18.6 (BMC29/IO), U22.40 (IN/OE2/GCK2), U23.1
/ZRFSH-: D1.2 (K), J4.2, J10.28, U7.32 (~RFSH), U18.89 (IN/GCLR)
/ZRST: U9.19 (~OE), U10.10, U17.19 (~OE)
/ZRST-: DBOPT1.1 (A), U10.11, U18.83 (HMC125/IO)
/ZWAIT-: J4.8, U7.28 (~WAIT), U18.72 (GMC110/IO)
/ZWR-: J4.7, U5.31 (PGM), U6.29 (~WE), U7.26 (~WR), U14.8 (Ia3), U15.90 (IN/OE2/GCK2), U16.12 (O3a), U18.25 (CMC33/IO), U22.38 (IN/OE1)
/_CLK: JP3.2 (B), SBC2.3 (B), TP2.1, U11.8 (O)
GND: C1.1, C2.1, C3.1, C4.1, C5.1, C6.1, C7.1, C8.1, C9.1, C10.1, C11.1, C12.1, C13.2, C14.1, C15.1, C16.1, C17.1, C18.1, C19.1, C20.1, C21.1, C22.1, C23.1, C24.1, C25.1, C26.1, C27.1, C28.1, C29.1, C30.1, C31.1, C32.1, C33.1, C34.1, C35.1, C36.1, C37.1, C38.2, D1.3 (A), D2.3 (A), D4.2 (A), J1.1, J2.2, J3.2, J4.1, J5.2, J6.1, J7.1, J7.3, J7.5, J7.7, J9.1, J9.3, J9.5, J10.5, J10.7, J12.2, J13.2, J13.10, J14.A1_B12 (GND), J14.B1_A12 (GND), JP1.1 (A), M1.22 (GND), R1.2, R2.2, R3.2, R4.2, R5.2, R7.2, R8.2, R9.2, R10.2, R13.1, R42.1, SBC3.3 (B), SD1.6 (GND), SW1.1, SW2.1, SW2.2, TP15.1, U1.7 (GND), U2.10 (GND), U3.2 (GND), U4.2 (A1), U4.3 (A2), U4.4 (GND), U4.7 (WP), U5.1 (NC), U5.16 (GND), U5.30 (NC), U6.16 (GND), U7.33 (GND), U8.1 (Ds), U8.6 (~CE), U8.8 (GND), U9.10 (GND), U10.7 (GND), U11.7 (G), U12.6 (~CE), U12.8 (GND), U13.10 (GND), U14.10 (GND), U15.11 (GND), U15.26 (GND), U15.38 (GND), U15.43 (GND), U15.59 (GND), U15.74 (GND), U15.86 (GND), U15.95 (GND), U16.10 (GND), U16.19 (~OEb), U17.10 (GND), U18.11 (GND), U18.26 (GND), U18.38 (GND), U18.43 (GND), U18.59 (GND), U18.74 (GND), U18.86 (GND), U18.95 (GND), U19.2 (GND), U20.2 (GND), U21.10 (GND), U22.4 (GND), U22.16 (GND), U22.24 (GND), U22.36 (GND), U23.2 (GND), U24.1 (A>B), U24.10 (GND), U24.19 (~OE)
unnamed: D3.1 (K), JP5.2 (B)
unnamed: DBOPT1.2 (C), U7.30 (~RESET)
unnamed: J1.2, SW1.2, U3.4 (~MR)
unnamed: J14.SH1 (SHIELD), J14.SH2 (SHIELD), J14.SH3 (SHIELD), J14.SH4 (SHIELD), R42.2
unnamed: JP1.2 (B), R6.2, U4.1 (A0)
unnamed: JP5.1 (A), M1.23 (VBUS)
unnamed: LED1.2 (A), U1.11
unnamed: LED1.1 (K), R3.1
unnamed: LED2.2 (A), U1.6
unnamed: LED2.1 (K), R4.1
unnamed: LED3.1 (K), R1.1
unnamed: LED4.2 (A), U1.3
unnamed: LED4.1 (K), R5.1
unnamed: LED5.2 (A), U1.8
unnamed: LED5.1 (K), R2.1
unnamed: LED6.2 (A), U2.15 (Q5)
unnamed: LED6.1 (K), R8.1
unnamed: LED7.2 (A), U2.12 (Q4)
unnamed: LED7.1 (K), R9.1
unnamed: LED8.2 (A), R12.1
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

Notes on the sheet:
3.3V Logic Section
Module provides 3.3V
{not Z80 pin}
SBC-IN, SBC-OUT, and EXP-PWR are used together as a 2x10 connector to the expansion backplane.
Microchip 2x05 ribbon to JST-PH 6-pin

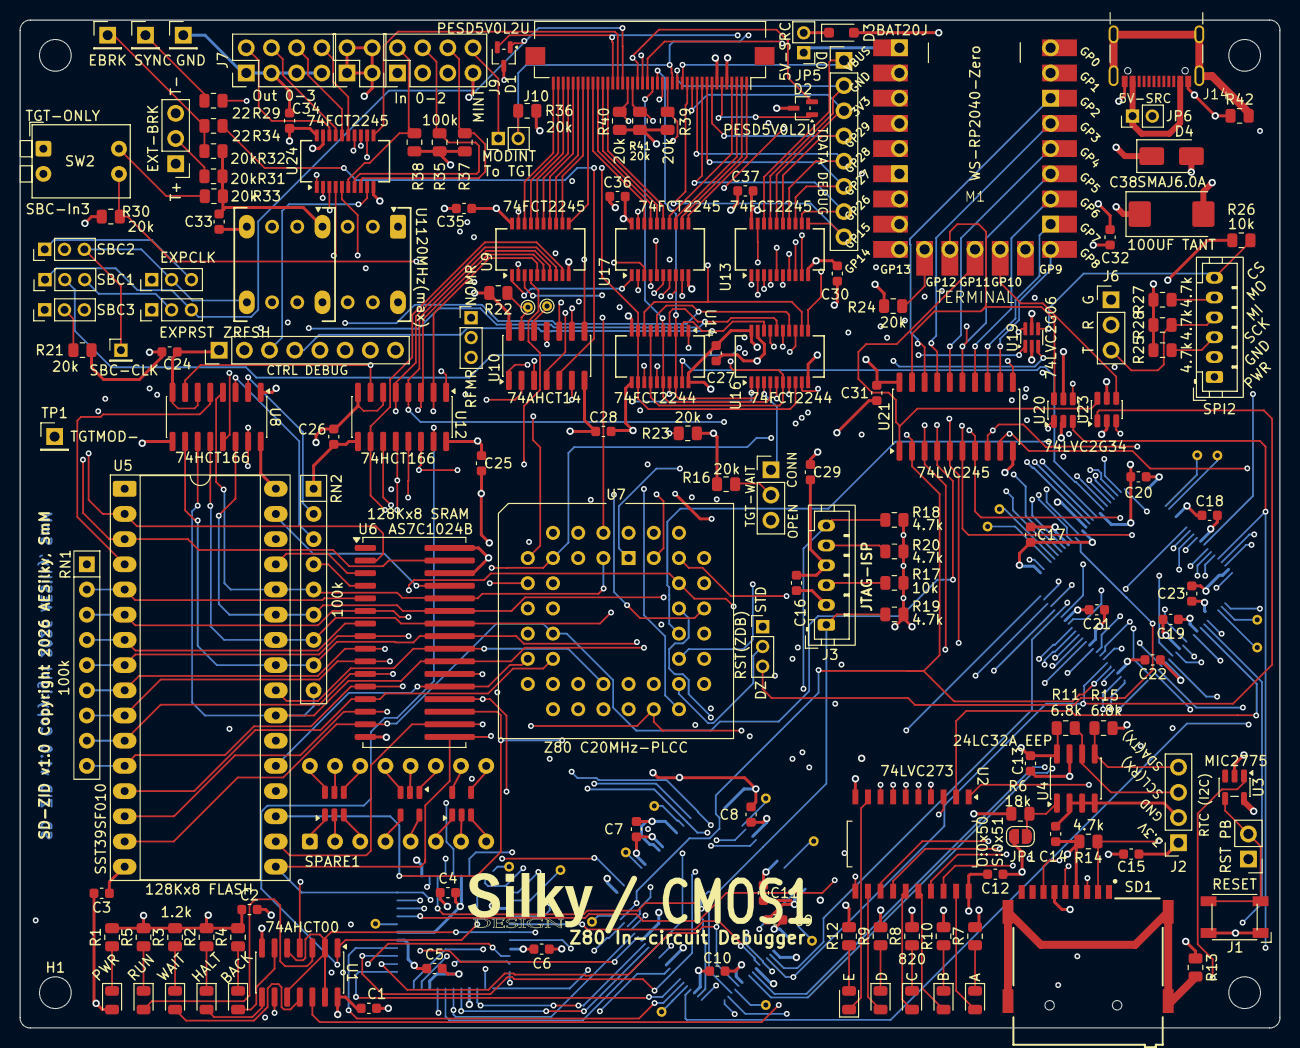
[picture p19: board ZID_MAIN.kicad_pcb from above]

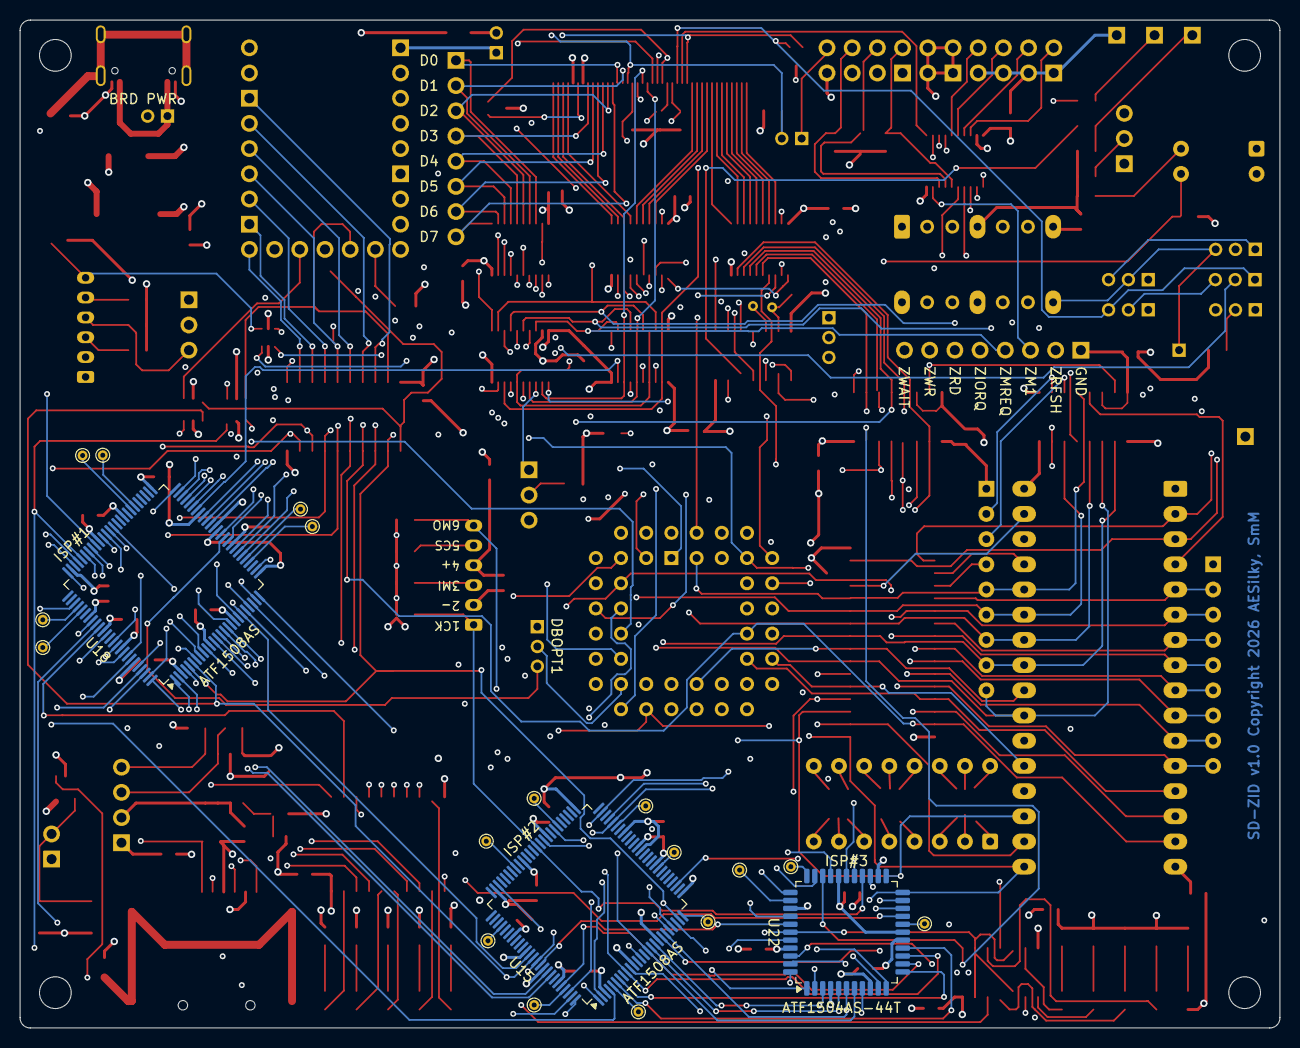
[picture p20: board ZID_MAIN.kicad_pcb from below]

Board: 6 copper layers, 127.0 x 101.6 mm, 178 parts (20 on the bottom side), 211 nets.

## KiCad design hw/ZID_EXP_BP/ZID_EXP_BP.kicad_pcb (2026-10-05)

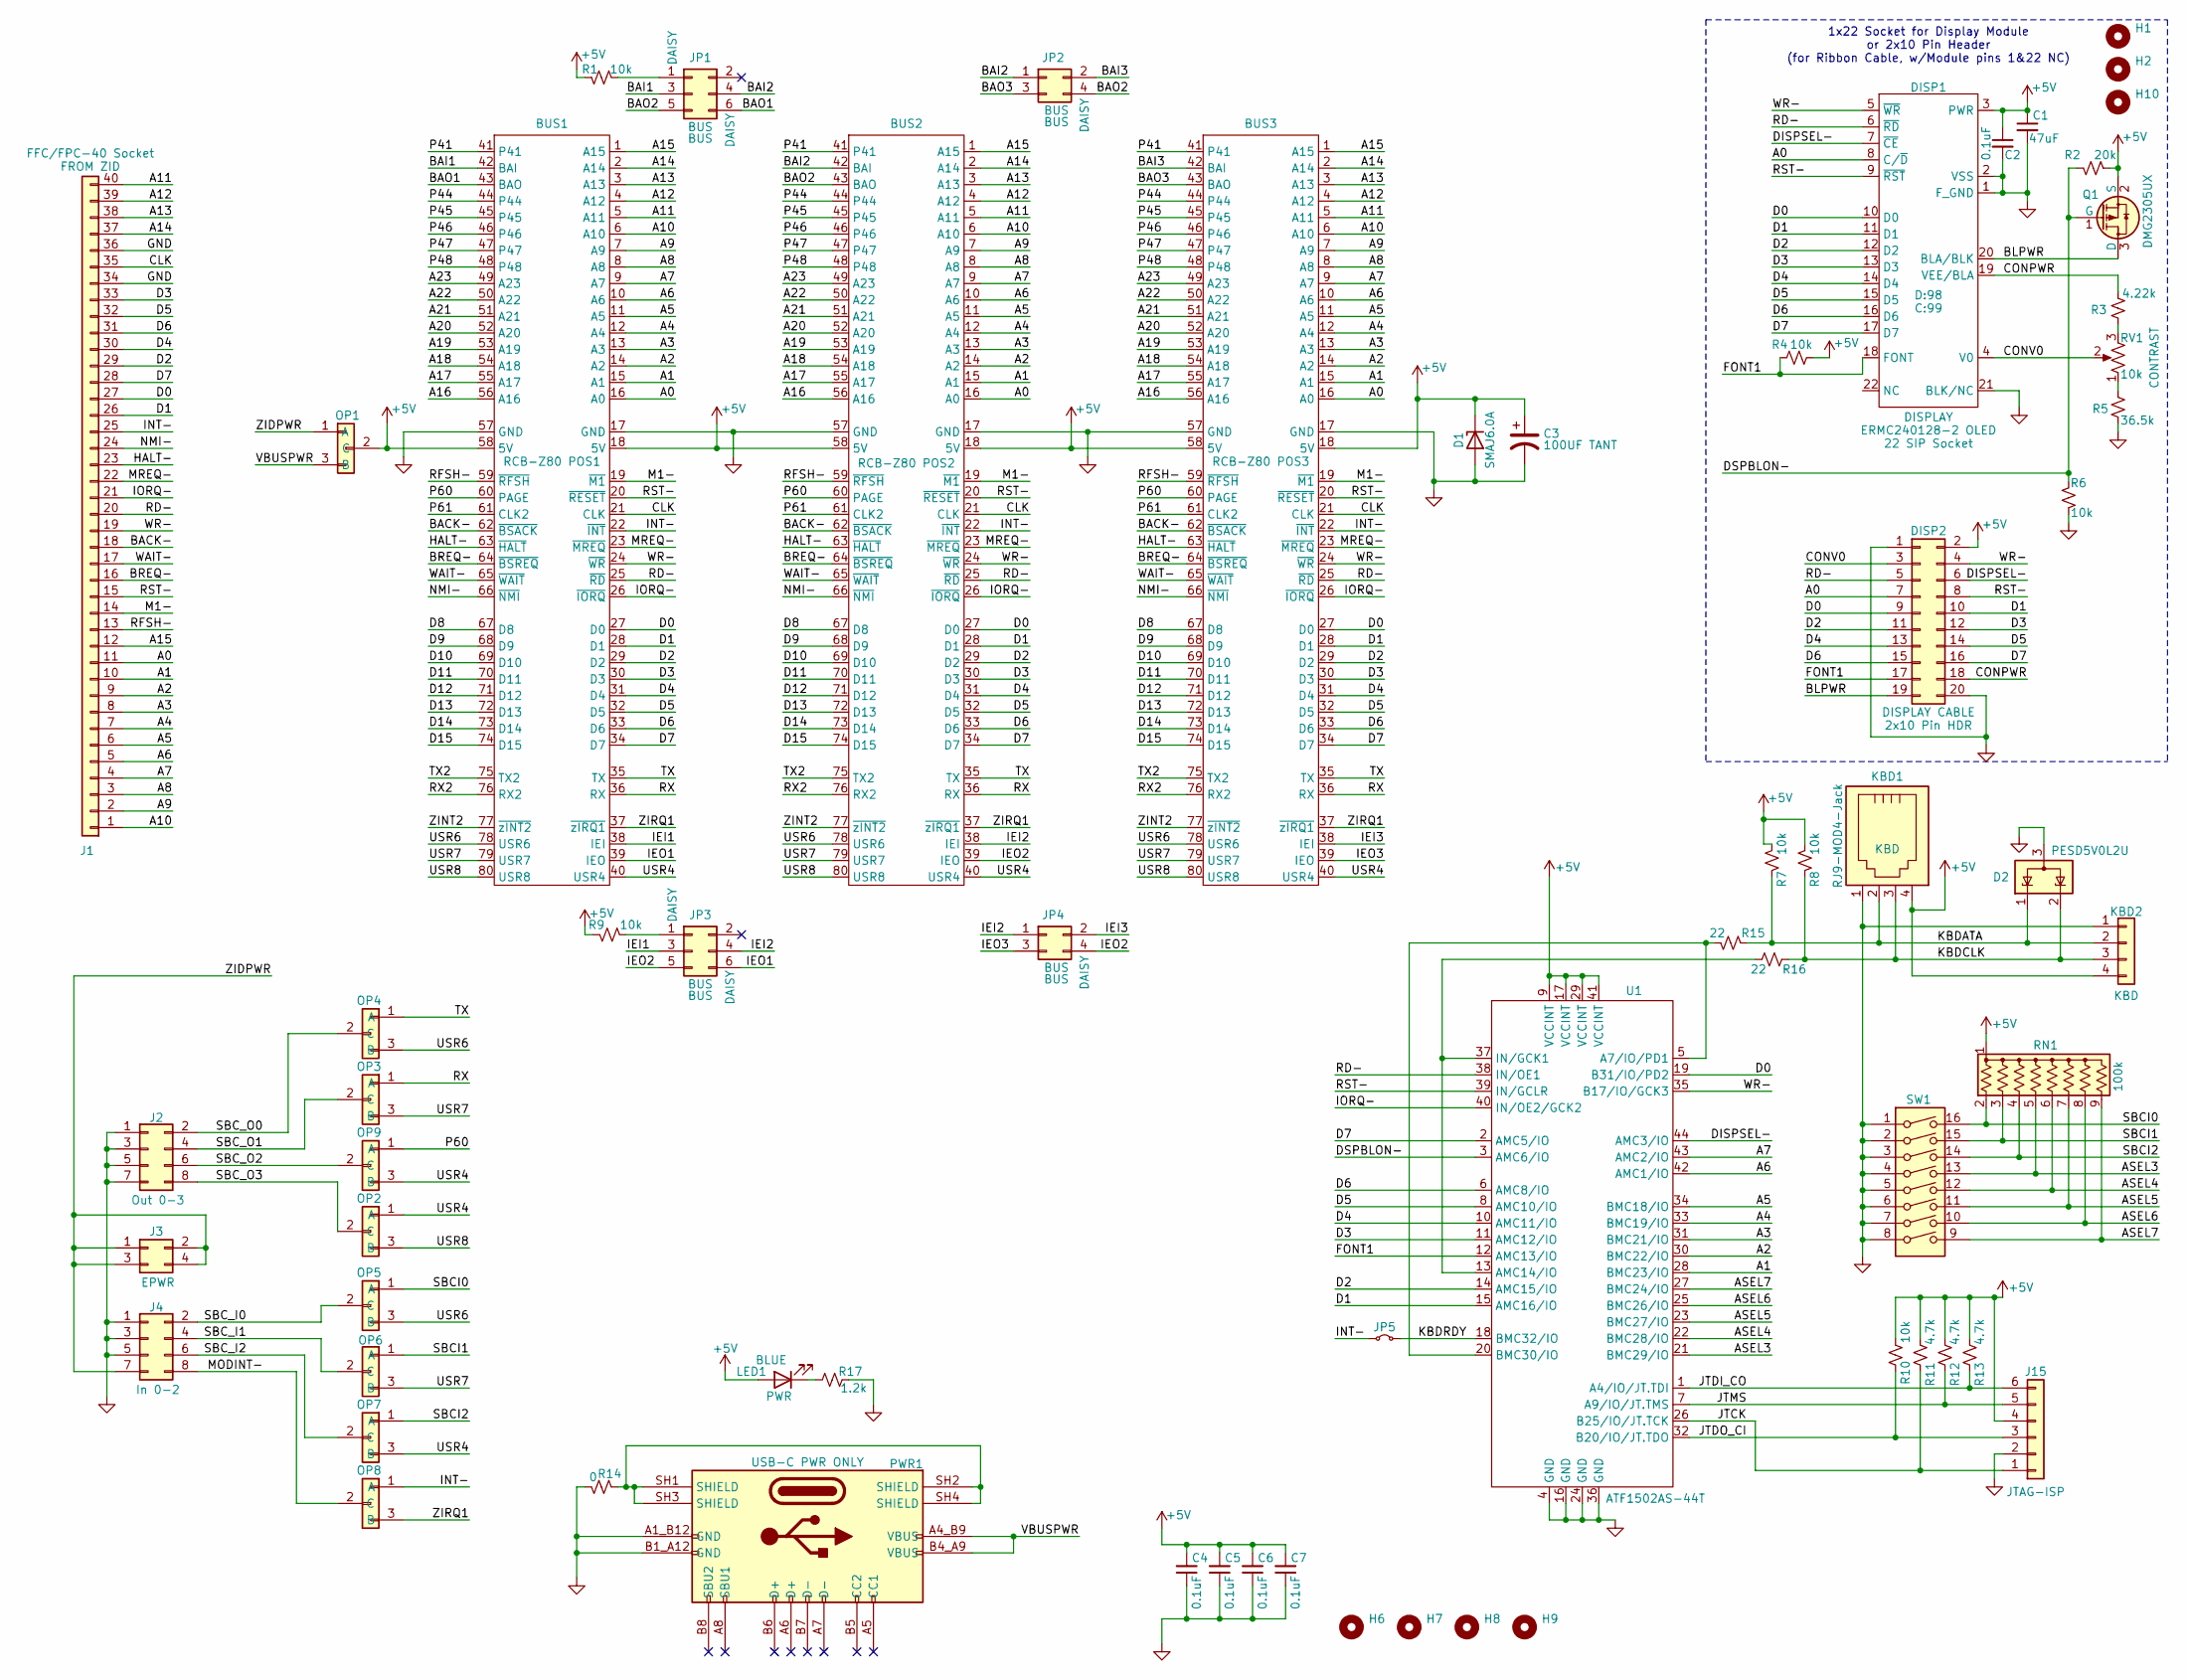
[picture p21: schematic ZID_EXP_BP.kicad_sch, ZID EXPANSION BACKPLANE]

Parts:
BUS1, BUS2, BUS3: RC80-BUS-BPMB-AES
C1: 47uF; C_1210_3225Metric_Pad1.33x2.70mm_HandSolder
C2, C4, C5, C6, C7: 0.1uF; C_0603_1608Metric
C3: 100UF TANT; CP_EIA-7343-31_Kemet-D_HandSolder
D1: SMAJ6.0A; D_SMA
D2: PESD5V0L2U; SOT-323_SC-70
DISP1: DISPLAY; PinSocket_1x22_P2.54mm_Vertical; PartOpt1 22 SIP Socket
DISP2: HDR 2x10 Pin; PinHeader_2x10_P2.54mm_Vertical; PartOpt1 2x10 Pin HDR
H1, H2, H6, H7, H8, H9, H10: MountingHole; MountingHole_3.2mm_M3
J1: FFC/FPC-40 Socket; CviLux_CF25401D0-05-NH_FFC-FPC-AES
J2, J4: Conn 2x04 0.1" pin; PinHeader_2x04_P2.54mm_Vertical
J3: Conn 2x02 0.1" pin; PinHeader_2x02_P2.54mm_Vertical
J15: JST-PH-K B6B; JST_PH_B6B-PH-K_1x06_P2.00mm_Vertical
JP1, JP3: Conn_02x03_Odd_Even; PinHeader_2x03_P2.54mm_Vertical
JP2, JP4: Conn 2x02 HDR Pin 2.54mm; PinHeader_2x02_P2.54mm_Vertical
JP5: Conn 1x02 HDR Pin 2.0mm; PinHeader_1x02_P2.00mm_Vertical
KBD1: RJ9-MOD4-Jack; FCI-68897-001LF-ModJack4-Horz-AES
KBD2: Conn 01x04 Pin hdr 0.1in; PinHeader_1x04_P2.54mm_Vertical
LED1: LED BLUE; LED_0805_2012Metric
OP1, OP2, OP3, OP4, OP5, OP6, OP7, OP8, OP9: AES-Option_A-B; PinHeader_1x03_P2.54mm_Vertical
PWR1: USB-C PWR ONLY; AES-USB_C-Molex-BdTopMnt-2171790001
Q1: DMG2305UX; DMG2305-SOT-23-3-AES
R1, R4, R6, R7, R8, R9, R10: 10k; R_0805_2012Metric
R2: 20k; R_0805_2012Metric
R3: 4.22k; R_0805_2012Metric
R5: 36.5k; R_0805_2012Metric
R11, R12, R13: 4.7k; R_0805_2012Metric
R14: 0; R_0805_2012Metric
R15, R16: 22; R_0805_2012Metric
R17: 1.2k; R_0805_2012Metric
RN1: 100k; R_Array_SIP9
RV1: 10k; Pot-Molence-Amazon-PCB-AES
SW1: SW_DIP_x08; DIP-16_W7.62mm_LongPads
U1: ATF1502AS-44T; TQFP-44_10x10mm_P0.8mm

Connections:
+5V: BUS1.18 (5V), BUS1.58 (5V), BUS2.18 (5V), BUS2.58 (5V), BUS3.18 (5V), BUS3.58 (5V), C1.1, C2.1, C3.1, C4.2, C5.2, C6.2, C7.2, D1.1 (K), DISP1.3 (PWR), DISP2.2, J15.4, KBD1.4, KBD2.4, LED1.2 (A), OP1.2 (C), Q1.2 (S), R1.1, R2.1, R4.2, R7.2, R8.2, R9.1, R10.1, R11.1, R12.1, R13.1, RN1.1 (common), U1.9 (VCCINT), U1.17 (VCCINT), U1.29 (VCCINT), U1.41 (VCCINT)
/A0: BUS1.16 (A0), BUS2.16 (A0), BUS3.16 (A0), DISP1.8 (C/~D), DISP2.7, J1.11
/A1: BUS1.15 (A1), BUS2.15 (A1), BUS3.15 (A1), J1.10, U1.28 (BMC23/IO)
/A2: BUS1.14 (A2), BUS2.14 (A2), BUS3.14 (A2), J1.9, U1.30 (BMC22/IO)
/A3: BUS1.13 (A3), BUS2.13 (A3), BUS3.13 (A3), J1.8, U1.31 (BMC21/IO)
/A4: BUS1.12 (A4), BUS2.12 (A4), BUS3.12 (A4), J1.7, U1.33 (BMC19/IO)
/A5: BUS1.11 (A5), BUS2.11 (A5), BUS3.11 (A5), J1.6, U1.34 (BMC18/IO)
/A6: BUS1.10 (A6), BUS2.10 (A6), BUS3.10 (A6), J1.5, U1.42 (AMC1/IO)
/A7: BUS1.9 (A7), BUS2.9 (A7), BUS3.9 (A7), J1.4, U1.43 (AMC2/IO)
/A8: BUS1.8 (A8), BUS2.8 (A8), BUS3.8 (A8), J1.3
/A9: BUS1.7 (A9), BUS2.7 (A9), BUS3.7 (A9), J1.2
/A10: BUS1.6 (A10), BUS2.6 (A10), BUS3.6 (A10), J1.1
/A11: BUS1.5 (A11), BUS2.5 (A11), BUS3.5 (A11), J1.40
/A12: BUS1.4 (A12), BUS2.4 (A12), BUS3.4 (A12), J1.39
/A13: BUS1.3 (A13), BUS2.3 (A13), BUS3.3 (A13), J1.38
/A14: BUS1.2 (A14), BUS2.2 (A14), BUS3.2 (A14), J1.37
/A15: BUS1.1 (A15), BUS2.1 (A15), BUS3.1 (A15), J1.12
/A16: BUS1.56 (A16), BUS2.56 (A16), BUS3.56 (A16)
/A17: BUS1.55 (A17), BUS2.55 (A17), BUS3.55 (A17)
/A18: BUS1.54 (A18), BUS2.54 (A18), BUS3.54 (A18)
/A19: BUS1.53 (A19), BUS2.53 (A19), BUS3.53 (A19)
/A20: BUS1.52 (A20), BUS2.52 (A20), BUS3.52 (A20)
/A21: BUS1.51 (A21), BUS2.51 (A21), BUS3.51 (A21)
/A22: BUS1.50 (A22), BUS2.50 (A22), BUS3.50 (A22)
/A23: BUS1.49 (A23), BUS2.49 (A23), BUS3.49 (A23)
/ASEL3: RN1.5 (R4), SW1.13, U1.21 (BMC29/IO)
/ASEL4: RN1.6 (R5), SW1.12, U1.22 (BMC28/IO)
/ASEL5: RN1.7 (R6), SW1.11, U1.23 (BMC27/IO)
/ASEL6: RN1.8 (R7), SW1.10, U1.25 (BMC26/IO)
/ASEL7: RN1.9 (R8), SW1.9, U1.27 (BMC24/IO)
/BACK-: BUS1.62 (~BSACK), BUS2.62 (~BSACK), BUS3.62 (~BSACK), J1.18
/BAI1: BUS1.42 (BAI), JP1.3
/BAI2: BUS2.42 (BAI), JP1.4, JP2.1
/BAI3: BUS3.42 (BAI), JP2.2
/BAO1: BUS1.43 (BAO), JP1.6
/BAO2: BUS2.43 (BAO), JP1.5, JP2.4
/BAO3: BUS3.43 (BAO), JP2.3
/BLPWR: DISP1.20 (BLA/BLK), DISP2.19, Q1.3 (D)
/BREQ-: BUS1.64 (~BSREQ), BUS2.64 (~BSREQ), BUS3.64 (~BSREQ), J1.16
/CLK: BUS1.21 (CLK), BUS2.21 (CLK), BUS3.21 (CLK), J1.35
/CONPWR: DISP1.19 (VEE/BLA), DISP2.18, R3.1
/CONV0: DISP1.4 (V0), DISP2.3, RV1.2
/D0: BUS1.27 (D0), BUS2.27 (D0), BUS3.27 (D0), DISP1.10 (D0), DISP2.9, J1.27, U1.19 (B31/IO/PD2)
/D1: BUS1.28 (D1), BUS2.28 (D1), BUS3.28 (D1), DISP1.11 (D1), DISP2.10, J1.26, U1.15 (AMC16/IO)
/D2: BUS1.29 (D2), BUS2.29 (D2), BUS3.29 (D2), DISP1.12 (D2), DISP2.11, J1.29, U1.14 (AMC15/IO)
/D3: BUS1.30 (D3), BUS2.30 (D3), BUS3.30 (D3), DISP1.13 (D3), DISP2.12, J1.33, U1.11 (AMC12/IO)
/D4: BUS1.31 (D4), BUS2.31 (D4), BUS3.31 (D4), DISP1.14 (D4), DISP2.13, J1.30, U1.10 (AMC11/IO)
/D5: BUS1.32 (D5), BUS2.32 (D5), BUS3.32 (D5), DISP1.15 (D5), DISP2.14, J1.32, U1.8 (AMC10/IO)
/D6: BUS1.33 (D6), BUS2.33 (D6), BUS3.33 (D6), DISP1.16 (D6), DISP2.15, J1.31, U1.6 (AMC8/IO)
/D7: BUS1.34 (D7), BUS2.34 (D7), BUS3.34 (D7), DISP1.17 (D7), DISP2.16, J1.28, U1.2 (AMC5/IO)
/D8: BUS1.67 (D8), BUS2.67 (D8), BUS3.67 (D8)
/D9: BUS1.68 (D9), BUS2.68 (D9), BUS3.68 (D9)
/D10: BUS1.69 (D10), BUS2.69 (D10), BUS3.69 (D10)
/D11: BUS1.70 (D11), BUS2.70 (D11), BUS3.70 (D11)
/D12: BUS1.71 (D12), BUS2.71 (D12), BUS3.71 (D12)
/D13: BUS1.72 (D13), BUS2.72 (D13), BUS3.72 (D13)
/D14: BUS1.73 (D14), BUS2.73 (D14), BUS3.73 (D14)
/D15: BUS1.74 (D15), BUS2.74 (D15), BUS3.74 (D15)
/DISPSEL-: DISP1.7 (~CE), DISP2.6, U1.44 (AMC3/IO)
/DSPBLON-: Q1.1 (G), R2.2, R6.1, U1.3 (AMC6/IO)
/FONT1: DISP1.18 (FONT), DISP2.17, R4.1, U1.12 (AMC13/IO)
/HALT-: BUS1.63 (~HALT), BUS2.63 (~HALT), BUS3.63 (~HALT), J1.23
/IEI1: BUS1.38 (IEI), JP3.3
/IEI2: BUS2.38 (IEI), JP3.4, JP4.1
/IEI3: BUS3.38 (IEI), JP4.2
/IEO1: BUS1.39 (IEO), JP3.6
/IEO2: BUS2.39 (IEO), JP3.5, JP4.4
/IEO3: BUS3.39 (IEO), JP4.3
/INT-: BUS1.22 (~INT), BUS2.22 (~INT), BUS3.22 (~INT), J1.25, JP5.2 (B), OP8.1 (A)
/IORQ-: BUS1.26 (~IORQ), BUS2.26 (~IORQ), BUS3.26 (~IORQ), J1.21, U1.40 (IN/OE2/GCK2)
/JTCK: J15.1, R11.2, U1.26 (B25/IO/JT.TCK)
/JTDI_CO: J15.6, R13.2, U1.1 (A4/IO/JT.TDI)
/JTDO_CI: J15.3, R10.2, U1.32 (B20/IO/JT.TDO)
/JTMS: J15.5, R12.2, U1.7 (A9/IO/JT.TMS)
/KBDATA: D2.1 (K), KBD1.2, KBD2.2, R7.1, R15.1
/KBDCLK: D2.2 (K), KBD1.3, KBD2.3, R8.1, R16.1
/KBDRDY: JP5.1 (A), U1.18 (BMC32/IO)
/M1-: BUS1.19 (~M1), BUS2.19 (~M1), BUS3.19 (~M1), J1.14
/MODINT-: J4.8, OP8.2 (C)
/MREQ-: BUS1.23 (~MREQ), BUS2.23 (~MREQ), BUS3.23 (~MREQ), J1.22
/NMI-: BUS1.66 (~NMI), BUS2.66 (~NMI), BUS3.66 (~NMI), J1.24
/P41: BUS1.41, BUS2.41, BUS3.41
/P44: BUS1.44, BUS2.44, BUS3.44
/P45: BUS1.45, BUS2.45, BUS3.45
/P46: BUS1.46, BUS2.46, BUS3.46
/P47: BUS1.47, BUS2.47, BUS3.47
/P48: BUS1.48, BUS2.48, BUS3.48
/P60: BUS1.60 (PAGE), BUS2.60 (PAGE), BUS3.60 (PAGE), OP9.1 (A)
/P61: BUS1.61 (CLK2), BUS2.61 (CLK2), BUS3.61 (CLK2)
/RD-: BUS1.25 (~RD), BUS2.25 (~RD), BUS3.25 (~RD), DISP1.6 (~RD), DISP2.5, J1.20, U1.38 (IN/OE1)
/RFSH-: BUS1.59 (~RFSH), BUS2.59 (~RFSH), BUS3.59 (~RFSH), J1.13
/RST-: BUS1.20 (~RESET), BUS2.20 (~RESET), BUS3.20 (~RESET), DISP1.9 (~RST), DISP2.8, J1.15, U1.39 (IN/GCLR)
/RX: BUS1.36 (RX), BUS2.36 (RX), BUS3.36 (RX), OP3.1 (A)
/RX2: BUS1.76 (RX2), BUS2.76 (RX2), BUS3.76 (RX2)
/SBCI0: OP5.1 (A), RN1.2 (R1), SW1.16
/SBCI1: OP6.1 (A), RN1.3 (R2), SW1.15
/SBCI2: OP7.1 (A), RN1.4 (R3), SW1.14
/SBC_I0: J4.2, OP5.2 (C)
/SBC_I1: J4.4, OP6.2 (C)
/SBC_I2: J4.6, OP7.2 (C)
/SBC_O0: J2.2, OP4.2 (C)
/SBC_O1: J2.4, OP3.2 (C)
/SBC_O2: J2.6, OP9.2 (C)
/SBC_O3: J2.8, OP2.2 (C)
/TX: BUS1.35 (TX), BUS2.35 (TX), BUS3.35 (TX), OP4.1 (A)
/TX2: BUS1.75 (TX2), BUS2.75 (TX2), BUS3.75 (TX2)
/USR4: BUS1.40 (USR4), BUS2.40 (USR4), BUS3.40 (USR4), OP2.1 (A), OP7.3 (B), OP9.3 (B)
/USR6: BUS1.78 (USR6), BUS2.78 (USR6), BUS3.78 (USR6), OP4.3 (B), OP5.3 (B)
/USR7: BUS1.79 (USR7), BUS2.79 (USR7), BUS3.79 (USR7), OP3.3 (B), OP6.3 (B)
/USR8: BUS1.80 (USR8), BUS2.80 (USR8), BUS3.80 (USR8), OP2.3 (B)
/VBUSPWR: OP1.3 (B), PWR1.A4_B9 (VBUS), PWR1.B4_A9 (VBUS)
/WAIT-: BUS1.65 (~WAIT), BUS2.65 (~WAIT), BUS3.65 (~WAIT), J1.17
/WR-: BUS1.24 (~WR), BUS2.24 (~WR), BUS3.24 (~WR), DISP1.5 (~WR), DISP2.4, J1.19, U1.35 (B17/IO/GCK3)
/ZIDPWR: J3.1, J3.2, J3.3, J3.4, J4.7, OP1.1 (A)
/ZINT2: BUS1.77 (~zINT2), BUS2.77 (~zINT2), BUS3.77 (~zINT2)
/ZIRQ1: BUS1.37 (~zIRQ1), BUS2.37 (~zIRQ1), BUS3.37 (~zIRQ1), OP8.3 (B)
GND: BUS1.17 (GND), BUS1.57 (GND), BUS2.17 (GND), BUS2.57 (GND), BUS3.17 (GND), BUS3.57 (GND), C1.2, C2.2, C3.2, C4.1, C5.1, C6.1, C7.1, D1.2 (A), D2.3 (A), DISP1.1 (F_GND), DISP1.2 (VSS), DISP1.21 (BLK/NC), DISP2.1, DISP2.20, J1.34, J1.36, J2.1, J2.3, J2.5, J2.7, J4.1, J4.3, J4.5, J15.2, KBD1.1, KBD2.1, PWR1.A1_B12 (GND), PWR1.B1_A12 (GND), R5.2, R6.2, R14.2, R17.2, SW1.1, SW1.2, SW1.3, SW1.4, SW1.5, SW1.6, SW1.7, SW1.8, U1.4 (GND), U1.16 (GND), U1.24 (GND), U1.36 (GND)
unnamed: JP1.1, R1.2
unnamed: JP3.1, R9.2
unnamed: LED1.1 (K), R17.1
unnamed: PWR1.SH1 (SHIELD), PWR1.SH2 (SHIELD), PWR1.SH3 (SHIELD), PWR1.SH4 (SHIELD), R14.1
unnamed: R3.2, RV1.3
unnamed: R5.1, RV1.1
unnamed: R15.2, U1.5 (A7/IO/PD1), U1.20 (BMC30/IO)
unnamed: R16.2, U1.13 (AMC14/IO), U1.37 (IN/GCK1)

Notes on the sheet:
1x22 Socket for Display Module or 2x10 Pin Header (for Ribbon Cable, w/Module pins 1&22 NC)

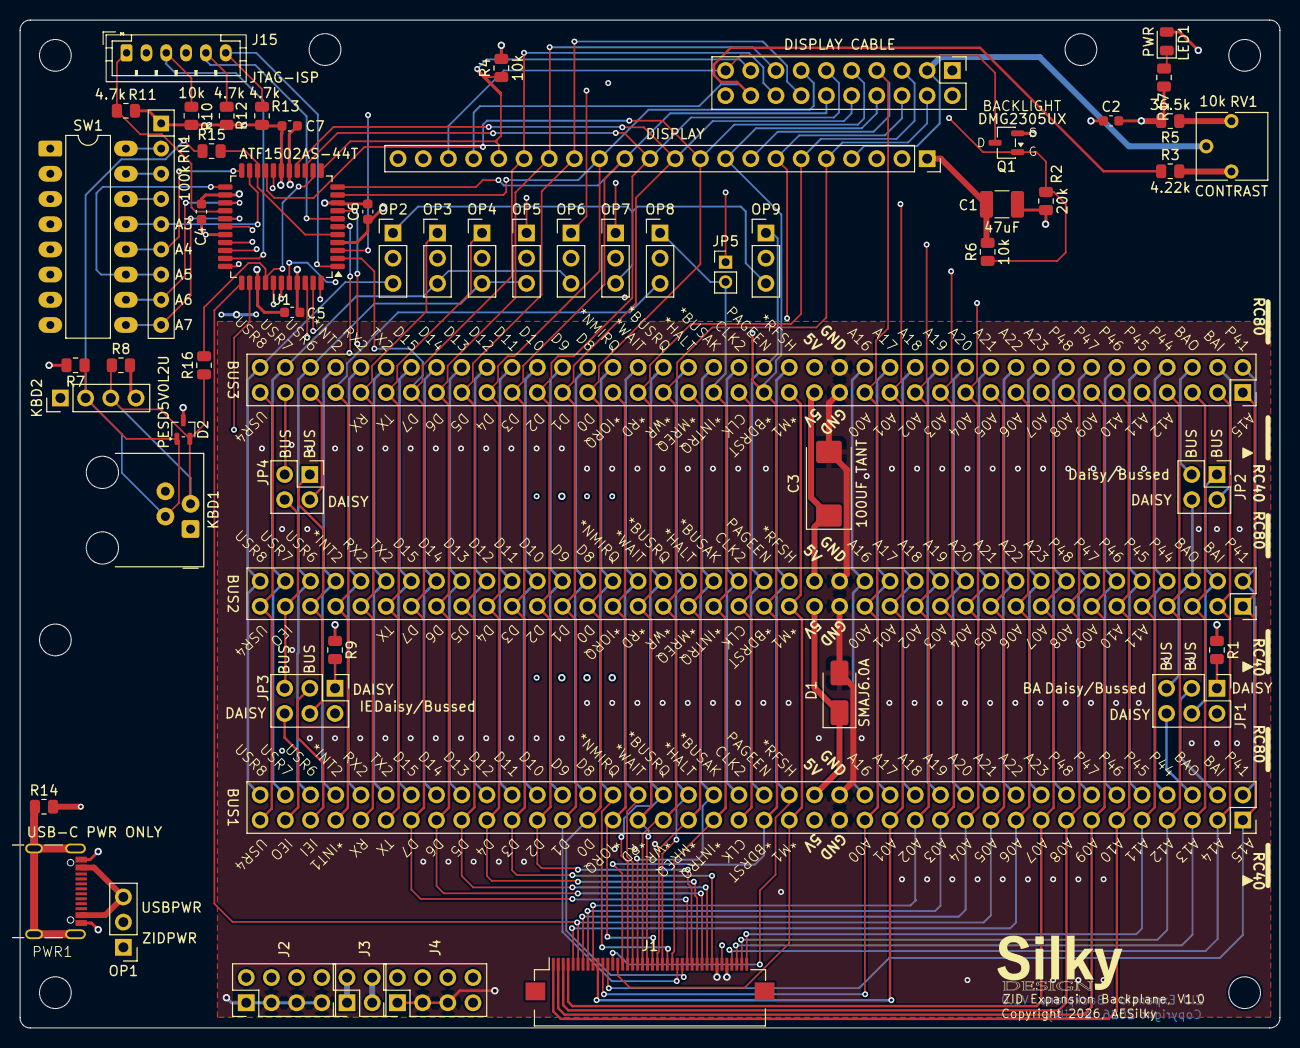
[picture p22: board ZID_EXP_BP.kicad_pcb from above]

Board: 4 copper layers, 127.0 x 101.6 mm, 66 parts (0 on the bottom side), 125 nets.

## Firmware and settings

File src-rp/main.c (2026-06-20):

/**
 * SD RP-Module for Bus Peripherals.
 *
 * Copyright 2023-26 AESilky
 * SPDX-License-Identifier: MIT License
 *
*/
#include "system_defs.h" // Main system/board/application definitions
//
#include "board.h"
#include "debug_support.h"
#include "multicore.h"
#include "picoutil.h"
#include "util.h"
//
#include "cmt.h"
#include "hwrt/hwrt.h"
//
#include "pico/binary_info.h"
#include "pico/status_led.h"

#include <stdio.h>


int main() {
    // useful information for picotool
    bi_decl(bi_program_description("SilkyDESIGN RP System Module w/ Debug Op Controller"));

    // Board/base level initialization
    if (board_init() != 0) {
        board_panic("Board init failed.");
    }

    // Initialize debug
    debug_init(DIM_BOOT);

    // Initialize the multicore subsystem
    multicore_modinit(debug_mode_enabled());

    // Initialize the Cooperative Multi-Tasking subsystem
    cmt_modinit();

    // Launch the Hardware Runtime (core-0 (endless) Message Dispatching Loop).
    // The HWRT starts the appropriate secondary operations (core-1 message loop)
    // (!!! THIS NEVER RETURNS !!!)
    start_hwrt();

    // How did we get here?!
    const char* errmsg = "DOC.main - Somehow we are out of our endless message loop in `main()`!!!";
    debug_trace(errmsg);
    error_printf(errmsg);
    // ZZZ Reboot!!!
    return 0;
}

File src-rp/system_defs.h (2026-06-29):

/*!
 * \brief Definitions for the hardware.
 * \ingroup board
 *
 * This contains most of the definitions for the board.
 * Some definitions that are truly local to a module are in the module.
 *
 * Copyright 2023-26 AESilky
 *
 * SPDX-License-Identifier: MIT
 */
#ifndef SYSTEM_DEFS_H_
#define SYSTEM_DEFS_H_
#ifdef __cplusplus
extern "C" {
#endif

#include "rppins.h"

#include "pico/stdlib.h"
#undef putc     // Undefine so the standard macros will not be used
#undef putchar  // Undefine so the standard macros will not be used

#include "hardware/gpio.h"
#include "hardware/pio.h"
#include "hardware/spi.h"
#include "hardware/uart.h"
#include "pico/multicore.h"

#define ADC_CHIP_TEMP           3               // Internal temperature sensor  (used with 'adc_select_input')

// SPI
//
// Note: Values (Pins) are the GPIO number, not the physical pins on the device.
//

// SPI for the SD Card.
//
#define SPI_SD_DEVICE           spi1            // Hardware SPI to use
#define SPI_SD_MISO             GP28
#define SPI_SD_MOSI             GP27
#define SPI_SD_SCK              GP26
#define SPI_SD_CS               GP17
#define SPI_SLOW_SPEED          (50 * 1000)     // Very slow speed for init ops
#define SPI_SD_SPEED            (800 * 1000)    // SPI at 800KHz
#define SPI_CS_ENABLE           0               // Chip Select is active LOW
#define SPI_CS_DISABLE          1               // Chip Select is active LOW

// Operations controlled directly by a GPIO
//
#ifndef CTRL_GPIOS          // Defaults for Control Pins
#define CRTL_GPIOS
#define CTRL_INTRQ              GP15            // Interrupt Request (ATTN) to main CPU
#define CTRL_INTRQ_OFF          0               //  Interrupt Request (ATTN) is Active-HIGH
#define CTRL_INTRQ_ON           1               //
#define CTRL_MODSEL             GP13            // ModuleSelect- from main CPU
#define CTRL_MOD_SELECTED       0               //  ModuleSelect is Active-LOW
#define CTRL_MOD_NOTSEL         1               //  ModuleSelect is Active-LOW
#define CTRL_ADDR               GP10            // C-/D from main CPU
#define CTRL_RD                 GP11            // RD- from main CPU
#define CTRL_WR                 GP12            // WR- from main CPU
#define CTRL_RD_ON              0               //  RD is Active-LOW
#define CTRL_RD_OFF             1               //  RD is Active-LOW
#define CTRL_WR_ON              0               //  WR is Active-LOW
#define CTRL_WR_OFF             1               //  WR is Active-LOW
#define CTRL_WAITRQ             GP14            // Wait Request to main CPU
#define CTRL_WAITRQ_OFF         1               //  Wait Request is Active-LOW
#define CTRL_WAITRQ_ON          0               //
#endif
// Data Bus
//
#ifndef DBUS_GPIOS          // Defaults for Data Bus Pins
#define DBUS_GPIOS
#define DATA0                   GP2
#define DATA1                   GP3
#define DATA2                   GP4
#define DATA3                   GP5
#define DATA4                   GP6
#define DATA5                   GP7
#define DATA6                   GP8
#define DATA7                   GP9
#define DATA_BUS_WIDTH          8
#define DATA_BUS_MASK           0x000003FC      // Mask to set all 8 bits at once: 0000 0000 0000 0000 0000 0011 1111 1100
#define DATA_BUS_SHIFT          2               // Shift to move an 8-bit value up/down to/from the DATA Bus
#endif

// PIO Blocks
//
#ifndef PIO_DEFS            // Defaults for PIO use
#define PIO_DEFS
#define PIOBLK_DBUS_AUTO        pio1            // PIO Block 1 is used for automatic databus control
#define PIO_BCA_MSEL_SM         0               // State Machine 0 is used to watch MOD_SEL-
#define PIO_BCA_DATA_SM         1               // State Machine 1 is used for DATA operations
#define PIOBLK_DBUS_MAN         pio0            // PIO Block 0 is used for manual databus reads/writes
#define PIO_BCM_OUT_SM          2               // State Machine 2 is used to manually transfer data out
#define PIO_BCM_IN_SM           3               // State Machine 3 is used to manually transfer data in
#define SYSIRQ_PIO_ACTRL        PIO1_IRQ_0      // PIO IRQ 0 used to signal Control Operation Request
#define SYSIRQ_PIO_ADATA_DR     PIO1_IRQ_1      // PIO IRQ 1 used to signal DATA-RD Data Needed
#define PIO_BCA_TOHOST_DREQ     DREQ_PIO1_TX1   // TXFIFO for reads from host
#define PIO_BCA_FROMHOST_DREQ   DREQ_PIO1_RX1   // RXFIFO for writes from host
#endif

// IRQ Inputs
//
// The data bus RD/WR uses PIO2 and DMA interrupts to process transfers
#define SYSIRQ_DMA_TF_PIO       DMA_IRQ_0       // System DMA IRQ-0 raised when DMA finishes PIO data transfer


// PWM - Used for a recurring interrupt for scheduled messages, sleep, housekeeping
//    RP2040 has 8 slices, RP2350 has 12. Use the last slice.
//
#if PICO_RP2350
#define CMT_PWM_RECINT_SLICE    11
#else
#define CMT_PWM_RECINT_SLICE     7
#endif

#ifdef __cplusplus
}
#endif
#endif // SYSTEM_DEFS_H_

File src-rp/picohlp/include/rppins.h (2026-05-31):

/*!
 * \brief RP2040 & RP2050 GPIO Pins.
 * @ingroup board
 *
 * The GPIO names to numbers for Pico, Pico2, and Adafruit KB2040.
 * The .
 *
 * Copyright 2023-26 AESilky
 *
 * SPDX-License-Identifier: MIT
 */
#ifndef RPPINS_H_
#define RPPINS_H_
#ifdef __cplusplus
extern "C" {
#endif

#define STRINGIFY_HELPER(x) #x
#define STRINGIFY(x) STRINGIFY_HELPER(x)

#if ADAFRUIT_KB2040
// ADAFRUIT_KB2040 PINS
//
// StemmaQT: 1=GND 2=3.3V 3=GP12(SDA0) 4=GP13(SCL0)
#define GP0     0       // Pin 2
#define GP1     1       // Pin 3
#define GP2     2       // Pin 6
#define GP3     3       // Pin 7
#define GP4     4       // Pin 8
#define GP5     5       // Pin 9
#define GP6     6       // Pin 10
#define GP7     7       // Pin 11
#define GP8     8       // Pin 12
#define GP9     9       // Pin 13
#define GP10    10      // Pin 14
#define GP11    11      // Button
#define GP12    12      // StemmaQT 3
#define GP13    13      // StemmaQT 4
//#define GP14    14      // NA
//#define GP15    15      // NA
//#define GP16    16      // NA
#define GP17    17      // NEOPIXEL
#define GP18    18      // Pin 17
#define GP19    19      // Pin 15
#define GP20    20      // Pin 16
//#define GP21    21      // NA
//#define GP22    22      // NA
#define GP26    26      // Pin 18
#define GP27    27      // Pin 19
#define GP28    28      // Pin 20
#define GP29    29      // Pin 21
#define RPADC0  GP26
#define RPADC1  GP27
#define RPADC2  GP28
#define RPADC3  GP29
#else
#define GP0     0       // Pin 1
#define GP1     1       // Pin 2
#define GP2     2       // Pin 4
#define GP3     3       // Pin 5
#define GP4     4       // Pin 6
#define GP5     5       // Pin 7
#define GP6     6       // Pin 9
#define GP7     7       // Pin 10
#define GP8     8       // Pin 11
#define GP9     9       // Pin 12
#define GP10    10      // Pin 14
#define GP11    11      // Pin 15
#define GP12    12      // Pin 16
#define GP13    13      // Pin 17
#define GP14    14      // Pin 19
#define GP15    15      // Pin 20
#define GP16    16      // Pin 21
#define GP17    17      // Pin 22
#define GP18    18      // Pin 24
#define GP19    19      // Pin 25
#define GP20    20      // Pin 26
#define GP21    21      // Pin 27
#define GP22    22      // Pin 29
#define GP23    23      // Controls Power Mode: 0=PFM 1=PWM
#define GP24    24      // Reads VBUS: 0=VBUS Absent 1=VBUS Present
#define GP25    25      // LED
#define GP26    26      // Pin 31
#define GP27    27      // Pin 32
#define GP28    28      // Pin 34
#define RPADC0  GP26
#define RPADC1  GP27
#define RPADC2  GP28
#define RPADC3  29      // ADC3 is used to detect 3.3V enabled
#endif

#ifdef __cplusplus
}
#endif
#endif // RPPINS_H_

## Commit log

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2026-03-16 CPLD testing #1
    [ZID_CPLD_TEST.kicad_pcb, ZID_CPLD_TEST.kicad_sch]
2026-03-27 CPLD: zsr, mmu, sbcgp, dbi working
    [ZID_CPLD_TEST.kicad_sch]
2026-03-29 CPLD tested break and reset
    [ZID_CPLD_TEST.kicad_sch]
2026-03-29 CPLD: Pins assigned
    [ZID_CPLD_TEST.kicad_sch]
2026-03-31 SCHM: Initial
    [ZID_MAIN.kicad_pcb, ZID_MAIN.kicad_sch, conn_exp.kicad_sch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]
2026-04-01 SCHM: Initial ERC passed
    [conn_exp.kicad_sch, zid_main_logic.kicad_sch]
2026-04-01 Only ignore PDF from PLD outputs
    [ZID_MAIN.kicad_sch, conn_exp.kicad_sch, hold.kicad_sch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]
2026-04-03 Pin-keeper on control, addr, and data. Refresh gated MREQ for debug.
    [zid_main_logic.kicad_sch]
2026-04-03 Update dates. Archive small break compare PAL.
    [ZID_MAIN.kicad_sch, conn_exp.kicad_sch, hold.kicad_sch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]
2026-04-04 Address pull-ups, small updates.
    [ZID_EXP_BP.kicad_pcb, ZID_EXP_BP.kicad_sch, ZID_MAIN.kicad_sch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]
2026-04-05 Add TP for open CPLD pins
    [ZID_EXP_BP.kicad_sch, ZID_POD.kicad_sch, conn_exp.kicad_sch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]
2026-04-05 8 output bits on RP. 10k PU for most. TVS.
    [ZID_EXP_BP.kicad_sch, ZID_MAIN.kicad_sch, conn_exp.kicad_sch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]
2026-04-06 U24 from LVC to AHCT for 5V
    [conn_exp.kicad_sch]
2026-04-07 Footprints assigned
    [conn_exp.kicad_sch, zid_main_logic.kicad_sch]
2026-04-07 Bypass caps
    [ZID_MAIN.kicad_sch, conn_exp.kicad_sch, hold.kicad_sch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]
2026-04-07 74LVC3G04, free up BUSACK_H and BUSACK_L.
    [ZID_MAIN.kicad_pcb, conn_exp.kicad_sch, zid_main_logic.kicad_sch]
2026-04-08 Break exp conn 2x20
    [ZID_MAIN.kicad_pcb, conn_exp.kicad_sch, zid_main_logic.kicad_sch]
2026-04-09 PCB comp place #1
    [ZID_MAIN.kicad_pcb, zid_main_logic.kicad_sch]
2026-04-10 PCB layout 2
    [ZID_MAIN.kicad_pcb, ZID_MAIN.kicad_sch, conn_exp.kicad_sch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]
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2026-04-12 PCB Main: layout 20250411a
    [ZID_MAIN.kicad_pcb, ZID_MAIN.kicad_sch, conn_exp.kicad_sch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]
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2026-04-13 POD PCB 4 layouts
    [ZID_POD.kicad_pcb, ZID_POD.kicad_sch]
2026-04-14 POD PCB increase GND trace width
    [Adapter-Body.stl, PLCC44-Probe-Adptr.stl, ZID_MAIN.kicad_pcb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]
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2026-04-16 BRK EXP initial schematic
    [PLCC44_Form1.stl, PLCC44_Form2.stl, ZID_BRK_EXP.kicad_pcb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]
2026-04-17 BP-EXP: 1 board only. PLCC-DIP: Adapter form.
    [PLCC44_Form2.3mf, ZID_BRK_EXP.kicad_sch, ZID_MAIN.kicad_pcb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]
2026-04-18 EXP-BP: Bypass caps, contrast R values
    [ZID_EXP_BP.kicad_sch, ZID_MAIN.kicad_pcb]
2026-04-18 Change ZID,POD,ExpBP connector to SIP
    [ZID_EXP_BP.kicad_sch, ZID_MAIN.kicad_sch, ZID_POD.kicad_sch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]
2026-04-19 Change bulk caps, J1 symbol
    [ZID_BRK_EXP.kicad_sch, ZID_EXP_BP.kicad_sch]
2026-04-20 ZID Main: TVS from SMC5.0 to SMA6.0
    [ZID_MAIN.kicad_pcb, ZID_MAIN.kicad_sch, conn_exp.kicad_sch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]
2026-04-21 74FCT541 to 74FCT2245. Move GND around CLK on ZID-POD connector
    [ZID_EXP_BP.kicad_sch, ZID_MAIN.kicad_sch, ZID_POD.kicad_sch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]
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2026-05-20 PLD: Work around Microchip negative logic issue. PCB add external break.
    [conn_exp.kicad_sch, zid_main_logic.kicad_sch]
2026-05-31 PLD: Replace LOW-TRUE pin terms with neg-logic
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2026-06-20 PLD: Positive ROM_SEL pin
    [ZID_MAIN.kicad_sch, zid_main_logic.kicad_sch]
2026-06-25 SCHM: Update CPLD pins and put all break units on board.
    [ZID_MAIN.kicad_sch, conn_exp.kicad_sch, hold.kicad_sch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]
2026-06-26 SCHM: Updates per SM
    [ZID_MAIN.kicad_sch]
2026-06-30 HW: Ready to lay out.
    [ZID_MAIN.kicad_pcb, ZID_MAIN.kicad_sch, ZID_POD.kicad_sch]
2026-07-02 PLD/SCHM: Move BRK Data & Don't-Care, GPIO, and TGT_GO count to 1504
    [ZID_MAIN.kicad_sch]
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2026-07-07 PLD SCHM: Switch 74FCT2257 w 74FCT2244. Reassign 1508 pins.
    [ZID_MAIN.kicad_sch]
2026-07-09 PLD: Update pins. SCHM: PLD pins, TCTRL correction.
    [ZID_MAIN.kicad_pcb, ZID_MAIN.kicad_sch]
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2026-07-12 PCB: All components placed V0.1
    [ZID_MAIN.kicad_pcb, ZID_MAIN.kicad_sch]
2026-07-16 SCHM: Updates per SM. PLD: comment corrections. PCB: start routing.
    [ZID_MAIN.kicad_pcb, ZID_MAIN.kicad_sch]
2026-07-17 SCHM/PCB: Small pin assignment changes on U15.
    [ZID_MAIN.kicad_pcb, ZID_MAIN.kicad_sch]
2026-07-17 PCB: AB+PCL pinout. Exp-BP add position.
    [ZID_EXP_BP.kicad_sch, ZID_MAIN.kicad_pcb, ZID_MAIN.kicad_sch]
2026-07-19 PCB layout progress before SRAM move. PLD: Allow upper-8 address only on BRK1.
    [ZID_EXP_BP.kicad_sch, ZID_MAIN.kicad_pcb, ZID_MAIN.kicad_sch]
2026-07-24 PCB: Save before 'rip-out' (3.5x5.0)
    [ZID_MAIN.kicad_pcb, ZID_MAIN.kicad_sch]
2026-08-03 PCB: Checkpoint... 349 nets left
    [ZID_MAIN.csv, ZID_MAIN.kicad_pcb, ZID_MAIN.kicad_sch]
2026-08-12 Checkpoint before removing JTAG-ISP Chain header (J15)
    [ZID_EXP_BP.kicad_sch, ZID_MAIN.kicad_pcb]
2026-08-12 Checkpoint after removing JTAG-ISP Chain header (J15)
    [ZID_MAIN.kicad_pcb, ZID_MAIN.kicad_sch]
2026-08-12 Checkpoint - Routing PWR/GND
    [ZID_MAIN.kicad_pcb, ZID_MAIN.kicad_sch]
2026-08-13 PCB: Routing of ZID-Main complete
    [ZID_MAIN.kicad_pcb, ZID_MAIN.kicad_sch]
2026-08-16 PCB: Expansion Backplane - Layout #1
    [ZID_EXP_BP.kicad_pcb]
2026-08-17 PCB: Ready to order - ZID, POD1, POD2, POD3, POD4, ExpBP
    [ZID_EXP_BP-B_Cu.gbr, ZID_EXP_BP-B_Mask.gbr, ZID_EXP_BP-B_Paste.gbr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]
2026-08-17 PCB: ExpBP, add power LED
    [ZID_EXP_BP-B_Cu.gbr, ZID_EXP_BP-B_Mask.gbr, ZID_EXP_BP-B_Paste.gbr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]
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2026-08-18 PLD Make: Add chip locations/descriptions. SCHM: Show designator.
    [ZID_EXP_BP.kicad_sch]
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2026-10-05 PCB: Change all SMD resistors to the same package.
    [ZID_EXP_BP.kicad_pcb, ZID_EXP_BP.kicad_sch, ZID_MAIN.kicad_pcb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]
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

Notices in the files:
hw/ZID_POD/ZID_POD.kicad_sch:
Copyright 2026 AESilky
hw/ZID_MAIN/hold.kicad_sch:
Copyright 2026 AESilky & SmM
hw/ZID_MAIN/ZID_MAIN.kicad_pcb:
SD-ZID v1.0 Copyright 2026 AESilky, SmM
